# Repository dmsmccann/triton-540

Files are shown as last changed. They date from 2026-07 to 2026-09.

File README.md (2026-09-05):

# Ten-Tec Triton IV Model 540 reconstruction

This project recreates the Ten-Tec Triton IV Model 540 in KiCad, one original
assembly at a time. The schematics preserve the historical topology and
reference designators while adding project-local SPICE models, reproducible
simulation studies, and explicit documentation of estimated values.

## Documented assemblies

| Assembly | Function | Documentation and simulation evidence |
|---|---|---|
| 80166 | Receiver RF amplifier | [80166.md](80166.md) |
| 80289 | Internal VFO and frequency conversion | [80289.md](80289.md) |
| 80287 | Receive/transmit mixers | [80287.md](80287.md) |
| 80279 | 9 MHz IF, AGC, product detector, and audio preamplifier | [80279.md](80279.md) |
| 80274 | Audio power amplifier, transmit mute, and CW sidetone | [Schematic](80274_audio_power_amp.kicad_sch); manual pp. 3-18 and 3-19; simulation not yet implemented |

The 80287 study demonstrates conversion between a 3.499 MHz SSB spectral
component and the fixed 9.001 MHz IF in both directions. It includes settled
MC1496 service-voltage comparisons, receive/transmit product plots, and
separate sweeps of the two mixer-balance controls.

The 80279 study documents the complete IF-to-audio and AGC signal path. Its
completed work includes the receive DC operating-point comparison, estimated
two-stage 9 MHz IF response, and open-loop PIN-diode attenuation sweep;
product-detector, closed-loop timing, and S-meter studies remain explicitly
listed as future simulations.

## Simulation

The KiCad hierarchy is the circuit source of truth. Reproducible runners,
curated measurements, plots, and project-local models are under [`spice/`](spice/README.md).
Generated netlists and simulator caches are intentionally not versioned.

## Bench measurement

Measurements taken on real hardware live under [`bench/`](bench/README.md),
one directory per assembly. Simulation evidence and bench evidence are kept
apart so that a simulated result is never mistaken for a measured one.

The original Ten-Tec service manual is the primary source for this
reconstruction but is not redistributed in this repository.

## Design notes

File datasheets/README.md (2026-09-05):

# Archived component datasheets

This directory holds project-local copies of documentation for obsolete and
historical components used in the Ten-Tec Triton IV Model 540 reconstruction.
KiCad symbols should point to these local files so the design does not depend
on external links remaining available.

## RCA 40823

- Used by: `80166` receiver RF amplifier (Q1) and `80279` 9 MHz IF
  amplifier stages
- File: `RCA_40823_SC-15_1971.pdf`
- Manufacturer: RCA Corporation, Solid-State Division
- Document: *RCA Transistor, Thyristor & Diode Manual*, Technical Series SC-15
- Original publication: 1971
- Extracted pages: printed pages 386 through 388 (40821, 40822, and 40823
  electrical data) and printed page 670 (JEDEC TO-72, RCA outline No. 28)
- Note: RCA specifies the 40823 as identical to the 40821 except for the listed
  ratings and characteristics, and refers to the 40822 for typical curves.
- Archive source:
  <https://www.worldradiohistory.com/BOOKSHELF-ARH/Technology/RCA-Books/RCA-Transistor-Thyristor-%26-Diode-Manual-1971.pdf>
- Archived file SHA-256:
  `AC18E00AAA3F6D3BE2EAAB2780D9C1DC1EC17F6025724F54BAAE7D126BE33B09`

## MC1747 / MC1747C

- Used by: `80279` AGC and audio preamplifier
- File: `MC1747_MC1747C_Motorola_1976.pdf`
- Manufacturer: Motorola Semiconductor Products Inc.
- Document: MC1747 / MC1747C dual operational amplifier, document DS 9254
- Original publication: 1976 Motorola Semiconductor Data Library, Volume 6,
  Series B, *Linear Integrated Circuits*
- Extracted pages: printed pages 3-83 through 3-86 (four-page device sheet)
- Archive source:
  <https://www.bitsavers.org/components/motorola/_dataBooks/1976_Motorola_Semiconductor_Data_Library_Volume_6_Series_B_Linear_Integrated_Circuits.pdf>
- Archived file SHA-256:
  `D2F00DBC59EEE32FA07F4A339DD53DEB0EA124C4779C71F2E761D8EE11318594`

## 80274 audio power amplifier

These archives support the parts shown on manual PDF page 35 / printed page 3-19.
The manufacturer documents are primary evidence; the hosting sites are archives.
Later datasheet revisions are identified below and are not proof of the production
lot or package revision fitted to this radio. No substitute parts are assigned.

### MPSU01 (Q74-1)

- File: [Motorola_MPSU01_TechnicalData_undated.pdf](Motorola_MPSU01_TechnicalData_undated.pdf)
- Manufacturer: Motorola Semiconductor Products
- Document: *MPS-U01 / MPS-U01A NPN Silicon Audio Transistors, Semiconductor Technical Data*
- Original publication: Undated original; scan creation date is not the publication year
- Extracted pages: Both device pages; case 152-02 and E-B-C lead numbering appear on page 1
- Used by: assembly 80274, Q74-1
- Archive source: <https://datasheet4u.com/pdf/505844/MPSU01.pdf>
- Archived file SHA-256: 36074E59597EBAD8F55A46C62B235A8F31B9F6712FD52B6E3EC39E4E847FE000

### MPS6514 (Q74-3)

- File: [Motorola_MPS6514_DeviceData_undated.pdf](Motorola_MPS6514_DeviceData_undated.pdf)
- Manufacturer: Motorola Semiconductor Products
- Document: *MPS6512 through MPS6519 Amplifier Transistor*
- Original publication: Undated device page; package supplement from 1991 DL126 Rev. 3
- Extracted pages: Device printed page 2-204; appended package/style page 8-2 (PDF page 837) from 1991 DL126 Rev. 3. Style 1 is 1=E, 2=B, 3=C; the later case 29-04 outline is supplementary, while the device page specifies case 29-02
- Used by: assembly 80274, Q74-3
- Archive source: <https://datasheet4u.com/pdf/1115234/MPS6514.pdf>
- Package supplement source: <https://www.bitsavers.org/components/motorola/_dataBooks/1991_DL126r3_Motorola_Small-Signal_Transistors_FETs_and_Diodes.pdf>
- Archived file SHA-256: E9A2791869ED3FDE04CC2622717A615A8F2C78B47AEB910D0CD93B5A73E7CB82

### 2N4870 (Q74-2)

- File: [Motorola_2N4870_ThyristorDeviceData_undated.pdf](Motorola_2N4870_ThyristorDeviceData_undated.pdf)
- Manufacturer: Motorola Semiconductor Products
- Document: *2N4870 / 2N4871 PN Unijunction Transistors, Thyristor Device Data*
- Original publication: Undated device pages; package supplement from 1991 DL126 Rev. 3
- Extracted pages: Device printed pages 3-22 through 3-26; appended package/style page 8-2 (PDF page 837) from 1991 DL126 Rev. 3. Case 29 style 9 is 1=B1, 2=E, 3=B2
- Used by: assembly 80274, Q74-2
- Archive source: <https://datasheet.octopart.com/2N4870-Motorola-datasheet-180793037.pdf>
- Package supplement source: <https://www.bitsavers.org/components/motorola/_dataBooks/1991_DL126r3_Motorola_Small-Signal_Transistors_FETs_and_Diodes.pdf>
- Archived file SHA-256: 3FBFE4898E3A0DED2CEFB50942763706FAECF680F558580B240C8897FA77EA2A

### LM380N (U74-1)

- File: [National_LM380_DS006977_2000.pdf](National_LM380_DS006977_2000.pdf)
- Manufacturer: National Semiconductor
- Document: *LM380 2.5W Audio Power Amplifier, DS006977*
- Original publication: August 2000
- Extracted pages: Source PDF pages 2 through 8 (manufacturer device pages 1 through 7, including the N14A DIP-14 package); distributor cover and final notes page omitted
- Used by: assembly 80274, U74-1
- Archive source: <https://datasheet.octopart.com/LM380N-National-Semiconductor-datasheet-7275687.pdf>
- Archived file SHA-256: 2A93CBCC4B527A974060AC2FE1396408B5B9E5A819E0162A482459EF5F6C0398

### 1N4154 (D74-1)

- File: [Fairchild_1N4154_DiscretePowerAndSignal_1998.pdf](Fairchild_1N4154_DiscretePowerAndSignal_1998.pdf)
- Manufacturer: Fairchild Semiconductor
- Document: *1N4154 High Conductance Fast Diode, Discrete Power and Signal Technologies*
- Original publication: Revision A, September 21, 1998 (copyright 1997)
- Extracted pages: Source PDF page 1, including DO-35 dimensions and cathode band; trademark page omitted
- Used by: assembly 80274, D74-1
- Archive source: <https://www.sm0vpo.com/_pdf/1N/1N4154.pdf>
- Archived file SHA-256: 0F6607CE3231C1A442E40ED800AEFC8D2FCE1A501A83BF57C706B4C019EE583B

### D74-2: documented value, unidentified device

The manual specifies only an **8.2 V Zener**. Manufacturer, part number,
power rating, and package are unknown. Its placed-symbol Datasheet field
therefore remains blank; linking a named replacement would misrepresent the
source. Its Evidence field records this limitation.

### LM380N / ULN2280B choice

The manual explicitly lists LM380N / ULN2280B. The schematic represents the
documented LM380N alternative with all 14 physical pins. Pins 9 and 13 are
internal NCs; pins 3, 4, 5, 7, 10, 11 and 12 are grounded. The local symbol
changes the drawing arrangement, not the pinout. The ULN2280B is noted as a
manual alternative, not silently substituted or modeled.

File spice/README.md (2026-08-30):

# SPICE assets

This directory separates reusable simulation source from study evidence and
disposable simulator output.

| Directory | Contents | Versioned |
|:--|:--|:--:|
| [`models/`](models/) | KiCad-facing subcircuits and model documentation | Yes |
| [`validation/`](validation/) | Small standalone regression circuits | Yes |
| [`tools/`](tools/) | Study runners, shared ngspice helpers, and plotting utilities | Yes |
| [`studies/`](studies/) | Curated CSV evidence, manifests, fixtures, and figures | Yes |
| `generated/` | Exported netlists, ngspice raw files, logs, caches, and temporary CSVs | No |
| `runtime/` | Local ngspice executable and runtime dependencies | No |

The KiCad schematics are the circuit source of truth. The 80166 runner exports
a fresh SPICE netlist from `triton_540.kicad_sch` before applying run-specific
parameters to a generated copy.

Each study has its own runner named for the assembly it exercises. Helpers
that are genuinely board-independent — reading an ngspice ASCII raw file,
converting a voltage ratio to decibels, and measuring a swept response for its
peak, its −3 dB bandwidth and its sample spacing — live in `tools/ngspice_raw.py`,
which every runner imports. A runner named for one assembly never provides
infrastructure to another.

Where several studies exercise the same board, that board's netlist editing lives
in one place: `tools/run_80166_headless.py` holds the 80166's parameter,
component, source and model-parameter edits, and the four new 80166 study runners
import it.

## Common commands

Run ngspice 46 outside KiCad through the project launcher:

```powershell
Push-Location spice\validation
& ..\tools\ngspice.cmd -b -D ngbehavior=ltpsa 40823_validation.cir
Pop-Location
```

The launcher prefers `spice/runtime/ngspice-46/bin/ngspice_con.exe`, then
checks `C:\Tools\ngspice-46\Spice64\bin` and `PATH`. The local runtime is
intentionally excluded from Git; simulation source and results remain
independently curated.

Check the project tools, KiCad exports, model regressions, and scanned-manual
toolchain without modifying source schematics:

```powershell
pwsh -File spice\tools\run_project_preflight.ps1
```

The preflight writes disposable BOMs, logs, rendered pages, and OCR output
below `spice/generated/preflight/`. Use `-SkipKicad`, `-SkipSpice`, or
`-SkipPdf` to omit a group.

Regenerate the documented 80166 figures:

```powershell
python spice\tools\plot_80166_manual_alignment.py
```

Run the 80166 studies from fresh KiCad exports. Each one exports the netlist,
applies its own state, runs ngspice, and rewrites its curated CSVs and figures:

```powershell
python spice\tools\run_80166_operation.py            # 3.5 MHz normal operation
python spice\tools\run_80166_defeat_gain.py          # DEFEAT gain reduction
python spice\tools\run_80166_rf_gain_supply.py       # RF GAIN as the stage supply
python spice\tools\run_80166_trap_9mhz.py            # 9 MHz trap
python spice\tools\run_80166_loading_sensitivity.py  # output loading and coil Q
```

The root schematic can only usefully simulate one assembly at a time. These
runners need the `RF_Amp_80166` sheet included in simulation and the other three
sub-sheets excluded, which is how `triton_540.kicad_sch` currently stands; a
runner stops with a clear message if the export contains no 80166 nets.

Run the 80287 receive/transmit conversion study and both mixer-balance sweeps:

```powershell
python spice\tools\run_80287_operation.py
python spice\tools\run_80287_rx_balance.py
python spice\tools\run_80287_tx_balance.py
```

Regenerate the settled 80287 MC1496 DC pin-voltage regression:

```powershell
python spice\tools\run_mc1496_dc_regression.py
```

Regenerate the 80289 frequency-plan and ten-meter alignment evidence from
fresh KiCad exports:

```powershell
python spice\tools\run_80289_frequency_plan.py
python spice\tools\run_80289_filter_ac_response.py
python spice\tools\run_80289_filter_response.py
python spice\tools\run_80289_output_loading.py
python spice\tools\run_80289_mixer_balance.py
python spice\tools\run_80289_crystal_injection.py
python spice\tools\run_80289_ten_meter_alignment.py
```

Run the final 29 MHz validation from a fresh KiCad export:

```powershell
python spice\tools\run_80166_headless.py `
  --tag final-29mhz-validation `
  --s4-pos 5 `
  --l-rack 1.4253u `
  --start 28.97Meg `
  --stop 29.03Meg `
  --points-per-decade 150000 `
  --set-component C13=5.787p
```

Generated output is written below `spice/generated/` and is intentionally
excluded from Git.

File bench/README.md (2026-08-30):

# Bench measurements

Measurements taken on real hardware, as opposed to the simulation evidence
under [`../spice/`](../spice/README.md). One directory per assembly, named by
its Ten-Tec assembly number.

| Assembly | Radio | Measurement | Status |
|---|---|---|---|
| [`80166/`](80166/) | Triton IV Model 540 | Receiver RF amplifier L1/L2 tracking on 80 m | Procedure written, sweeps not yet captured |
| [`80350/`](80350/) | **Model 544** | VFO mixer-balance adjustment of `R2 MIXER BAL.` | Complete |

The 80350 VFO belongs to a Ten-Tec Model 544, not to the Model 540 this
project reconstructs. It is kept here because the measurement technique and
instruments are the same, but its results are not evidence about the 540.

Each assembly directory holds its own procedure `README.md`, the capture and
plotting scripts, a `data/` directory holding the captured runs as the
measurement record, and a `plots/` directory for generated figures. Captured
data and plots are deliberately versioned; only tooling caches are ignored.

## Instrument control

The 80166 scripts drive a Siglent SDG1032X generator and SDS1202X-E
oscilloscope over LAN, using SCPI over VXI-11 through `pyvisa` + `pyvisa-py`,
so no NI-VISA installation is required:

```powershell
python -m pip install pyvisa pyvisa-py matplotlib
```

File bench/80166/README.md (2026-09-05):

# 80166 rf amplifier — L1/L2 tracking check on 80 m

Swept-frequency measurement of the receiver rf amplifier in the Ten-Tec Triton IV
Model 540, using a Siglent SDG1032X function generator and an SDS1202X-E
oscilloscope under Python control over LAN.

The point of the measurement is the one the factory alignment cares about: **do L1
and L2 peak at the same frequency as the RESONATE rack moves across 80 m?** The
manual sets tracking on this band only (p. 3-8, PDF p. 24) — the 3.5 MHz trimmer
and the L2 slug are the two adjustments, and the higher bands get trimmer-only
touch-ups afterwards with "no further adjustment of L2 necessary".

## How the two coils are separated

L1 (input) and L2 (output) sit either side of Q1, so a single sweep from the
antenna jack to the stage output shows the product L1 × Q1 × L2, not the two peaks
individually. The manual's own alignment trick splits them: the `.01 µF` clipped
from the band's trimmer terminal to chassis shorts the trimmer that sits **across
L2**, swamping the output tank.

| Run | `.01 µF` on the 3.5 MHz trimmer terminal | Curve shows |
|---|---|---|
| `l1-only` | fitted | L1 alone |
| `composite` | removed | L1 × Q1 × L2 |

On 3.5 MHz that trimmer is **C19**; the L1 side of the stage carries the fixed
620 pF C12 instead. The split — fixed capacitors across L1, adjustable trimmers
across L2 — is what makes this work, and is set out per band in
[`../../80166.md`](../../80166.md).

Overlay the two and the offset between their peaks is the tracking error.

> The manual writes this cap as ".01 mF". In 1978 US usage `mF`/`mfd` means
> **microfarad**; it is 0.01 µF, not a typo.

## Instruments

| Instrument | Address | Role |
|---|---|---|
| Siglent SDG1032X | `192.168.1.158` | stimulus, CH1 output |
| Siglent SDS1202X-E | `192.168.1.157` | CH1 = drive reference, CH2 = stage output |

Control is SCPI over VXI-11 via `pyvisa` + `pyvisa-py`, so no NI-VISA install is
needed:

```powershell
python -m pip install pyvisa pyvisa-py matplotlib
```

If VXI-11 gives trouble, `--transport socket` falls back to raw TCP
(scope 5025, generator 5024).

## Connections

Generator and scope CH1 both land on the antenna jack — that single node is where
the drive has to be measured. A BNC tee is the tidy way to do it, but tapping the
jack at two physical points works just as well at 3.5 MHz and needs no tee:

```text
  SDG1032X CH1 ──clip leads── SO-239 centre solder lug   (inside the rear apron)
                 (short, run together, ground clip to
                  chassis right at the jack)

  scope CH1 ──short coax──── 540 ANTENNA jack (SO-239)   1x direct, no probe

  scope CH2 ── x10 probe ── 80166 OUT pin                ground clip to nearest
                            (or 80287 "Rx In")           chassis point, short lead
```

- **Measure the drive, don't assume it.** The receiver input is not a flat 50 Ω
  across the sweep, so CH1 has to see the voltage that actually reaches the jack.
  That ratio is what makes the result a true transfer function.
- **Clip leads are fine here.** A few inches is about 100 nH, roughly 2 Ω at
  3.5 MHz against a 50 Ω source. Do not carry this arrangement up to 28 MHz.
- **Keep the CH1 coax short.** It is an unterminated stub into the scope's 1 MΩ
  input, so it hangs its own capacitance across the antenna input — RG-58 is
  about 100 pF/m. See the loading note below.
- **CH1 is a direct coax feed**, so run the script with `--ch1-attn 1` (the
  default). CH2 uses a ×10 probe, `--ch2-attn 10` (also the default). A ×10 probe
  on CH1 would load less but divides the 10 mVpp reference down to two divisions
  on screen; the direct feed gives a much cleaner reference and is the better
  trade.
- **Do not disturb the hookup between the two sweeps.** Same cable, same clip
  positions, same routing for `l1-only` and `composite`.
- **CH2 pickup point.** The 80166 `OUT` pin goes to `S4B` and on to the TX-RX
  mixer. The `Rx In` pin on the 80287 plug-in socket is the same net and is
  usually easier to reach. Access to the rf amp itself is on the RESONATE
  subchassis with the rack plate off (Figure 1, p. 3-6).
- The 9 MHz trap T1/C7 is in the input path but is irrelevant at 3.5–4.0 MHz.

### Transceiver settings

| Control | Setting |
|---|---|
| Antenna | **disconnected** — the generator is on that jack |
| T/R-REC switch | **T/R** |
| BAND | 3.5 MHz |
| MODE | SB-N, receive, PTT open, key up |
| RF GAIN | **fully clockwise** (this is the supply to the stage) |
| CALIBRATE | **OFF** — the calibrator's TTL gate pulls DEFEAT low and drops stage gain ~25 dB |
| Blanker | off |
| RESONATE | continuous and unmarked; peak it as described below, then **do not touch it** for the rest of that pair of sweeps |

> **Do not transmit.** The generator is connected to the antenna jack; keying the
> transmitter will destroy the SDG output stage. Keep the unit in receive
> throughout, key unplugged, mic unplugged.

## Run order

The RESONATE position is part of the measurement — L1 and L2 are ganged to the
same rack, so the sweep only tells you about tracking at the physical rack
position you left it in. The front-panel control has no scale or detents, so do
not try to record a dial setting; take both sweeps of a pair without moving it.

1. Clip the `.01 µF` from the 3.5 MHz trimmer terminal — C19, on the small
   trimmer board beneath the amplifier board, Figure 2, p. 3-7 — to chassis.
2. Set RESONATE for peak response at 3.5 MHz. Easiest way is to run a quick
   coarse sweep and adjust until the peak lands on 3.5 MHz:

   ```powershell
   python bode_80166.py --label l1-only --points 61 --note "RESONATE set for 3.5 MHz peak"
   ```

3. When the peak is on 3.5 MHz, take the reference sweep at full resolution:

   ```powershell
   python bode_80166.py --label l1-only --note "RESONATE at 3.5 MHz peak, .01uF fitted"
   ```

4. Remove the `.01 µF`. **Leave RESONATE alone.** Take the composite sweep:

   ```powershell
   python bode_80166.py --label composite --note "RESONATE unchanged, .01uF removed"
   ```

5. Overlay them:

   ```powershell
   python plot_bode.py data/80166-80m-l1-only-*.csv data/80166-80m-composite-*.csv
   ```

If the composite peak is off 3.5 MHz, adjust the **3.5 MHz trimmer C19** and repeat
step 4. The 4.0 MHz end of the tracking is then set with the **L2 slug** — repeat
the whole pair with RESONATE peaked at 4.0 MHz instead, and adjust the slug rather
than the trimmer. Iterate the two ends as the manual's step 6 says, since each
interacts with the other.

## Reading the result

- **Tracking well** — the composite peak sits on the L1 peak, the composite curve
  is a single symmetric hump, and its peak gain is the highest you can obtain by
  touching the trimmer.
- **Mistracked** — the composite peak is offset from L1's, or the curve is
  broad/flat-topped/double-humped, and peak gain is down. The sign of the offset
  tells you which way to move the trimmer or slug.

`plot_bode.py` reports peak frequency, −3 dB bandwidth, loaded Q, the gain at each
alignment point, and the peak offset between the two curves.

## Measurement notes and limits

- **Drive level.** Default is 10 mVpp, which is ~60 dB above what this front end
  normally sees, chosen so the output clears the scope's noise floor. The script
  runs a linearity check first: it measures gain at full and half drive and warns
  if they differ by more than 0.5 dB, which means Q1 is compressing and the curve
  shape is lying. Reduce `--amplitude` until it passes.
- **Probe loading.** A ×10 probe adds roughly 10–15 pF at the output node. On 80 m
  that is small against the several hundred pF resonating L2, so the shift is
  tolerable — this is exactly why the check is worth doing on this band and not on
  28 MHz, where the same 10 pF would dominate. Confirm the final peak with the
  manual's audio-AC-meter method if you want the probe out of circuit.
- **Dynamic range.** At the scope's most sensitive setting the usable range is
  roughly 30–35 dB below the peak before the skirts sink into the noise. The
  script records the CH2 noise floor with the generator output off in the CSV
  header so you can see where the data stops being meaningful.
- **Amplitude only.** Phase is not recorded. Tracking is an amplitude question and
  leaving phase out removes a large source of measurement fragility.
- The scope's 20 MHz bandwidth limit is enabled by default to cut noise;
  `--no-bwl` turns it off.

## Files

| File | Purpose |
|---|---|
| `bode_80166.py` | runs one sweep, writes a timestamped CSV to `data/` |
| `plot_bode.py` | overlays CSVs, writes a PNG to `plots/`, prints the summary table |
| `data/` | captured sweeps, one CSV per run, kept as the measurement record |
| `plots/` | generated figures |

CSV columns are `frequency_hz, ch1_vpp, ch2_vpp, gain_db`, preceded by `#`
comment lines carrying the run label, instrument IDNs, drive level, sweep
settings, measured noise floor, linearity result and the free-text `--note`.

## Results

Not yet captured — this section will be filled in with the overlay plot and the
summary table once the sweeps have been run on the bench.

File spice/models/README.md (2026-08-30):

# SPICE model reference

## MC1747 dual operational amplifier

`MC1747.sub` contains a five-terminal Motorola-style MC1747 op-amp core and
a project-added fourteen-pin package wrapper. The wrapper instantiates the
core twice, preserving the device's separate positive supplies and common
negative supply:

```spice
XU inv_a noninv_a off_a1 vee off_b1 noninv_b inv_b off_b2 vcc_b out_b nc out_a vcc_a off_a2 MC1747
```

Use a one-to-one physical-pin mapping in KiCad:

| Pin | Function | Pin | Function |
|---:|---|---:|---|
| 1 | Inverting input A | 8 | Offset adjust B |
| 2 | Noninverting input A | 9 | VCC B |
| 3 | Offset adjust A | 10 | Output B |
| 4 | VEE, common | 11 | NC |
| 5 | Offset adjust B | 12 | Output A |
| 6 | Noninverting input B | 13 | VCC A |
| 7 | Inverting input B | 14 | Offset adjust A |

The `triton_iv:MC1747` symbol already selects
`${KIPRJMOD}/spice/models/MC1747.sub`, subcircuit `MC1747`, with physical
pins 1 through 14 mapped one-to-one.

### Model basis and limits

The five-pin core was extracted from the local KiCad-Spice-Library file
`Models/uncategorized/spice_complete/MOTOR.LIB`, whose source tag identifies
the entry as a Motorola internally compensated MC1747 model. The same
electrical core appears as `MC1747` in the Bordodynovs `OPAMPS.LIB` and as
`MC1747_MC` in `m_opamp.lib`.

The source core models one amplifier only. The project modification renames
it `MC1747_CORE`, instantiates it once for section A and once for section B,
and adds high-value stabilization resistors to the four offset-adjust pins
and pin 11. Consequently, offset-null adjustment is not modeled. DC bias,
closed-loop gain, bandwidth, slew rate, output limiting, input bias current,
and supply loading are modeled nominally; noise, device spread, temperature
variation, and inter-section coupling are not validated.

`../validation/MC1747_validation.cir` checks both sections on separate 13.8 V
positive-supply pins. Its unity-follower regression gives 6.80002 V and
7.00002 V DC outputs, approximately 1.595 MHz closed-loop bandwidth, and
0.498 V/us large-signal slew rate under ngspice 46.

The source aggregator's README states that its GPLv3 license covers its
scripts, not the collected model files, and it does not establish the license
of this individual model. Treat `MC1747.sub` as a local simulation asset and
review or replace it before including it in a public release.

### References

- Ten-Tec, *Triton IV Model 540 Owner's Manual*, local PDF page 32 / printed
  page 3-16: the two IC-1 amplifier functions on assembly 80279.
- Same manual, local PDF page 33 / printed page 3-17: IC-1 connections and
  operating-point voltages.
- `datasheets/MC1747_MC1747C_Motorola_1976.pdf`, printed pages 3-83 through
  3-86: package pinout and electrical characteristics.

## 80279 discrete active-device models

`MPS3693.lib` is an empirical NPN model for Q79-1 and Q79-2. No factory
SPICE model was found. Its constraints are the surviving 45 V voltage
ratings, 30 mA collector-current rating, minimum gain of 40, approximately
200 MHz transition frequency, and approximately 3.5 pF collector
capacitance. `BF=60` was selected as a nominal value compatible with the
manual's approximately 1.3 mA and 5 mA emitter-current operating points.
The model is intended for 9 MHz bias and small-signal studies, not noise,
distortion, breakdown, temperature, or production-spread predictions.

`HP5082_3379.sub` is an empirical two-terminal PIN-diode model for D79-1,
D79-2, and D79-3. Its external order follows the KiCad diode symbol:

```spice
XD cathode anode HP5082_3379
```

The model uses the HP/Agilent data-sheet values of 50 V minimum breakdown,
0.4 pF maximum total capacitance at 50 V, 1.3 us typical carrier lifetime,
and typical Outline-15 package parasitics of 2.5 nH and 0.13 pF. A
low-pass-controlled behavioral resistance follows the documented
current-controlled RF resistance without following the 9 MHz carrier. Its
8 mV/current relationship gives approximately 1000 ohms at 10 uA and 8 ohms
at 1 mA; this is an engineering interpolation, not an HP compact model.

`../validation/80279_device_models_validation.cir` gives nominal ngspice 46
results of beta 55.4 for MPS3693 at 50 uA base drive. In the documented
80279 bias networks it gives Q79-1 C/B/E = 13.64/1.046/0.362 V and Q79-2
C/B/E = 13.32/1.788/1.070 V, compared with manual readings of
13.7/1.0/0.3 V and 13.3/1.8/1.1 V. The PIN-diode impedance magnitudes are
802 ohms, 8.22 ohms, and 0.611 ohm at 9 MHz for 10 uA, 1 mA, and 20 mA
forward bias respectively.

The existing `MPS6514.lib` model is assigned to Q79-4, Q79-5, and Q79-6.
The existing `40823.sub` model is assigned to Q79-3 with one-to-one physical
pin order `D, G2, G1, S`. The complete assignments are stored directly in
`80279_if_agc.kicad_sch` so KiCad exports all required includes.

### References

- Ten-Tec, *Triton IV Model 540 Owner's Manual*, local PDF pages 32-33 /
  printed pages 3-16 to 3-17: circuit functions and no-signal voltages.
- HP/Agilent, *PIN Diodes for RF Switching and Attenuating*, technical data
  5968-7182E: 5082-3379 capacitance, lifetime, breakdown, package parasitics,
  and RF-resistance behavior.

## MC1496P balanced modulator

`MC1496P.sub` is a nominal transistor-level model for the MC1496P
double-balanced mixers used as U89-1 in VFO assembly 80289 and U87-1/U87-2
in TX-RX mixer assembly 80287.
It implements the onsemi internal topology: a four-transistor upper switching
quad, a two-transistor signal stage, two emitter-degenerated current-source
transistors, and the bias diode. The bias diode is represented electrically by
a diode-connected NPN. Figure 23 shows three internal 500 ohm resistors.

The subcircuit exposes all fourteen physical package pins:

```spice
XU signal+ gain1 gain2 signal- bias output+ nc carrier+ nc carrier- nc output- nc vee MC1496P
```

Use a one-to-one physical-pin mapping in KiCad:

| Pin | Function | Pin | Function |
|---:|---|---:|---|
| 1 | Signal input + | 8 | Carrier input + |
| 2 | Gain adjust | 9 | NC |
| 3 | Gain adjust | 10 | Carrier input - |
| 4 | Signal input - | 11 | NC |
| 5 | Bias | 12 | Output - |
| 6 | Output + | 13 | NC |
| 7 | NC | 14 | VEE |

In KiCad Simulator, associate U89-1 with a **Subcircuit** model, browse to
`${KIPRJMOD}/spice/models/MC1496P.sub`, select `MC1496P`, and map physical
pins 1 through 14 one-to-one. The four NC pins are accepted by the subcircuit
but intentionally unused internally.

### Model basis and limits

- The topology and internal 500 ohm resistors are documented in onsemi
  MC1496/D Figure 23.
- The transistor beta, Early voltage, and capacitance terms are engineering
  fits to the data sheet's typical 12 uA input bias current, 40 kohm output
  resistance, 5 pF output capacitance, and published RF response. They are not
  a recovered Motorola semiconductor-process model.
- A fixed 0.2 percent mismatch in one switching transistor makes the external
  mixer-balance control produce a finite null. This is a nominal simulation
  device mismatch, not a measured value for U89-1.

The model is intended for DC bias, conversion-gain trends, carrier balance,
injection-level studies, wanted/unwanted mixing products, and loading of the
80289 output filters from 5 to 21 MHz. It is not validated for absolute noise,
unit-to-unit spread, temperature drift, exact intercept points, or carrier
feedthrough caused by physical PCB coupling.

The settled schematic-native 80287 DC regression passes 33 of the 40 connected-
pin/mode checks against the manual's stated 15 percent service tolerance. All
U87-1 transmit points and every U87-2 point pass. Seven U87-1 receive points
remain outside tolerance, while its two collector voltages pass. Because the
same model reproduces U87-2 pin 5 but cannot simultaneously reproduce the
documented U87-1 pin-5 value with the drawn R87-3 network, no global transistor
parameter was fitted to those seven points. Absolute gain, balance, and
feedthrough remain unvalidated.

`../validation/MC1496P_validation.cir` checks DC operating current and
5 MHz by 8 MHz mixer action with 3 MHz and 13 MHz differential outputs, then
repeats at a 15 MHz carrier to check 10 MHz and 20 MHz products near the top
of the 80289 operating range.

`../tools/run_mc1496_dc_regression.py` exports the complete KiCad hierarchy,
allows the 80287 bias capacitors to settle for 500 us, and compares all 40
documented U87-1/U87-2 operating points. Add `--strict` when a nonzero exit is
desired for any out-of-tolerance manual point.

### References

- Ten-Tec, *Triton IV Model 540 Owner's Manual*, local PDF page 29 / printed
  page 3-13: U89-1 circuit connections and external bias network.
- Same manual, local PDF pages 27-28 / printed pages 3-11 to 3-12:
  mixer-balance, crystal-injection, and output-filter alignment.
- onsemi, [MC1496/MC1496B data sheet](https://www.onsemi.com/download/data-sheet/pdf/mc1496-d.pdf):
  pinout, internal circuit, operating equations, test circuits, impedance,
  frequency response, and mixer applications.

## TX-RX mixer 80287 magnetics

`80287_txrx_magnetics.lib` contains `TXRX_L2_CT`, the simulation starting
model for the center-tapped transmit-output transformer L87-2. It uses two
10 uH halves, 1 ohm winding resistance in each half, coupling `K=0.98`, and
2 pF end-to-end capacitance.

The Ten-Tec manual shows the winding topology but supplies none of those
quantities. They are explicit estimates chosen to make the schematic runnable,
not recovered factory specifications. L87-2 needs measurement or original
winding information before the model can support absolute output-level or
balance claims.

The receive load L87-3 is represented directly in the schematic as 2 uH. This
is the rounded result of resonating the documented C87-5 value of 150 pF at
9 MHz (2.08 uH before transistor, board, and winding capacitance). L87-1 is a
1 uH inferred starting value and likewise remains unverified.

## RCA 40823 dual-gate MOSFET

`40823.sub` is an empirical four-terminal macro-model for the RCA 40823
protected dual-gate N-channel depletion MOSFET used as Q66-1 in the Triton 540
RF amplifier.

The subcircuit call is:

```spice
XQ drain gate2 gate1 source RCA40823
```

The custom project symbol is drawn using pin positions that do not correspond
to its displayed pin names.  For the existing `80166_rf_amp.kicad_sch`
connections, map the symbol pins to the subcircuit as follows:

| KiCad symbol pin | Circuit terminal | Subcircuit node |
|---:|---|---:|
| 1 | Drain | 1 |
| 3 | Gate 2 / DEFEAT bias | 2 |
| 4 | Gate 1 / tuned-input tap | 3 |
| 2 | Source / R6-C5 | 4 |

In KiCad Simulator, select Q66-1, choose a **Subcircuit** model, browse to
`${KIPRJMOD}/spice/models/40823.sub`, select `RCA40823`, and use the mapping
`1=1 2=4 3=2 4=3` already stored on Q66-1.  This produces the subcircuit
order drain, gate 2, gate 1, source.

### Model basis and limits

No RCA factory SPICE model was found. The DC and capacitance targets are based
on published 3N204/NTE222 data, a documented close replacement for the 40823:
6-30 mA IDSS, 10-22 mS forward transfer admittance, 3.3 pF typical input
capacitance, 0.005-0.03 pF reverse transfer capacitance, and 1.4 pF typical
output capacitance at the stated test biases.

This nominal model is intended for bias checks, gain-control trends, and
small-signal work across the Triton's 2-30 MHz receiver range. It is not
validated for noise figure, strong-signal IMD, temperature extremes,
manufacturing spread, or VHF/UHF S-parameters. Measurements from an original
40823 would be required to fit those behaviors.

`../validation/40823_validation.cir` provides standalone ngspice DC transfer
sweeps.

### References

- Ten-Tec, *Triton IV Model 540 Owner's Manual*, local PDF page 25 / printed
  page 3-9: Q1 identity, D/G2/G1/S pin order, and receive/transmit voltages.
- NTE Electronics, [NTE222 datasheet](https://www.tme.eu/Document/55128e117c9002a9dd7c0a2ab56da1a3/nte222.pdf):
  DC limits, forward transfer admittance, capacitances, and protected-gate
  characteristics.
- Motorola, [3N204/3N205 data](https://www.tvsat.com.pl/pdf/3/3n204-5_mot.pdf):
  depletion-mode topology and matching DC/RF characteristic limits.

## RF-amplifier magnetics

`80166_rf_magnetics.lib` supplies three parameterized ngspice
subcircuits:

| Model | Pins | Default starting values |
|---|---|---|
| `80166_L1` | band end, RF ground, antenna tap, G1 tap | 2.2 uH full winding, 6 pF parasitic |
| `80166_L2` | DC end, band end, output tap, drain tap | 2.2 uH full winding, 6 pF parasitic |
| `80166_T1_9MHZ` | primary A/B, secondary A/B | 0.35 uH : 12.5 uH, K=0.35 |

L1 and L2 are both modeled as strongly coupled series sections, not as
isolated transformer windings.  This preserves their continuous
double-tapped-winding topology while allowing every schematic tap to be
connected.

The L1/L2 `LT` parameter is the full-winding value at the current RESONATE
control position.  Use 2.2 uH as a nominal starting point and sweep about
1.7-3.3 uH.  The T1 defaults resonate near 9 MHz when the external C7 is about
20 pF; its 5 pF default `CPS` parameter represents estimated secondary,
wiring, and socket capacitance.

Example explicit instances are:

```spice
X_L1 band_end 0 ant_tap g1_tap 80166_L1 params: LT=2.2u
X_L2 dc_end band_end out_tap drain_tap 80166_L2 params: LT=2.2u
X_T1 primary_a primary_b secondary_a secondary_b 80166_T1_9MHZ
```

In KiCad Simulator, associate each custom symbol with a **Subcircuit** model,
browse to `${KIPRJMOD}/spice/models/80166_rf_magnetics.lib`, select the matching
subcircuit, and use a 1:1 model-pin mapping:

| Reference | KiCad/model pin 1 | Pin 2 | Pin 3 | Pin 4 |
|---|---|---|---|---|
| L66-1 / L1 | band/S4A | RF ground | antenna/T1 tap | C2/G1 tap |
| L66-2 / L2 | DC/C6 end | band/S4B | OUT tap | drain/gimmick tap |
| T66-1 / T1 | primary A | primary B | secondary A | secondary B |

### Evidence and limitations

- Ten-Tec, *Triton IV Model 540 Owner's Manual*, local PDF page 24 / printed
  page 3-8: L1/L2 slug tuning, mechanical ganging, and T1/C7 trap function.
- Same manual, local PDF page 25 / printed page 3-9: winding and tap topology.
- Same manual, local PDF page 21 / printed page 3-4: L1 band capacitors of
  620, 220, 56, 22, and 10 pF and five 5-60 pF L2 trimmers.

The manual does not document inductance, turns, tap ratios, coupling, Q, or
parasitic capacitance.  The model defaults are calculated/inferred starting
values, not Ten-Tec specifications.  Refine `LT`, tap fractions, `KTRAP`,
`QP`/`QS`, and parasitics from an original assembly or a measured response.
`../validation/80166_rf_magnetics_validation.cir` is a standalone AC fixture
for syntax and trap-response checks. The complete manual-alignment study is
documented in `../studies/80166/manual-alignment/`.

## Ganged S4A/S4B five-position rotary switches

`SW_Rotary_1x5.sub` is a parameter-selected SP5T model used by both the S4A
and S4B bandswitch wafers.  Each instance has the following pin order:

| Model pin | Switch terminal |
|---:|---|
| 1-5 | Five stationary contacts |
| 6 | Common/wiper |

The model uses a 20 milliohm resistance for the selected contact and 1 teraohm
for each unselected contact.  These are stable simulation defaults, not
measurements of the original switch.  Contact capacitance, inductance,
break-before-make motion, and contact bounce are not modeled.

In KiCad, associate both wafers with a **Subcircuit** model, browse to
`${KIPRJMOD}/spice/models/SW_Rotary_1x5.sub`, select `SW_ROTARY_1X5`, and map pins
1 through 6 one-to-one.  Both model instances use the same parameter:

```spice
POS={S4_POS}
```

The top-sheet SPICE directive is:

```spice
.param S4_POS=1
```

Change the integer from 1 through 5 to select a contact, then rerun the
simulation.  Because S4A and S4B reference the same parameter, both wafers
move together.  The present S4A drawing maps the switch contacts as:

| `S4_POS` | Band label | Capacitor |
|---:|---:|---:|
| 1 | 3.5 MHz | 620 pF |
| 2 | 7 MHz | 220 pF |
| 3 | 14 MHz | 56 pF |
| 4 | 21 MHz | 22 pF |
| 5 | 28 MHz | 10 pF |

The S4B output networks use C19, C17, C16, C15, and the C13-C14 series pair.
Their fitted simulation values and the distinction between documented
trimmer range and inferred parasitics are recorded in the manual-alignment
study rather than in this model description.

`../validation/SW_Rotary_1x5_validation.cir` instantiates the model in all
five positions and checks that only the selected throw conducts.

## Ganged S89-1 four-pole, five-position VFO bandswitch

`SW_Rotary_4x5.sub` models the four mechanically linked wafers of S89-1 as
one 24-pin subcircuit.  Its pins map one-to-one to the project-local symbol:

| Model pins | VFO switch terminals |
|---:|---|
| 1-5, 6 | A1-A5, A common |
| 7-11, 12 | B1-B5, B common |
| 13-17, 18 | C1-C5, C common |
| 19-23, 24 | D1-D5, D common |

All four wafers use the same `POS` parameter.  The S89-1 schematic instance
passes `POS={S4_POS}`, so the root-sheet directive that controls S4A and S4B
also controls the VFO bandswitch:

| `S4_POS` | Amateur band | Nominal band frequency |
|---:|---:|---:|
| 1 | 80 m | 3.5 MHz |
| 2 | 40 m | 7 MHz |
| 3 | 20 m | 14 MHz |
| 4 | 15 m | 21 MHz |
| 5 | 10 m | 28 MHz |

The model uses the same 20 milliohm selected-contact resistance and 1 teraohm
unselected-contact resistance as the S4 model.  It does not model contact
parasitics, break-before-make motion, or contact bounce.

`../validation/SW_Rotary_4x5_validation.cir` checks every wafer in all five
positions.

## S5 four-position ten-meter segment switch

`SW_Rotary_1x4.sub` models the top-sheet S5 SP4T selector. Model pins 1–4
map one-to-one to the four crystal contacts and pin 5 is the common/wiper
connected to the VFO sheet's `S5` input. The schematic instance passes:

```spice
POS={S5_POS}
```

The root-sheet directive defaults to `.param S5_POS=1`. Positions 1–4 select
Y1 through Y4:

| `S5_POS` | Dial segment | Ideal source |
|---:|:--|--:|
| 1 | 28.0–28.5 MHz | Y1, 13.99 MHz |
| 2 | 28.5–29.0 MHz | Y2, 14.49 MHz |
| 3 | 29.0–29.5 MHz | Y3, 14.99 MHz |
| 4 | 29.5–30.0 MHz | Y4, 15.49 MHz |

The four frequencies are the documented 10 kHz-low crystal plan combined
with the band-dependent PTO correction. Y1–Y4 are functional ideal sine
sources with 2.2 V DC bias and 1 V peak amplitude, matching the ideal-source
convention used for Y89-1 through Y89-3. They do not model crystal startup,
motional parameters, loading, or production tolerance.

The switch uses 20 milliohms for the selected contact and 1 teraohm for each
unselected contact. These are stable simulation defaults, not measurements.
`../validation/SW_Rotary_1x4_validation.cir` checks all four positions.

## Fixed-position potentiometer

`Potentiometer_Position.sub` represents a three-terminal linear
potentiometer at a fixed simulation setting. Its model pins are terminal 1,
wiper 2, and terminal 3. The instance parameters are:

```spice
R=1k POS=0.5
```

`POS=0` places the wiper at terminal 1 and `POS=1` places it at terminal 3.
A 1 milliohm minimum segment resistance avoids a zero-ohm branch at either
endpoint.

The 80289 schematic uses this model only for the two alignment controls.
R89-2 has `POS={VFO_R2_POS}`, with the saved
`.param VFO_R2_POS=0.760`; R89-27 has `POS={VFO_R27_POS}`, with the saved
`.param VFO_R27_POS=0.100`. The dedicated mixer-balance sweep places the
R89-2 minimum at 0.760. The crystal-injection sweep retains R89-27 at 0.100
as an inferred compromise, but the simplified model does not reach the
manual's 200 mV minimum throughout the T1 range. These are simulation-aligned
estimates obtained in the manual's adjustment order, not measured production
settings. The ordinary schematic resistance and three-terminal topology are
preserved.

`../validation/Potentiometer_Position_validation.cir` checks the wiper at
positions 0.25, 0.50, and 0.75.

## MV2201 varactors

`MV2201.lib` contains the junction-capacitance diode model used by D89-2 and
D89-3 in the 80289 PTO.  The electrical parameters were imported from
`Models/Diode/DIODE2.lib` in the local KiCad-SPICE-Library:

```spice
.model MV2201 D(Is=1.365p Rs=1 Cjo=14.93p M=.4261 Vj=.75 Isr=16.02p Nr=2 Bv=25 Ibv=10u)
```

The source library's `Vpk`, `mfg`, and `type` fields are metadata not
recognized as ngspice diode parameters; the project-local file records them
in comments but omits them from the active model statement.

Both schematic symbols retain the KiCad pin mapping `1=K 2=A`.  KiCad
therefore emits the SPICE diode nodes in anode-cathode order.  The model
captures nominal reverse-bias capacitance and series resistance, but its
provenance as an original Motorola/OnSemi factory model has not been
established.  Do not treat it as evidence of production spread, temperature
drift, package parasitics, or measured behavior of the installed parts.

`../validation/MV2201_validation.cir` checks the nominal small-signal
capacitance at 0, 2, 8, and 12 V reverse bias.

## 2N5486 N-channel JFETs

`2N5486.lib` contains the model used by Q89-1 and Q89-3 in VFO assembly
80289.  Its parameters were imported from the `2N5486/PLP` entry in the
local KiCad-SPICE-Library's `spice_complete/phil_fet.lib`; the model name was
changed to `2N5486` for portable KiCad/ngspice use, without changing its
electrical parameters.

The plain `2N5486` and `2N5486X` entries elsewhere in that library use
`BETA=4m` and `VTO=-4 V`, implying a much higher zero-bias drain current.
The selected Philips-family entry uses `BETA=832.666u` and `VTO=-3.847 V`,
giving a nominal IDSS near 12 mA, consistent with the 2N5486 device family
and the VFO's documented Q89-1 bias.

Both KiCad symbols use `Device:Q_NJFET_DSG`:

| KiCad pin | Function | SPICE JFET node |
|---:|---|---|
| 1 | Drain | D |
| 2 | Source | S |
| 3 | Gate | G |

The model is useful for nominal DC bias, oscillator startup, buffer loading,
and RF gain trends.  Its provenance as an original factory model has not
been independently established, and it does not represent the broad
production spread normally associated with discrete JFET IDSS and cutoff
voltage.

`../validation/2N5486_validation.cir` checks IDSS, cutoff trend, and a
source-follower approximation of the manual's Q89-1 voltage data.

The onsemi 2N5486 data sheet confirms physical pins 1=D, 2=S, 3=G,
`IDSS=8-20 mA` at `VDS=15 V`, and `VGS(off)=-2` to `-6 V`:
<https://www.onsemi.com/download/data-sheet/pdf/2n5486-d.pdf>.

## MPS6514 NPN transistors

`MPS6514.lib` contains the model used by Q89-2 and Q89-4 in VFO assembly
80289.  It was imported from the local KiCad-SPICE-Library's
`spice_complete/fairch.lib`, which identifies it as a Fairchild TO-92 model
created on 1988-09-08.

The model includes Early voltage, high-current beta rolloff, base and
collector resistance, junction capacitances, and forward/reverse transit
times.  Both KiCad instances retain the stock `Q_NPN_EBC` mapping:

| KiCad pin | Function | SPICE BJT node |
|---:|---|---|
| 1 | Emitter | E |
| 2 | Base | B |
| 3 | Collector | C |

The historical Fairchild data gives MPS6514 DC gain of 150-300 at 2 mA,
minimum gain 90 at 100 mA, 25 V minimum collector-emitter breakdown, and
3.5 pF maximum output capacitance:
<https://media.digikey.com/pdf/Data%20Sheets/Fairchild%20PDFs/NPN%2C%20PNP%20Amplifiers.pdf>.
The model's internal `BF=522` is not the same as terminal hFE at every
collector current.

The model is suitable for nominal bias, follower loading, and RF transient
work.  It does not establish installed-device gain, temperature behavior,
or production spread.

`../validation/MPS6514_validation.cir` checks the model against the manual's
Q89-2 and Q89-4 collector/base/emitter voltage data.

## MPS6512 PTO transistor

`MPS6512.lib` contains the nominal NPN model used by Q89-5 in VFO assembly
80289.  No usable MPS6512 model was found in the installed
KiCad-Spice-Library or in the web search performed for this work, so this
model was developed from the original Fairchild data sheet:
<https://bitsavers.trailing-edge.com/components/fairchild/_dataBooks/1971_Fairchild_TO92_Plastic_Transistors.pdf>.

The Fairchild data distinguishes the adjacent gain selections: MPS6512 is
specified for `hFE=50-100` at `IC=2 mA, VCE=10 V`; MPS6513 is the
`hFE=90-180` part.  MPS6512 also has `VCEO=30 V`, `hFE>=30` at 100 mA,
`Cob<=3.5 pF`, and `fT>=250 MHz` at 2 mA.  The model uses a nominal gain
near the middle of the 2 mA bin, high-current rolloff, 3.1 pF
collector-junction capacitance, and an estimated transit time chosen to
retain ample gain at the PTO frequency.

Q89-5 retains the stock `Q_NPN_EBC` mapping:

| KiCad pin | Function | SPICE BJT node |
|---:|---|---|
| 1 | Emitter | E |
| 2 | Base | B |
| 3 | Collector | C |

This model is intended to reproduce bias, oscillator startup, and loading
well enough to study the radio signal path.  It is not a fitted production
model and should not be used to predict noise, temperature drift,
breakdown, device spread, or exact oscillator amplitude.

`../validation/MPS6512_validation.cir` checks the nominal current gain and
the DC portion of Q89-5's bias network.  The manual voltage table lists
Q89-5 collector/base/emitter as 8.0/2.2/2.3 V (PDF page 28, printed page
3-12); the emitter-above-base reading is not a physically consistent NPN
DC junction voltage, so the model is not forced to match that datum.

## 1N4154 crystal-oscillator clamp diode

`1N4154.lib` contains the model used by D89-1 in VFO assembly 80289.  It
was imported from the local KiCad-Spice-Library's
`spice_complete/DIODE.LIB`, where the entry is identified as a Unitrode
35 V, 0.20 A, 2 ns silicon switching-diode model dated 1990-07-01.  The
source model name `DN4154` was changed to `1N4154`; its electrical
parameters were preserved.

D89-1 is connected with its anode at Q89-3's gate and cathode at ground.
It therefore clamps the positive gate excursion of the selected crystal
oscillator.  The model includes forward conduction, series resistance,
reverse leakage and breakdown, 4 pF zero-bias junction capacitance, and
2.88 ns transit time.  This is sufficient for oscillator startup and
waveform-limiting studies; it is not evidence of the installed diode's
exact leakage, capacitance, or switching-time distribution.

The stock KiCad diode symbol maps pin 1 to cathode and pin 2 to anode.
KiCad consequently emits the SPICE nodes in the required anode-cathode
order.

`../validation/1N4154_validation.cir` checks light-current forward clamp
voltages and reverse-biased junction capacitance.

## VFO 80289 magnetics

`80289_vfo_magnetics.lib` supplies four parameterized starting models:

| Model | Physical parts | Default starting values |
|---|---|---|
| `80278_PTO_COILS` | PTO L1, L2, L3 | 0.8 uH + (10 uH || 13 uH) |
| `80277_L4` | Oscillator-board L4 | 12 uH, Q=60, 2 pF parasitic |
| `80289_T1` | Coupled output-filter windings | 5.221 uH : 4.567 uH, K=0.2463 |
| `80289_RFC_1MH` | Four documented RF chokes | 1 mH, estimated 10 ohm DCR |

The manual documents the topology but not the tuned inductances, winding
resistance, Q, coupling, or parasitic capacitance.  The defaults are
calculated and inferred starting values, not Ten-Tec specifications.

For the PTO, PDF page 26 / printed page 3-10 states that L3 is the main
permeability-tuned coil, L2 shunts L3, and L1 is in series.  With about
140-150 pF effective tank capacitance from the surrounding circuit,
L1=0.8 uH, L2=10 uH, and an L3 sweep of roughly 10-16 uH provide an
appropriate 5.0-5.5 MHz starting range.  L1 and L2 remain parameters so
the manual endpoint/linearity alignment can be reproduced.

L4 is calculated from its documented 360 pF and 100 pF shunt capacitors.
Their 78.3 pF series equivalent requires about 11.7 uH at 5.25 MHz, rounded
to 12 uH.

The T1 estimate follows the alignment and switched topology on PDF pages
27 and 29 / printed pages 3-11 and 3-13. On 10 meters no trimmer pair is
selected. A loaded AC alignment of a fresh KiCad netlist gives 5.221 uH and
4.567 uH for the independently slug-tuned windings with K=0.2463. The fitted
trimmer settings are C7=25.73 pF, C10=20.35 pF, C8=6.697 pF, C11=7.050 pF,
C9=31.28 pF, and C12=13.93 pF. All six are within the documented 5–60 pF
range. The resulting three trimmer-selected responses are symmetrical and
the T1 path has a 0.535 dB center dip, consistent with the manual's
description of an overcoupled, shallow double-peaked response. These are
simulation-aligned estimates, not measured inductances, trimmer settings, or
a factory coupling coefficient.

C89-35 is documented only as selected in production.  A 3 pF starting
estimate is used so the netlist is numeric while adding only a small
correction to the PTO tank.  It should be swept or fitted during PTO
linearity work rather than treated as a factory value.

The four RFC values are explicitly marked 1 mH on the schematic.  Their
10 ohm winding resistance is estimated.  The default model intentionally
omits parallel capacitance because the original construction and
self-resonant frequency are unknown.

`../validation/80289_vfo_magnetics_validation.cir` checks the estimated
PTO endpoint resonances, L4 network, T1 transfer/syntax, and RFC impedance.
Its simple source and load are not the complete VFO loading, so study 4's
fresh-netlist AC response is the alignment evidence for T1 and the trimmers.

### System-level VFO transient setup

The complete-radio transient intentionally uses behavioral sources for the
two undocumented oscillators rather than claiming that the estimated PTO and
crystal networks reproduce startup:

- Q89-5 remains drawn and retains its validated MPS6512 model, but its
  schematic instance is excluded from the system simulation.  The root-sheet
  directive injects a 5.25 MHz, 300 mV-peak source at the Q89-5 emitter node
  with a 1.7 V DC offset.
- Y89-1, Y89-2, and Y89-3 act as ideal 7.5, 11, and 6.99 MHz sources.  Their
  1 V-peak amplitude is a behavioral calibration and their source polarity
  establishes the manual's approximately -2.2 V Q89-3 gate bias.
- `.options rshunt=1e12` supplies negligible DC paths for capacitively isolated
  nodes so ngspice can calculate a stable operating point.

With `S4_POS=1`, the saved 5.25 MHz PTO and 7.5 MHz crystal sources produce a
12.75 MHz wanted component of about 42.5 mV peak-to-peak into the schematic's
50 ohm load, or about 68.7 mV peak-to-peak with a 1 Mohm instrument load.
The model demonstrates frequency conversion and selection but does not match
the manual's absolute 200–300 mV alignment range on every band. It therefore
does not validate oscillator amplitude, phase noise, startup margin, pulling,
transformer loss/turns ratio, or production output level.

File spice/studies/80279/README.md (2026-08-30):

# Ten-Tec 80279 IF-AGC board: operation and simulation study

## Scope and status

This study explains the Model 540 assembly 80279 signal path and defines the
simulations used to demonstrate each function. Results are added to the
corresponding section as each simulation is completed.

| No. | Simulation | Status | Main question |
|---:|---|---|---|
| 1 | Receive/no-signal DC operating point | **Completed — partial pass; IC1 corrected, Q79-5 discrepancy remains** | Are the board rails and semiconductor bias points consistent with the service manual? |
| 2 | 9 MHz IF response and signal walk | **Completed — estimated transformer fit** | Do Q79-1, T79-1, Q79-2, and T79-2 amplify and select the 9 MHz IF? |
| 3 | PIN-diode AGC attenuation sweep | **Completed — open-loop functional pass** | How much does IF gain change as D79-1, D79-2, and D79-3 forward bias increases? |
| 4 | Product detector and audio recovery | **Completed — functional pass** | Does Q79-3 convert a displaced 9 MHz IF and BFO into the expected audio difference frequency? |
| 5 | Audio-amplifier and AGC-detector path | **Completed — functional pass** | Do the two MC1747 sections provide audio output and sufficient AGC-detector drive? |
| 6 | AGC attack, hold, and release | **Completed — functional split-model pass** | Does a strong-signal step reduce IF gain quickly and recover slowly without instability? |
| 7 | S-meter calibration and transmit inhibit | **Completed — functional pass; factory S9 calibration remains a whole-radio measurement** | Does R79-20 set meter sensitivity, and does the T line remove meter drive/reset AGC on transmit? |

The primary sources are the Ten-Tec Model 540 owner/service manual, PDF page 32
/ printed page 3-16 for the functional description and voltage tables, and PDF
page 33 / printed page 3-17 for the schematic and IC-1 pin table. The KiCad
source of truth is `80279_if_agc.kicad_sch`.

## How the board works

### 9 MHz IF amplifier

The receiver mixer output first passes through the eight-pole crystal lattice
filter on the 80282 SSB Generator assembly. The resulting 9 MHz signal enters
80279 at `IN`.

Q79-1 and Q79-2 are the two gain-controlled IF stages. T79-1 couples the first
stage to the second, and T79-2 couples the second stage to the product detector.
The manual alignment procedure peaks T79-1 and T79-2 for maximum S-meter
reading while keeping the indication below S5 to minimize AGC action.

D79-1, D79-2, and D79-3 are HP 5082-3379 PIN diodes placed at the input,
interstage, and detector-input portions of the IF path. Increasing their common
forward-bias control increases RF shunting and reduces IF gain. The project
PIN-diode model implements this primarily as current-controlled RF resistance;
it is intended to show the attenuation trend at 9 MHz, not calibrated
distortion, noise, or temperature behavior.

The T79-1/T79-2 numerical model is an engineering alignment estimate:
L79-3 through L79-6 are 2.63 uH and the winding coupling is `K=0.25`. Absolute
gain, center frequency, and bandwidth must therefore be described as simulated
model behavior until the original transformers are measured.

### Product detector and filter loop

Q79-3 is the dual-gate 40823 product detector. The final IF transformer drives
the detector signal input, while the `BFO` terminal supplies the beat-frequency
oscillator. The detector produces the audio difference frequency.

Recovered audio leaves at `FILT IN` and returns at `FILT OUT`. A Model 245 CW
filter may be connected between those terminals. With no CW filter installed,
the manual specifies that the two terminals are jumpered at the filter socket.
The root schematic and the standalone simulation fixture use that jumper.

### Audio and AGC generation

One section of IC1, an MC1747 dual internally compensated op amp, amplifies the
returned audio and drives the `AUDIO` terminal. The second section amplifies the
same recovered audio further for AGC detection.

D79-6 and the associated storage network rectify the AGC-amplifier output.
Q79-4 and Q79-5 form the DC Darlington stage that drives the three PIN-diode
bias resistors and the S-meter path. C79-22 is 4.7 uF and R79-24 is 680 kOhm;
their simple product is about 3.20 seconds, although diode and transistor paths
alter the actual attack and release curves.

R79-20 is the S-meter calibration control. The manual calibrates S9 using a
50 uV signal at the radio antenna on 14.100 MHz. That is a whole-receiver
condition and must not be treated as a 50 uV signal at the 80279 `IN` terminal.

### Receive/transmit control

In receive/no-signal operation the manual gives `R=12.1 V` and `T=0.2 V`. In
transmit it gives `R=0 V` and `T=10.4 V`. Q79-6 responds to the T line to reset
or inhibit the AGC storage network, and D79-4 blocks the receive S-meter drive
during transmit.

## Schematic-native simulation fixture

The fixture is in the upper-right corner of `80279_if_agc.kicad_sch` inside a
red dashed rectangle marked **SIMULATION ONLY**. Its parts are excluded from
the BOM and PCB.

| Fixture item | Setting | Evidence or purpose |
|---|---:|---|
| V79-SIM1 | 13.8 V DC | Manual `+12` receive voltage |
| V79-SIM2 | 8.0 V DC | Manual `+REG` voltage |
| V79-SIM3 | 12.1 V DC | Manual `R` receive voltage |
| V79-SIM4 | 0.2 V DC | Manual `T` receive voltage |
| V79-SIM5 | `dc=0 ampl=1m f=9Meg ac=1` | Zero DC for operating point; starting IF source for later AC/transient studies |
| V79-SIM6 | `dc=6.5 ampl=100m f=9Meg ac=0` | Documented 6.5 V BFO DC level; 100 mV RF amplitude is an estimated starting value |
| I79-SIM1 | Disabled normally; current-controlled in Simulation 3 | Opens D79-5 and forces the common PIN-bias bus only for the open-loop sweep |
| R79-SIM1 | 25 kOhm | Root-sheet volume-control load seen by `AUDIO` |
| R79-SIM2 | 1 kOhm | Existing root-sheet S-meter simulation load |
| FILT jumper | `FILT IN` to `FILT OUT` | Manual no-CW-filter configuration |
| Solver option | `.options rshunt=1e12` | Gives capacitor-only DC islands a negligible reference path |

The 1 TOhm shunt is numerical stabilization, not an original Ten-Tec part.

## Simulation 1 — receive/no-signal DC operating point

### Purpose

This is the prerequisite simulation. It verifies supply and control fixtures,
checks model pin mappings, and compares the calculated no-signal bias against
the manual before RF gain or closed-loop AGC results are trusted.

### Analysis setup

- Circuit source: fresh KiCad 10 SPICE export of `80279_if_agc.kicad_sch`
- Simulator: ngspice 46
- Analysis: `.op`
- Temperature: 27 degrees C
- Mode: receive, no input signal
- Filter configuration: `FILT IN` jumpered to `FILT OUT`
- AUDIO load: 25 kOhm
- S-meter load: 1 kOhm
- Potentiometer R79-20: saved schematic position, 0.5
- Convergence: dynamic gmin stepping completed; one operating-point row and
  135 variables were produced

The complete curated result table is in
`dc-operating-point/data/80279-dc-operating-point.csv`. Disposable exported
netlists, raw data, and logs are under `spice/generated/80279/`.

### Board-terminal results

| Terminal | Manual receive/no-signal | Simulated | Result |
|---|---:|---:|---|
| IN | 0 V | 0 V | Pass |
| AUDIO | 0 V | 0 V | Pass |
| T | 0.2 V | 0.2 V | Pass |
| +12 | 13.8 V | 13.8 V | Pass |
| S MTR | 0 V | 0.732 uV | Pass; effectively zero |
| FILT IN / FILT OUT | 0 V | 0 V | Pass |
| R | 12.1 V | 12.1 V | Pass |
| +REG | 8.0 V | 8.0 V | Pass |
| BFO | 6.5 V | 6.5 V | Pass |

### IF-amplifier transistor results

| Device | Terminal | Manual | Simulated | Error | Result |
|---|---|---:|---:|---:|---|
| Q79-1 | C | 13.7 V | 13.638 V | -0.45% | Pass |
| Q79-1 | B | 1.0 V | 1.046 V | +4.59% | Pass |
| Q79-1 | E | 0.3 V | 0.362 V | +20.76% | Review; only 62 mV high |
| Q79-2 | C | 13.3 V | 13.323 V | +0.17% | Pass |
| Q79-2 | B | 1.8 V | 1.788 V | -0.68% | Pass |
| Q79-2 | E | 1.1 V | 1.070 V | -2.74% | Pass |

The empirical MPS3693 model and both IF-stage bias networks reproduce the
manual closely enough to proceed with the small-signal 9 MHz study.

### Product-detector and AGC transistor results

| Device | Terminal | Manual | Simulated | Error | Result |
|---|---|---:|---:|---:|---|
| Q79-3 | D | 3.0 V | 3.349 V | +11.64% | Pass |
| Q79-3 | G1 | 0.6 V | 0.641 V | +6.76% | Pass |
| Q79-3 | S | 2.0 V | 1.737 V | -13.13% | Pass |
| Q79-3 | G2 | 2.0 V | 1.737 V | -13.13% | Pass |
| Q79-4 | C/B/E | 13.8 / 1.2 / 0.8 V | 13.8 / 1.069 / 0.618 V | — | C passes; B/E low |
| Q79-5 | C/B/E | 13.8 / 0.8 / 0.2 V | 13.8 / 0.618 / 0.040 V | — | Emitter fails |
| Q79-6 | C/B/E | 1.2 / 0.05 / 0 V | 1.069 / 0.047 / 0 V | — | Pass |

Q79-3 now agrees with the manual within the 15 percent service-study tolerance.
The correction puts R79-13/C79-11/C79-12 on gate 1, C79-19 and R79-16 on gate
2, and R79-15/R79-16/C79-15/C79-16 on the source while preserving the RCA
physical order `1=D, 2=G2, 3=G1, 4=S/case`. The low Q79-5 emitter voltage
remains a separate low-current model finding.

### IC1 results

| IC1 pin | Function | Manual | Simulated | Result |
|---:|---|---:|---:|---|
| 1 | -IN A | 7.0 V | 6.882 V | Pass |
| 2 | +IN A | 6.8 V | 6.882 V | Pass |
| 4 | VEE | 0 V | 0 V | Pass |
| 6 | +IN B | 7.0 V | 6.890 V | Pass |
| 7 | -IN B | 7.0 V | 6.890 V | Pass |
| 9 | VCC B | 13.8 V | 13.8 V | Pass |
| 10 | OUT B | 6.8 V | 6.882 V | Pass |
| 12 | OUT A | 7.0 V | 6.866 V | Pass |
| 13 | VCC A | 13.8 V | 13.8 V | Pass |

After correction of the IC1 surrounding wiring, all nine documented connected
pins agree with the manual within 2 percent. The MC1747 DC prerequisite for
simulations 5 and 6 is therefore satisfied. The model limitations described
below still apply to dynamic results.

### Simulation 1 conclusion

**Partial pass.** The fixture, board terminals, Q79-1, Q79-2, Q79-3, Q79-6,
and all documented IC1 points are credible. The separate low-current Q79-4/
Q79-5 result remains under review, with Q79-5 emitter at 0.040 V versus the
manual's 0.2 V. All later simulations may now proceed, but AGC amplitude claims
must retain that model caveat until the Q79-5 discrepancy is resolved.

## Simulation 2 — 9 MHz IF response and signal walk

### Purpose and method

Run an AC sweep from approximately 8 to 10 MHz with the receive rails above.
Use V79-SIM5's `ac=1` excitation. Plot the input, Q79-1 collector, T79-1
secondary/Q79-2 base, Q79-2 collector, and T79-2 secondary. Record center
frequency, -3 dB bandwidth, stage gains, and total gain.

Repeat after adjusting the estimated transformer parameters only if the saved
values are clearly inconsistent with 9 MHz operation. Any fit remains an
engineering estimate until original transformer measurements exist.

### Results

Completed from a fresh KiCad SPICE export with ngspice 46. The final saved
alignment estimate uses 2.63 uH for L79-3 through L79-6 and `K=0.25` for both
transformers. The original 2.6 uH starting value peaked at 9.052 MHz and put
9.000 MHz about 4.9 dB below the peak. Increasing all four winding estimates
by 1.15 percent centers the modeled response without changing circuit
topology.

Run the study with:

```powershell
python spice/tools/run_80279_if_response.py
```

The runner exports `80279_if_agc.kicad_sch` afresh, runs a 4001-point linear
AC sweep from 8.8 to 9.2 MHz, and writes disposable netlists and logs below
`spice/generated/80279-if-response/`.

#### Response measurements

| Measurement | Simulated result |
|---|---:|
| Peak frequency | 8.9997 MHz |
| Peak `IN` to Q79-3 G1 gain | 55.066 dB |
| Gain at 9.000 MHz | 55.066 dB |
| Lower -3 dB frequency | 8.96291 MHz |
| Upper -3 dB frequency | 9.04615 MHz |
| -3 dB bandwidth | 83.240 kHz |
| Loaded Q from complete response | 108.1 |

#### 9 MHz signal walk

The AC source is 1 V for transfer normalization. Node gain is therefore the
small-signal voltage transfer from the board `IN` terminal. Incremental gain
is relative to the preceding row.

| Observation point | Gain from `IN` | Incremental gain |
|---|---:|---:|
| Q79-1 collector | 30.393 dB | +30.393 dB |
| T79-1 secondary / Q79-2 base | 28.747 dB | -1.646 dB |
| Q79-2 collector | 60.596 dB | +31.849 dB |
| T79-2 secondary / Q79-3 G1 | 55.066 dB | -5.530 dB |

The two transistor stages provide gain, while each transformer transfers and
selects the 9 MHz signal. With the fixture's later transient-source amplitude
of 1 mV peak, the linearized 9 MHz result corresponds to approximately 33 mV
at Q79-1 collector, 27 mV at Q79-2 base, 1.07 V at Q79-2 collector, and
0.567 V at Q79-3 G1. Those scaled values are AC predictions, not a substitute
for the later nonlinear transient test. Figure 79-1 plots the estimated
response.

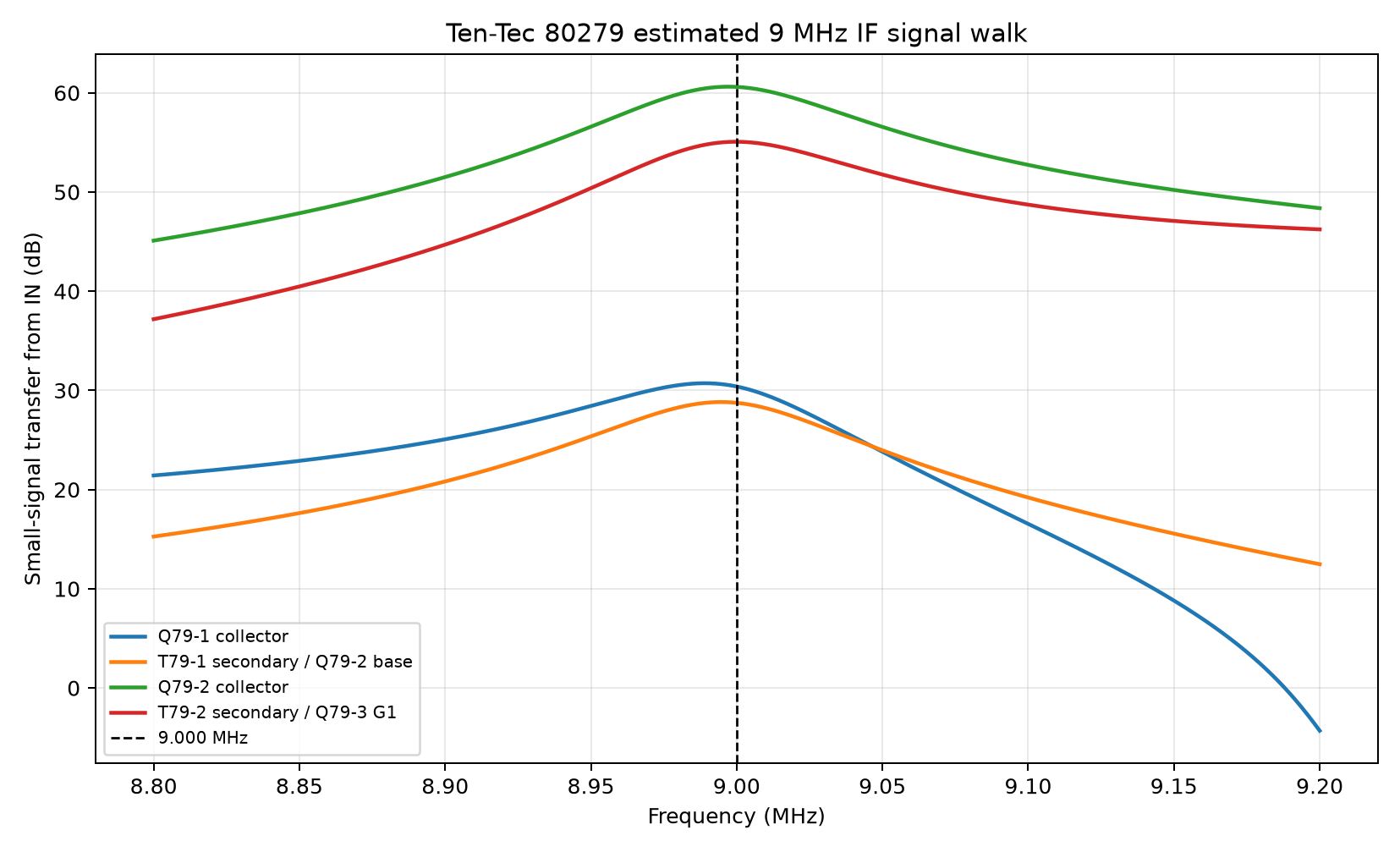
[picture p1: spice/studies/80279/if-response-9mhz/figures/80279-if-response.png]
80279 estimated 9 MHz IF response


**Figure 79-1.** 80279 estimated 9 MHz IF response

Curated numerical outputs are in `if-response-9mhz/data/`. The peak alignment,
absolute gain, bandwidth, and loaded Q are behavior of the estimated 2.63 uH,
`K=0.25` transformer model. The manual documents that T79-1 and T79-2 are
peaked at 9 MHz, but it does not document winding inductance, coupling,
resistance, Q, or parasitic capacitance. These numbers must not be presented
as Ten-Tec specifications until original transformers are measured.

## Simulation 3 — PIN-diode AGC attenuation sweep

### Purpose, method, and results

The normal D79-5 AGC-drive connection is opened and the disabled-by-default
I79-SIM1 fixture forces equal current through the three 1 kOhm PIN feed
branches. Current control avoids a multiple-solution artifact found when the
empirical current-controlled resistance model was driven from an ideal voltage
source. A 2,001-point 8.8–9.2 MHz AC sweep is run at twelve bias levels from
zero through 20 mA per diode.

At zero current the gain from board `IN` to Q79-3 G1 is 55.066 dB. The result
then falls monotonically: 10 uA per diode gives 46.178 dB, 100 uA gives
19.361 dB, 1 mA gives -32.491 dB, and 12 mA gives -77.593 dB. Relative to the
zero-current response, those points provide 8.888, 35.705, 87.557, and
132.659 dB of modeled attenuation respectively. Figure 79-11 shows the response
family.

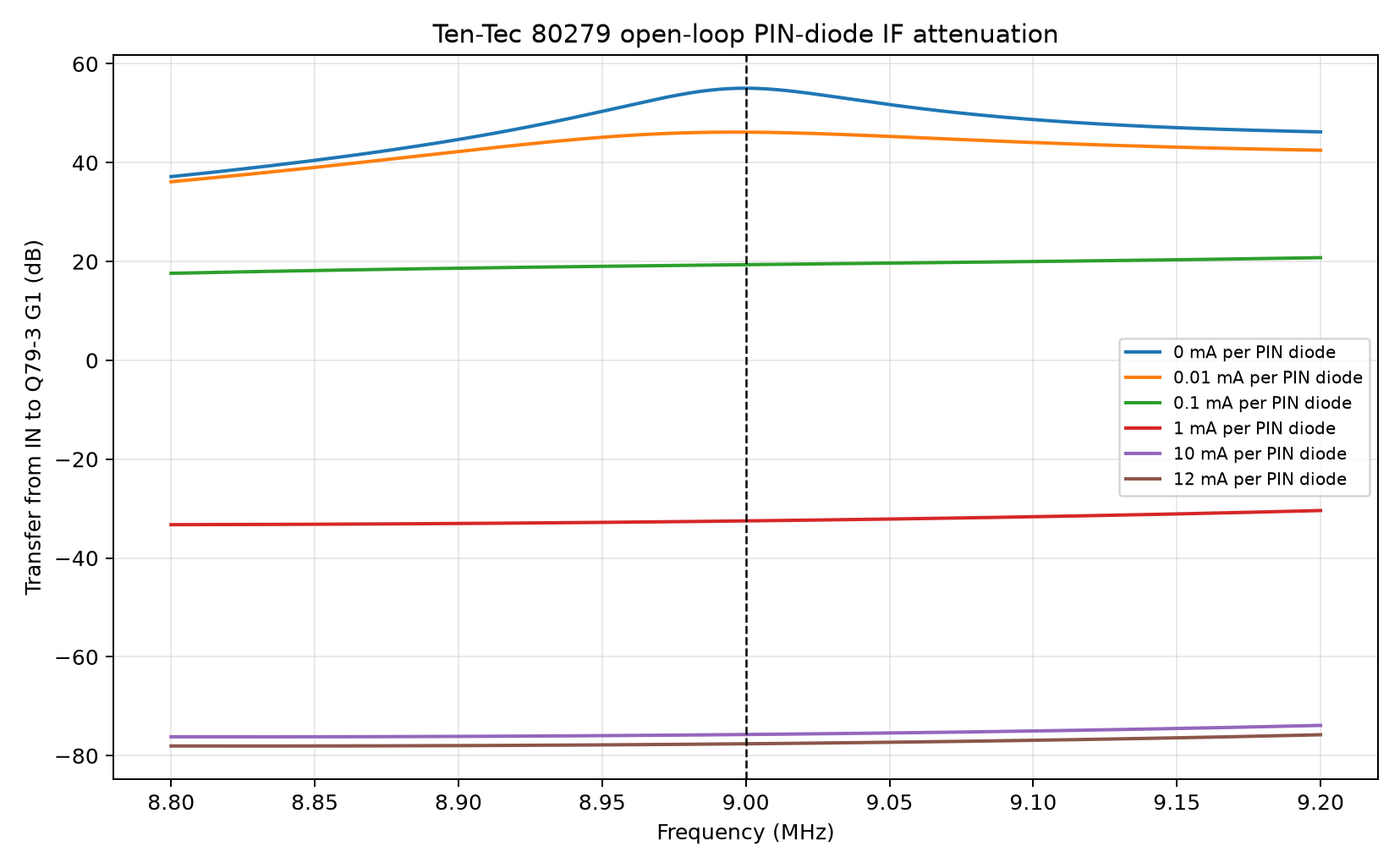
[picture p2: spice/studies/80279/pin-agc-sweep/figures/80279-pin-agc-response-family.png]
80279 open-loop PIN-diode IF response family


**Figure 79-11.** 80279 open-loop PIN-diode IF response family

**Functional pass.** Increasing PIN forward current produces increasing 9 MHz
attenuation in the required AGC direction. The very large high-current figures
are idealized small-signal model isolation, not measured receiver AGC range.
The 20 mA model endpoint requires 20.87 V and is impossible from the board's
13.8 V supply; even the 12 mA/12.85 V point is an upper-bound checkpoint before
D79-5 drop and Q79-5 saturation are allowed for.

The complete method, plots, limitations, and machine-readable results are in
the [Simulation 3 README](pin-agc-sweep/README.md). Regenerate them with:

```powershell
python spice/tools/run_80279_pin_agc_sweep.py
```

## Simulation 4 — product detector and audio recovery

### Purpose and method

With Q79-3 DC bias corrected, drive `IN` at 9.001 MHz and `BFO` at 9.000 MHz.
Sweep BFO RF amplitude because the manual documents only its 6.5 V DC terminal
voltage. Plot T79-2 output, Q79-3 terminals, `FILT IN`, `FILT OUT`, and an FFT
of recovered audio. The expected wanted product is 1 kHz.

### Results

Completed from a fresh KiCad SPICE export with ngspice 46. The runner used a
100 uV-peak board input at 9.001 MHz and swept the undocumented BFO RF
amplitude from zero through 1.5 V peak while retaining the documented 6.5 V
BFO DC level. The 400 mV-peak nominal case was repeated with the IF source
turned off.

The transient Q79-3 gate-1 amplitude was 112.240 mV peak-to-peak, 0.96% below
the Simulation 2 AC prediction and inside the runner's 3% convergence limit.
At the 400 mV-peak nominal BFO setting, the jumpered `FILT IN` / `FILT OUT`
node contained a 34.490 mV peak-to-peak 1 kHz tone with 1.897% modeled total
harmonic distortion. The same tone measured 0.0195 mV peak-to-peak with the
BFO off and 0.307 mV peak-to-peak with the IF off.

Recovered 1 kHz output increased from 2.690 mV peak-to-peak at 25 mV-peak BFO
drive to 88.137 mV peak-to-peak at 1.5 V-peak drive. The increase becomes less
than proportional at high drive, indicating modeled detector compression.

**Functional pass.** The detector produces the calculated 1 kHz difference
frequency and requires both RF inputs. Absolute conversion gain, distortion,
compression, and the correct installed BFO amplitude remain unverified because
the manual does not specify them and the RCA 40823 model is empirical.
Figure 79-3 shows the detector waveforms and Figure 79-4 the recovered-audio
spectrum.

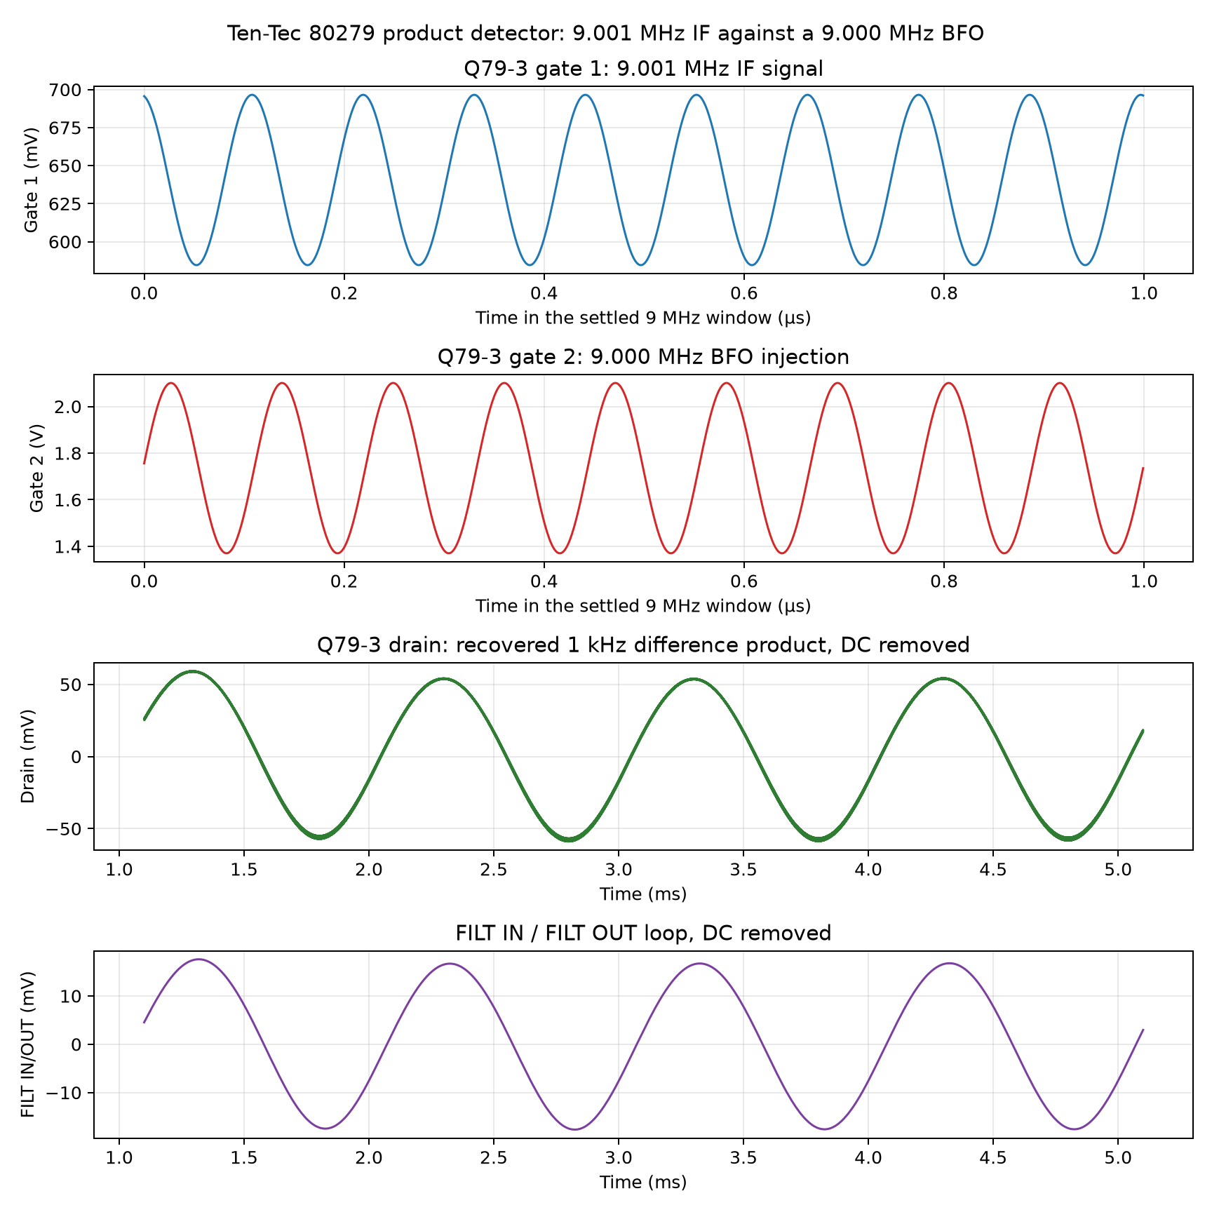
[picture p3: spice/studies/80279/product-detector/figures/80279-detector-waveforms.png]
80279 product-detector waveforms


**Figure 79-3.** 80279 product-detector waveforms

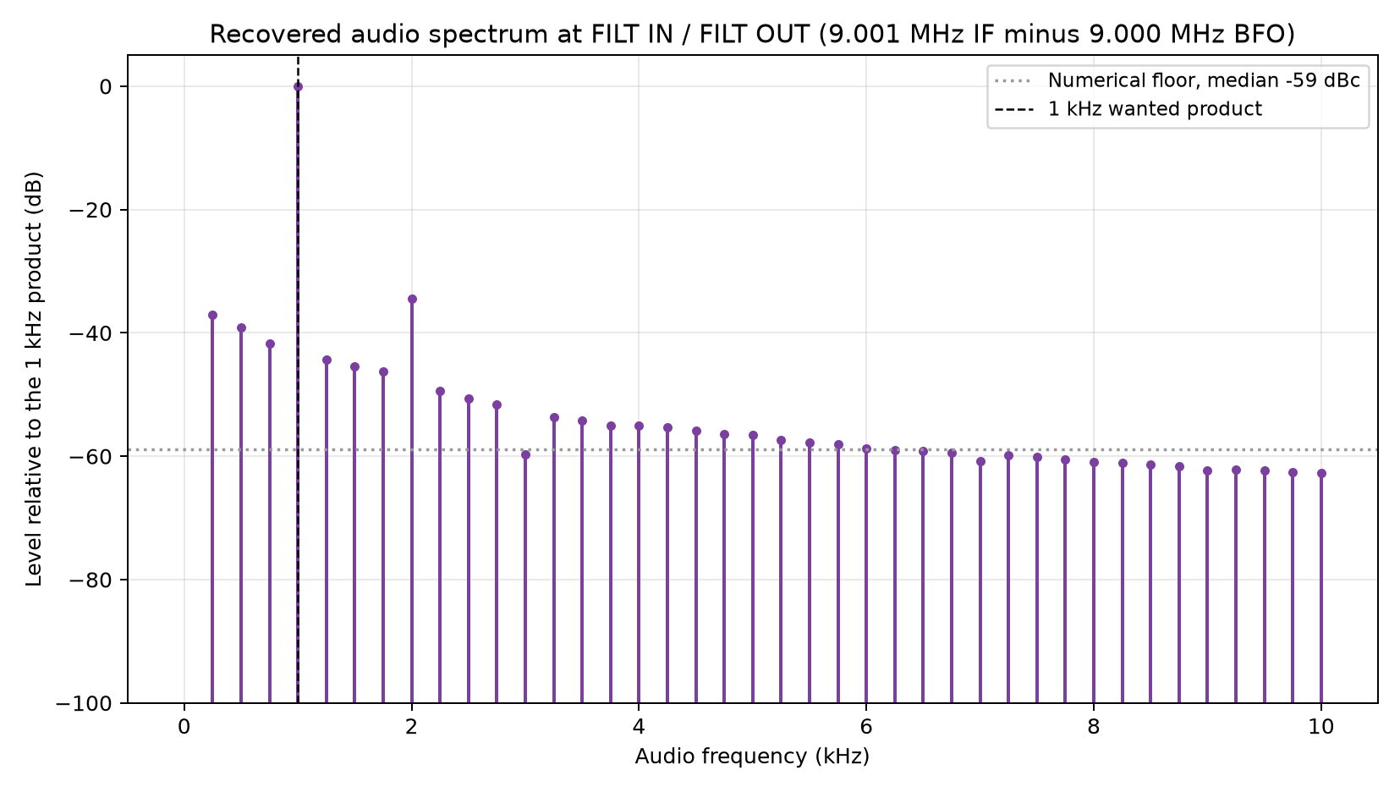
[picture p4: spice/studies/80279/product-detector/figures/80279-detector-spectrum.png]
80279 recovered-audio spectrum


**Figure 79-4.** 80279 recovered-audio spectrum

The complete method and retained evidence are in the
[Simulation 4 README](product-detector/README.md). Regenerate the study with:

```powershell
python spice/tools/run_80279_product_detector.py
```

## Simulation 5 — audio amplifier and AGC detector

### Purpose and method

After resolving IC1 DC bias, inject a controlled 1 kHz signal at `FILT OUT`.
Measure the gain and clipping margin of the first MC1747 section at `AUDIO`,
then the second section and the D79-6 rectifier/storage path. Also sweep audio
frequency over the expected receiver passband to show the board contribution
separately from the optional external CW filter.

### Results

Completed from a fresh KiCad SPICE export with ngspice 46. In disposable
netlist copies, the existing red-box V79-SIM5 source is moved from board `IN`
to the jumpered `FILT IN` / `FILT OUT` node. The saved schematic topology and
all original component values remain unchanged.

The small-signal sweep gives 97.635 V/V (39.792 dB) from the filter loop to
`AUDIO` at 1 kHz, versus 101 V/V calculated from R79-31/R79-32. The complete
gain to the AGC op-amp output is 305.313 V/V (49.695 dB), versus approximately
316 V/V calculated for both cascaded sections. The modeled -3 dB band is
138.8 Hz to 2.965 kHz at `AUDIO` and 140.4 Hz to 2.967 kHz at the AGC output.

In the 1 kHz level sweep, AUDIO gain remains close to 97.6 V/V through
50 mV-peak input, where output is 9.613 V peak-to-peak with 0.352% modeled
THD. At 75 mV peak, output is 11.235 V peak-to-peak and THD rises to 12.75%,
showing clipping. The AGC section reaches its modeled limits earlier, between
15 and 20 mV peak input.

After 120 ms at 10 mV-peak input, C79-22 is at 2.325 V, the PIN bus is at
0.620 V, and one nominal PIN branch carries 20.8 uA. At 15 mV peak those
values are 2.983 V, 1.106 V, and 393 uA. These are end-of-test values, not
attack/release measurements.

**Functional pass.** Both op-amp sections reproduce their resistor-calculated
gain closely, AUDIO remains clean until expected rail limiting, and D79-6
produces enough monotonic AGC control to cover the useful PIN-current region
identified in Simulation 3. Absolute control values retain the Q79-5 model
caveat. Figure 79-5 plots the frequency response and Figure 79-6 the level and
AGC response.

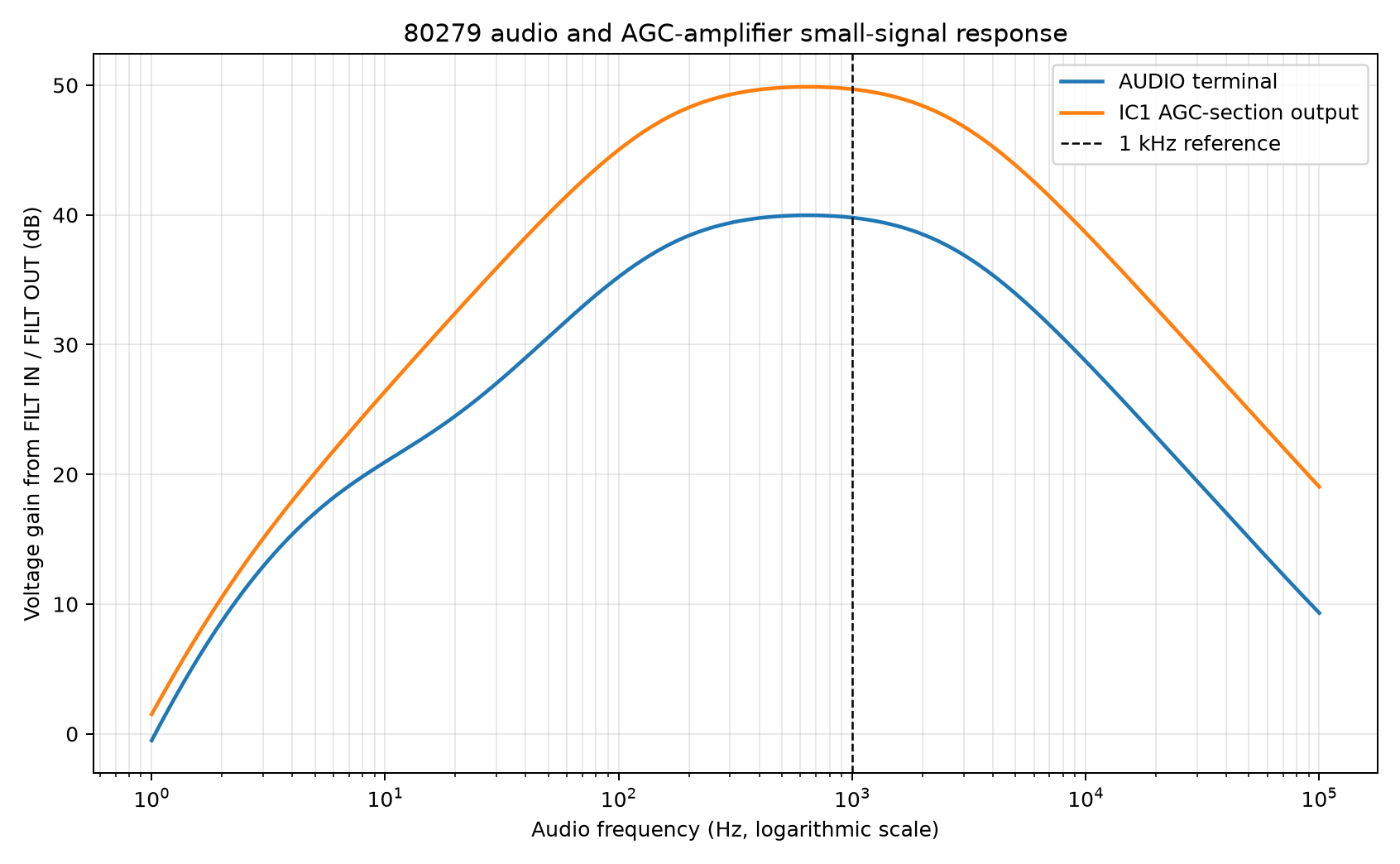
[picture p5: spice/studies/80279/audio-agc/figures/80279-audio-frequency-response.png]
80279 audio and AGC frequency response


**Figure 79-5.** 80279 audio and AGC frequency response

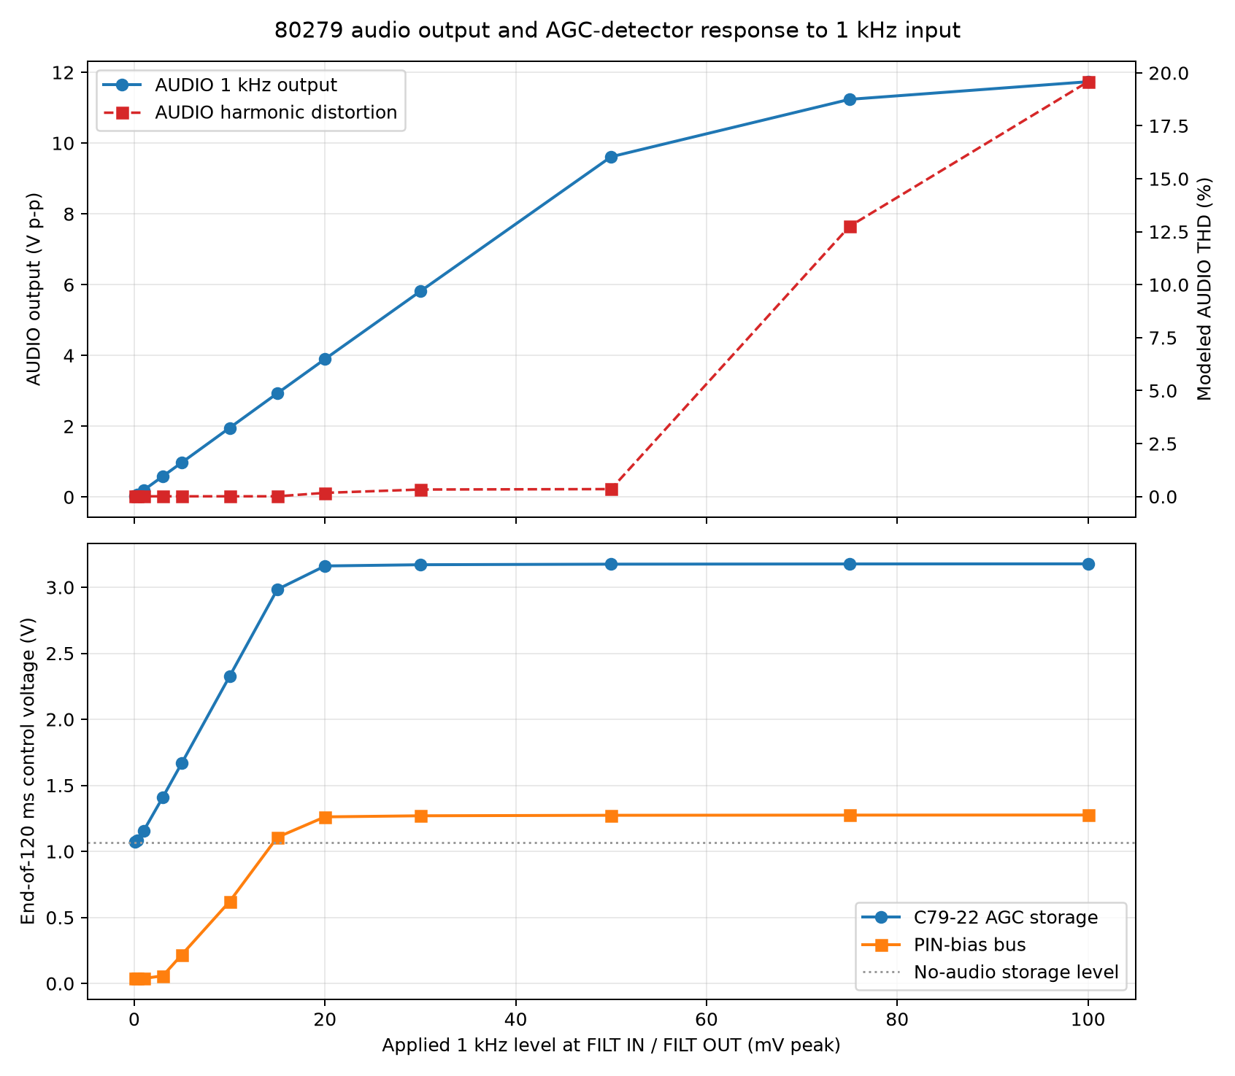
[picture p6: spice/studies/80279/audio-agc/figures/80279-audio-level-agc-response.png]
80279 audio level and AGC response


**Figure 79-6.** 80279 audio level and AGC response

The complete method and retained evidence are in the
[Simulation 5 README](audio-agc/README.md). Regenerate the study with:

```powershell
python spice/tools/run_80279_audio_agc.py
```

## Simulation 6 — closed-loop AGC attack and release

### Purpose and method

Apply a weak/strong/weak IF amplitude sequence while producing a stable audio
beat. Plot input and final IF envelopes, `AUDIO`, both MC1747 outputs, C79-22,
the common PIN-bias bus, individual PIN currents, and S-meter current. Measure
attack time, release time, overshoot, and residual audio-output change.

A literal multi-second transient resolving a 9 MHz carrier is unnecessarily
large. Use a short full-RF transient to validate attack and a slower recovered-
audio/envelope study for the long release. Cross-check the envelope result
against the open-loop gain-versus-PIN-bias data from Simulation 3.

### Results

Completed from fresh KiCad SPICE exports with ngspice 46. The short full-RF
run retains the complete 9 MHz signal and feedback topology. Its 6 ms strong
interval raises C79-22 but is shorter than the measured model attack and does
not yet turn on Q79-5 materially. A staged full-RF comparison therefore holds
C79-22 at the 2.325 V control level established in Simulation 5. At 100 uV-
peak board input this produces 20.60 uA per PIN branch and reduces Q79-3 gate-1
IF from 115.486 to 12.819 mV peak-to-peak, a 19.09 dB reduction through the
actual Q79-4/Q79-5, PIN-diode, transformer, and Q79-3 path.

The multi-second envelope uses the Simulation 4 zero-control detector transfer
and interpolates Simulation 3 attenuation versus PIN-bias voltage while
retaining the physical IC1/D79-6/C79-22/Q79-4/Q79-5/S-meter circuitry. A
1-to-100 uV-peak board-input step is 40 dB. AUDIO changes from 0.03366 to
0.54825 V peak-to-peak, or 24.24 dB, so the modeled loop removes 15.76 dB of
that change. The first strong AUDIO peak is 3.365 V peak-to-peak before the
loop reacts.

C79-22 moves from 1.074 to 2.336 V. PIN current rises from essentially zero
to 22.98 uA per branch, and modeled S-meter current rises from essentially
zero to 101.57 uA. The C79-22 10%-90% attack is 59.0 ms; 90%-10% release is
1.991 s. Post-release AUDIO overshoot is only 0.0035%.

**Functional pass with split-model qualification.** The actual RF/control
path attenuates in the correct direction, and the calibrated long loop attacks
faster than it releases without instability. Absolute timing and control
levels remain model predictions and retain the Q79-5 caveat. Figure 79-7
cross-checks the control states and Figure 79-8 shows attack and release.

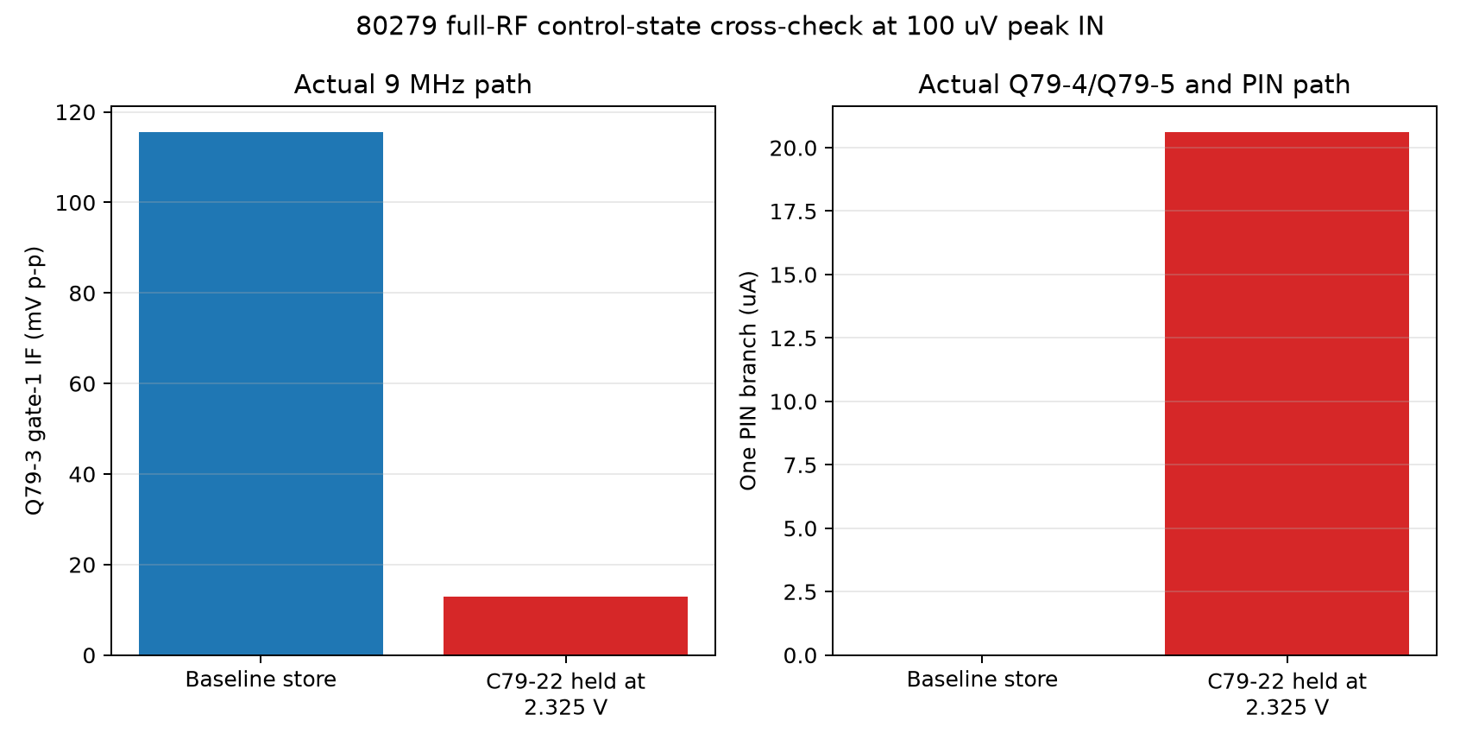
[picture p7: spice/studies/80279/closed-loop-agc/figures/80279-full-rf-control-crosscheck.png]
80279 full-RF control-state cross-check


**Figure 79-7.** 80279 full-RF control-state cross-check

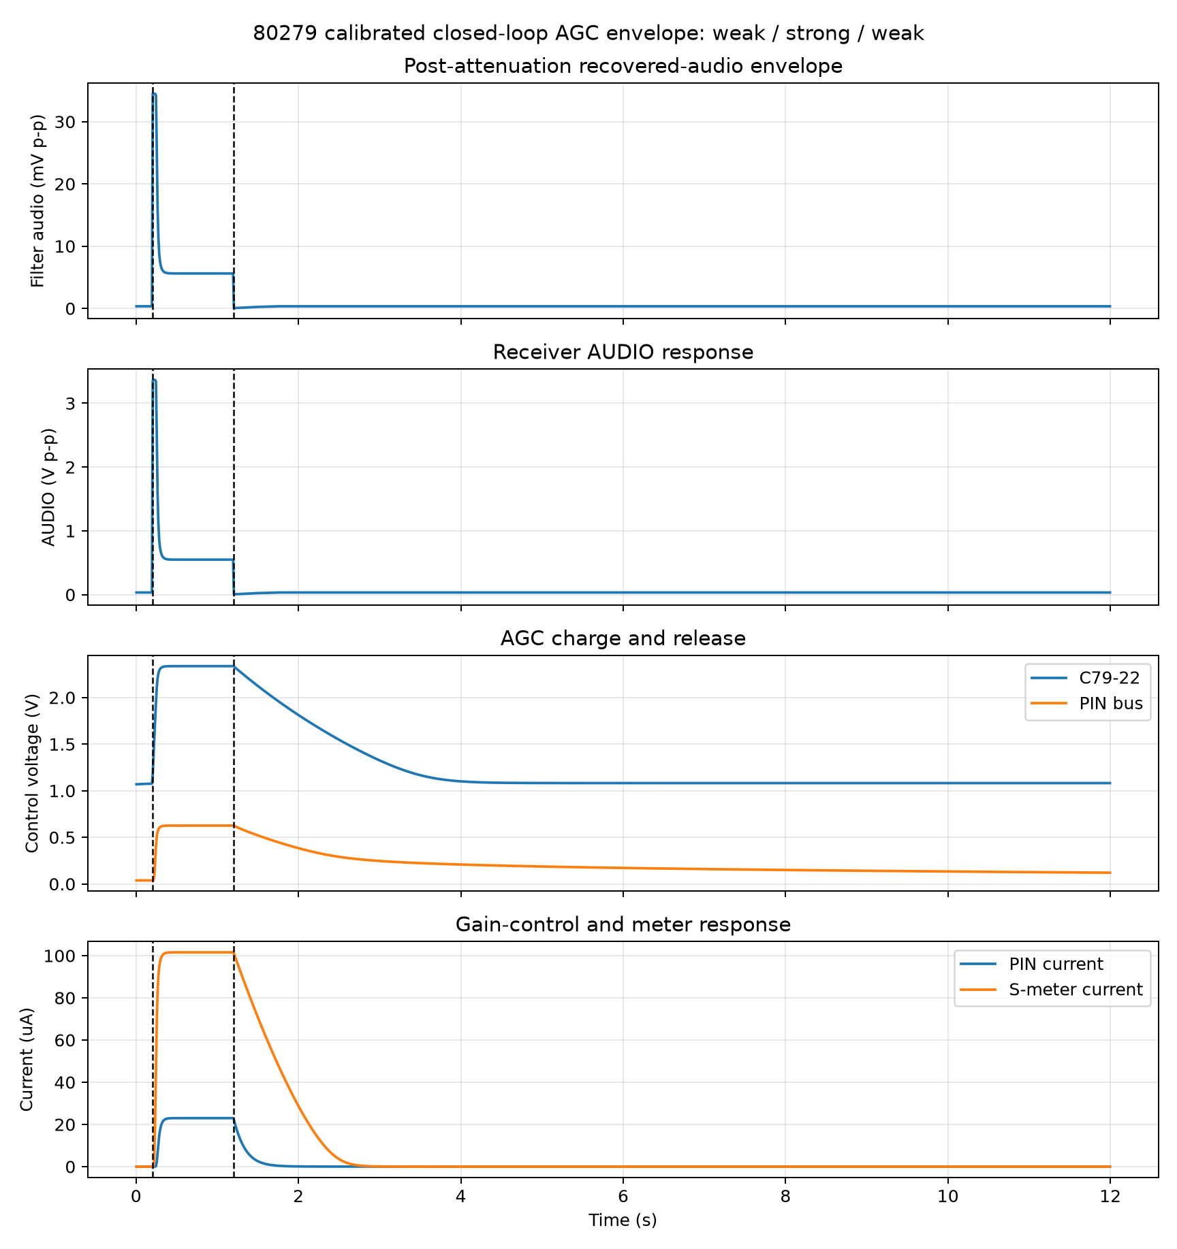
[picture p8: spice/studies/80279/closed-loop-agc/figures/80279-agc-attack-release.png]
80279 modeled AGC attack and release


**Figure 79-8.** 80279 modeled AGC attack and release

The complete method and retained evidence are in the
[Simulation 6 README](closed-loop-agc/README.md). Regenerate the study with:

```powershell
python spice/tools/run_80279_closed_loop_agc.py
```

## Simulation 7 — S-meter calibration and transmit inhibit

### Purpose and method

With receive AGC working, sweep IF input level and R79-20 position and record
current through the 1 kOhm S-meter model. Do not label a board-input amplitude
as S9 from the manual's 50 uV antenna specification without simulating the
preceding receiver gain and filter loss.

Then establish a strong-signal AGC state and step from receive (`R=12.1 V`,
`T=0.2 V`) to transmit (`R=0 V`, `T=10.4 V`). Plot Q79-6, C79-22, D79-4, PIN
bias, and meter current to demonstrate AGC reset and meter disconnection.

### Results

Completed from a fresh KiCad SPICE export with ngspice 46. The meter sweep
uses the calibrated Simulation 6 envelope while retaining the actual IC1,
D79-6, C79-22, Q79-4/Q79-5, Q79-6, R79-20, D79-4, PIN-bias, and meter-load
circuits.

At the saved R79-20 midpoint, modeled meter current is 0.00087 uA at 1 uV,
3.270 uA at 10 uV, 66.054 uA at 20 uV, 91.424 uA at 50 uV, 101.567 uA at
100 uV, and 111.092 uA at 200 uV peak board input. These are 80279 `IN`
levels, not antenna S units. At the 100 uV board test level, changing R79-20
from position 0.05 to 0.95 changes meter current from 60.20 to 368.68 uA while
changing PIN current by less than 1%.

In the receive-to-transmit test, the supplies change from `R=12.1 V`,
`T=0.2 V` to `R=0 V`, `T=10.4 V` while a strong test signal remains applied.
Q79-6 base rises from 0.047 to 0.707 V, C79-22 falls from 2.336 to 0.0805 V,
and one PIN branch falls from 22.96 uA to 0.00627 uA. Meter current falls from
101.56 uA to the numerical leakage floor. The stored AGC completes 90% of its
fall in 168 us.

In a separate transmit-state isolation check, 1.000 V applied externally to
`S MTR` leaves D79-4's board-side anode at only 3.01 uV, with C79-22 reset at
0.0806 V. D79-4 therefore prevents transmit-side meter voltage from feeding
back into the receive AGC model.

**Functional pass with factory-calibration qualification.** Signal strength
and R79-20 control the meter in the expected directions, and Q79-6/D79-4
remove receive AGC and meter drive on transmit. The factory S9 adjustment
cannot be reproduced without the antenna-to-board gain and original meter
movement; the manual's 50 uV value applies at the radio antenna, not 80279
`IN`. Figure 79-9 plots the S-meter response and Figure 79-10 the
receive-to-transmit reset.

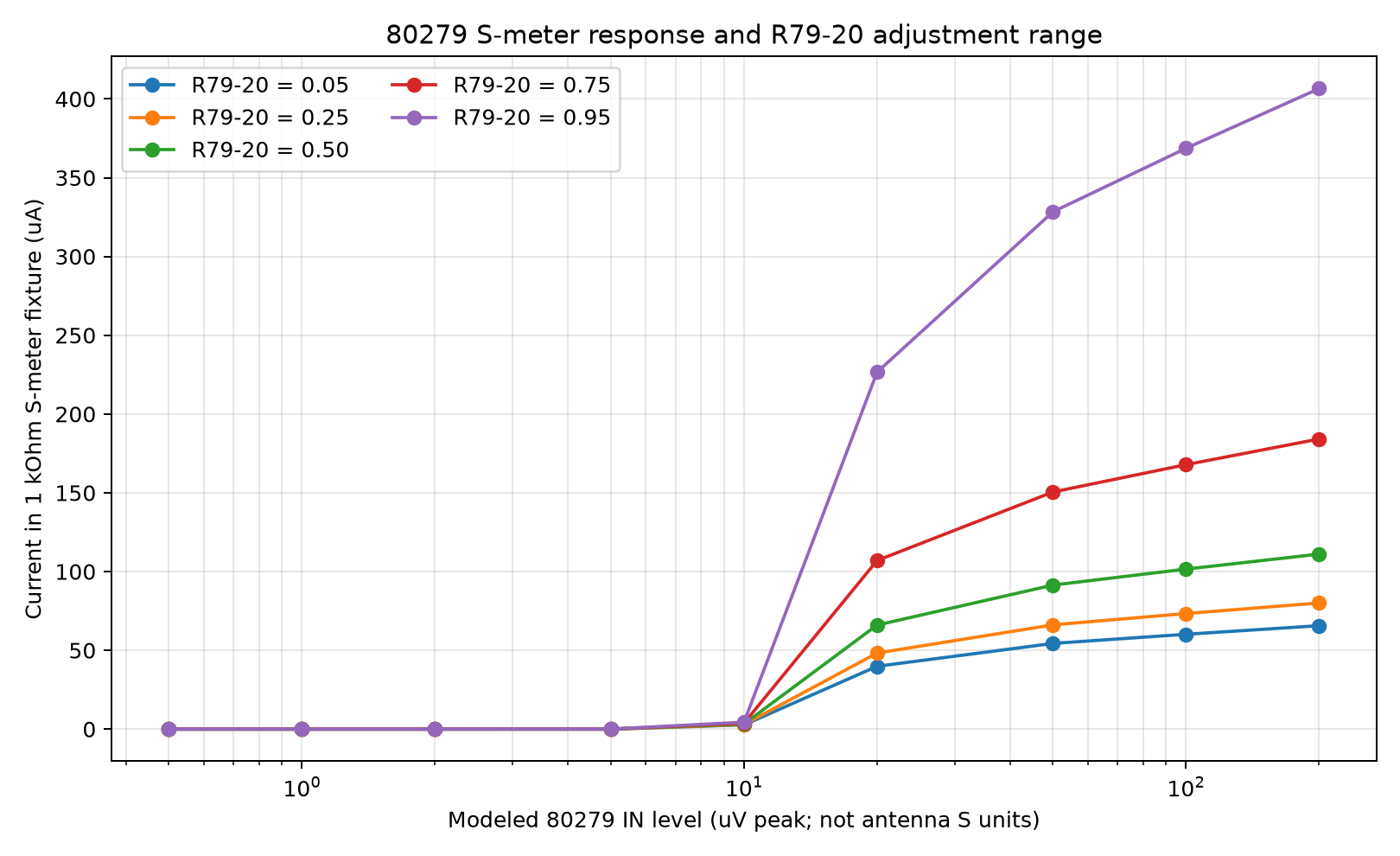
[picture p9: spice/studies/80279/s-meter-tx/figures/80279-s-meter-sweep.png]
80279 S-meter response


**Figure 79-9.** 80279 S-meter response

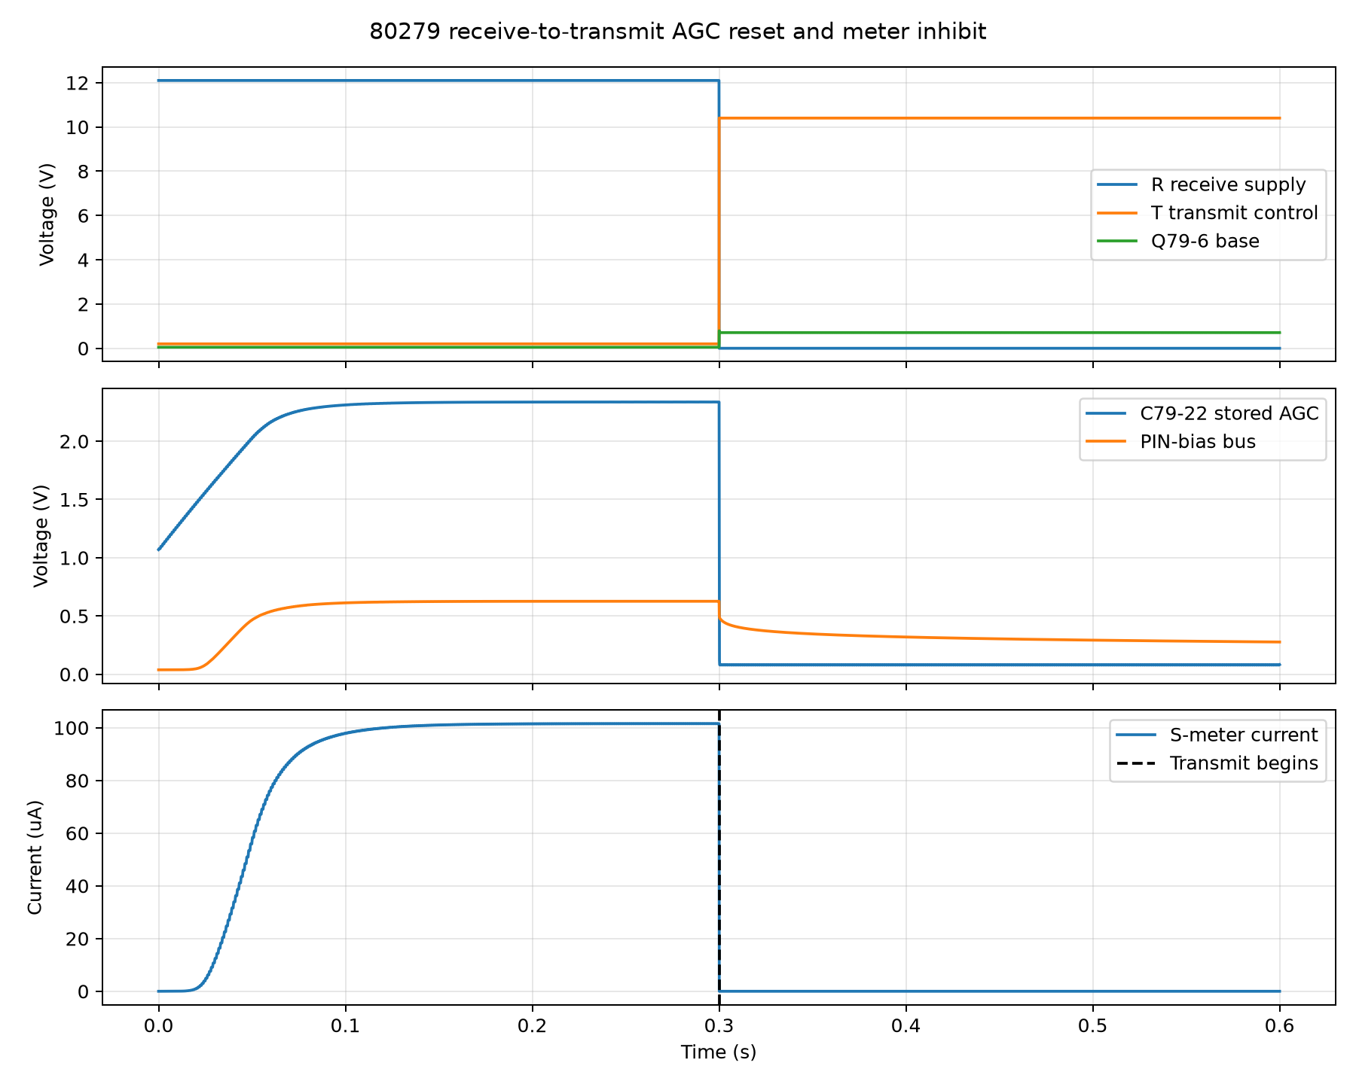
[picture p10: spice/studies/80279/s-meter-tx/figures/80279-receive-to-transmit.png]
80279 receive-to-transmit reset


**Figure 79-10.** 80279 receive-to-transmit reset

Complete method and evidence are in the
[Simulation 7 README](s-meter-tx/README.md). Regenerate with:

```powershell
python spice/tools/run_80279_s_meter_tx.py
```

## Model limits and interpretation

- MPS3693, HP 5082-3379, and RCA 40823 models are empirical, not original
  manufacturer SPICE models.
- The MC1747 wrapper preserves the physical 14-pin package, but its imported
  five-pin core does not model offset-null behavior, production spread, noise,
  temperature drift, or inter-section coupling.
- T79-1 and T79-2 inductance, coupling, resistance, Q, and parasitics are not
  documented factory values.
- Passing a model regression or exporting a netlist is not evidence that the
  complete board simulation is numerically or historically validated.
- Estimates and fitted parameters must remain labeled as such in every result.

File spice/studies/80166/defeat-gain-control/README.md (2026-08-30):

# 80166 DEFEAT gain reduction

This study tests a number Ten-Tec published and this project had never
checked: that energizing the crystal calibrator drops the RF amplifier's gain
by about 25 dB (Owner's Manual PDF p. 24 / printed p. 3-8).

The reduction happens at Q1's **gate 2**. A dual-gate MOSFET has two control
gates in series in the same channel; gate 1 takes the signal and gate 2 takes a
separate control voltage, and drain current depends on both. Gate 2 reaches the
outside world at the board's `DEFEAT` pin through R1 (33 kΩ), which pulls it
toward ground when nothing is driving it, and C4 (0.01 µF), which grounds it for
RF while leaving the DC control voltage alone. In normal reception `DEFEAT`
sits at about 3.9 V. When the calibrator is switched on, a TTL gate on that
assembly pulls the line low.

The circuit source is `triton_540.kicad_sch`. The study script exports a fresh
KiCad SPICE netlist on every run; it does not maintain a second hand-written
copy of the circuit.

## Configuration

- Bandswitch: `S4_POS=1` (3.5 MHz)
- Aligned rack model: `L_RACK=17.2 µH`, `C19=36 pF`
- L2 tracking fit: `L2 = 1.97963 µH + 0.0849053 × L_RACK`
- RF GAIN supply: `/R = 12 V` (RF CONTROL fully clockwise)
- Swept control: `/DEFEAT` from 3.9 V to 0 V in 17 steps, dense below 1 V
- Drive: `AC 1` through 50 Ω at `ANT`
- Load: the schematic's provisional `1 MΩ || 5 pF` at `OUT`
- AC sweep: 3.0–4.2 MHz, 10 000 points per decade
- A second run at every step asks for the DC operating point only, so the bias
  the stage settles at can be read beside the gain it delivers

Observation points are the board pins `ANT` and `OUT`. Q1's own terminals are
recorded from the operating-point runs, where a probe's capacitance would not
matter because nothing is moving.

## Runs

Each `/DEFEAT` step is two runs: an AC sweep and an operating point. They are
listed in [`manifest.csv`](manifest.csv).

## What the retained results show

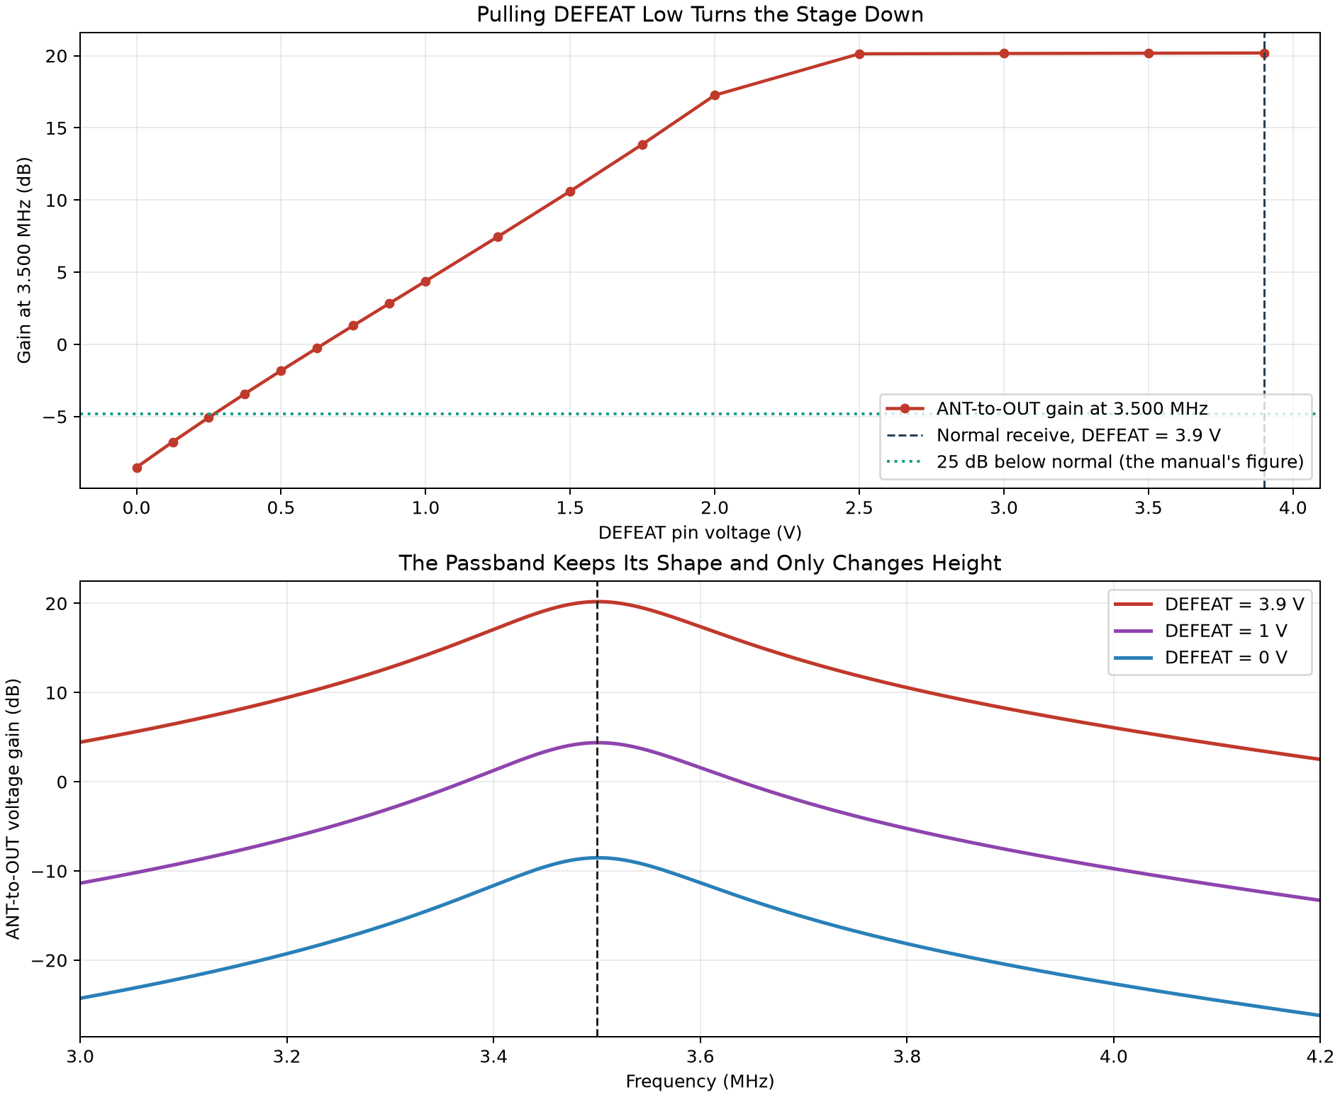
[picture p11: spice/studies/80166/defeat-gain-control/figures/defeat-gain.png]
ANT-to-OUT gain against DEFEAT voltage, and the response curves at 3.9 V and 0 V


**Figure 66-7.** ANT-to-OUT gain against DEFEAT voltage, and the response
curves at 3.9 V and 0 V

| `/DEFEAT` | Gain at 3.500 MHz | Change from normal | Drain current | V_GS | −3 dB bandwidth |
|--:|--:|--:|--:|--:|--:|
| 3.900 V | 20.189 dB | 0.000 dB | 4.407 mA | −1.021 V | 202.24 kHz |
| 3.500 V | 20.172 dB | −0.016 dB | 4.405 mA | −1.020 V | 202.24 kHz |
| 3.000 V | 20.152 dB | −0.036 dB | 4.401 mA | −1.018 V | 202.24 kHz |
| 2.500 V | 20.132 dB | −0.057 dB | 4.398 mA | −1.016 V | 202.24 kHz |
| 2.000 V | 17.263 dB | −2.925 dB | 4.362 mA | −0.999 V | 202.29 kHz |
| 1.750 V | 13.864 dB | −6.325 dB | 4.234 mA | −0.938 V | 202.34 kHz |
| 1.500 V | 10.611 dB | −9.577 dB | 4.029 mA | −0.840 V | 202.38 kHz |
| 1.250 V | 7.465 dB | −12.723 dB | 3.766 mA | −0.714 V | 202.40 kHz |
| 1.000 V | 4.381 dB | −15.808 dB | 3.461 mA | −0.567 V | 202.40 kHz |
| 0.875 V | 2.845 dB | −17.343 dB | 3.297 mA | −0.489 V | 202.40 kHz |
| 0.750 V | 1.306 dB | −18.883 dB | 3.126 mA | −0.407 V | 202.40 kHz |
| 0.625 V | −0.245 dB | −20.434 dB | 2.951 mA | −0.323 V | 202.39 kHz |
| 0.500 V | −1.817 dB | −22.006 dB | 2.771 mA | −0.237 V | 202.38 kHz |
| 0.375 V | −3.419 dB | −23.607 dB | 2.588 mA | −0.150 V | 202.36 kHz |
| 0.250 V | −5.061 dB | −25.249 dB | 2.403 mA | −0.061 V | 202.35 kHz |
| 0.125 V | −6.756 dB | −26.945 dB | 2.215 mA | +0.029 V | 202.33 kHz |
| 0.000 V | −8.520 dB | −28.708 dB | 2.027 mA | +0.120 V | 202.31 kHz |

Three things stand out.

**The reduction reaches the manual's figure.** The modelled cut at a fully
grounded `DEFEAT` line is 28.7 dB, a voltage ratio of about 27:1. The manual's
25 dB — a ratio of about 18:1 — is passed at roughly 0.25 V, which is the sort
of residual a real TTL gate leaves when it pulls a line low.

**The passband keeps its shape.** The −3 dB bandwidth moves from 202.24 kHz to
202.31 kHz across the whole sweep, a change of 0.03%, and the peak frequency
does not move by even one sample of the 0.81 kHz sweep grid. That is the
signature of a gain control that is not also a tuning control: gate 2 changes
the channel's transconductance without appearing across either tuned circuit.
If it did, the response would flatten and shift as the gain came down, and the
receiver would go off tune every time the calibrator was switched on.

**The control does nothing for the top third of its range.** From 3.9 V down to
2.5 V the gain moves 0.06 dB. Everything happens below about 2.5 V. This is not
a fault: gate 2 is a switch here, not a volume control, and the calibrator drives
it to a logic level rather than anywhere in between.

The drain current falls with the gain, from 4.41 mA to 2.03 mA, which is the
mechanism visible in a form a meter can read: with gate 2 taken down, less of
the channel is open, so less current flows and the transconductance that sets
the gain falls with it. Because R6 (470 Ω) sets the source voltage from that
current, V_GS relaxes from −1.02 V toward zero at the same time — self-bias
partly opposing the gain reduction, which is why the curve is a smooth slope
rather than a cliff.

## Resolution

The sweep is sampled on a logarithmic grid whose spacing is 806 Hz at 3.5 MHz.
Peak frequencies are quantized to that grid, so "the peak did not move" means
it moved by less than 0.81 kHz, not that it did not move at all. Gains at
3.500 MHz are interpolated between the two samples that straddle it and are not
limited by the grid in the same way.

## Evidence and limitations

- **Documented:** the approximately 25 dB gain reduction, the dual-gate
  topology, the 3.9 V normal-receive value on `DEFEAT`, and the calibrator's
  TTL gate as what pulls the line low, all from the Ten-Tec manual, PDF
  pp. 24–25 / printed pp. 3-8–3-9.
- **Calculated:** every gain, bandwidth, drain current and V_GS above, from
  the retained CSVs.
- **Fitted:** the rack inductance and L2 tracking equation, from the
  manual-sequence alignment study.
- **Model-dependent:** the size of the reduction. The empirical 40823 model's
  gate-2 section has an assumed threshold, so the shape of the knee and the
  final 28.7 dB are properties of that model, not of an RCA device. What the
  study establishes firmly is the *direction*, the *order of magnitude*, and
  the *absence of a shape change*.
- **Still provisional:** coil Q, tap ratios, and the `1 MΩ || 5 pF` OUT load.
  See the [loading-sensitivity study](../loading-sensitivity/README.md) for
  what that load is worth.

## Reproduce

With KiCad 10 and ngspice 46 installed at the paths configured near the top of
`spice/tools/run_80166_headless.py`, and the `RF_Amp_80166` sheet included in
simulation:

```powershell
python spice\tools\run_80166_defeat_gain.py
```

Curated CSVs and the figure are replaced in this directory. Exported netlists,
raw files and logs go to ignored `spice/generated/80166-defeat-gain/`.

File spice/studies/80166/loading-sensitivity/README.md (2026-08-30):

# 80166 output loading and coil-Q sensitivity

Every absolute gain figure in the 80166 board document carries the word
*provisional*, and this study is why. The schematic's `OUT` pin is loaded by a
placeholder `1 MΩ || 5 pF`, and the coil models default to an unloaded Q of 70
at a reference frequency of 14.2 MHz. Neither number came from Ten-Tec. Together
they produce peak gains above 70 dB and loaded Q values near 140 on the 21 MHz
band — useful for *finding* resonance during alignment, and meaningless as
predictions of what the receiver actually does.

The study does not try to produce one right answer. It maps how far the answer
moves when the two unknown quantities move, so a reader can see which
conclusions survive the uncertainty and which do not.

The circuit source is `triton_540.kicad_sch`. The study script exports a fresh
KiCad SPICE netlist on every run.

## What actually loads the OUT pin

The 80166's output goes to the 80287 receiver mixer's `Rx In` pin. Rather than
guess at that impedance, the runner exports the 80287 sub-sheet on its own,
drives `Rx In` with the `AC 1` source that sheet already carries, and divides
the applied volt by the current the source delivers:

| Frequency | Resistance | Reactance | Magnitude |
|--:|--:|--:|--:|
| 3.5 MHz | 993.8 Ω | −89.2 Ω | 997.8 Ω |
| 7.0 MHz | 986.5 Ω | −108.1 Ω | 992.4 Ω |
| 14.2 MHz | 959.0 Ω | −175.8 Ω | 974.9 Ω |
| 21.2 MHz | 920.9 Ω | −237.9 Ω | 951.1 Ω |
| 29.0 MHz | 871.3 Ω | −295.8 Ω | 920.1 Ω |

About **1 kΩ**, dominated by R87-8 and the receiver mixer-balance control R87-1
behind C87-1's 1000 pF coupling capacitor. That is a thousand times heavier than
the placeholder, and it is the row the map singles out.

This is a property of the reconstructed 80287, not a measurement of a real one,
so it is a much better guess than 1 MΩ rather than a known value.

## Configuration

Two band states from the retained alignment study:

| Band state | `S4_POS` | `L_RACK` | L2 trimmer | Sweep window |
|:--|--:|--:|:--|:--|
| 3.5 MHz | 1 | 17.2 µH | C19 = 36 pF | 2–6 MHz |
| 21.2 MHz | 4 | 2.06 µH | C15 = 16.94 pF | 12–32 MHz |

Common to every run: `/R = 12 V`, `/DEFEAT = 3.9 V`, `AC 1` through 50 Ω at
`ANT`, 20 000 points per decade, and the L2 tracking fit
`L2 = 1.97963 µH + 0.0849053 × L_RACK`.

Swept against each other:

- **`R66-100`, the OUT load resistance** — 1 MΩ, 100 kΩ, 22 kΩ, 10 kΩ, 4.7 kΩ,
  2.2 kΩ, 1 kΩ, 470 Ω. `C66-101`, the 5 pF shunt beside it, is left in place
  throughout. These two and the `ANT` drive network are simulation fixtures on
  the sub-sheet, not parts of the original assembly.
- **`QREF` on both `80166_L1` and `80166_L2`** — 70, 50, 30, 20, 10.

That is 8 × 5 × 2 = 80 AC sweeps, plus the one impedance run. They are listed in
[`manifest.csv`](manifest.csv).

## Reading the QREF parameter correctly

This turns out to be the most important thing the study found, so it belongs
before the results.

The coil models represent loss as a fixed series resistance, sized at a
reference frequency:

$$
R_\mathrm{series} = \frac{2\pi\,F_\mathrm{REF}\,L_T}{Q_\mathrm{REF}}
\qquad F_\mathrm{REF} = 14.2\ \mathrm{MHz}
$$

A fixed resistance means the coil's actual Q at any other frequency is

$$
Q(f) = \frac{2\pi f L_T}{R_\mathrm{series}}
= Q_\mathrm{REF}\,\frac{f}{F_\mathrm{REF}}
$$

The inductance cancels. **`QREF=70` therefore does not mean "a coil with a Q of
70".** It means a coil whose Q is 70 at 14.2 MHz, 17.3 at 3.5 MHz, and 143 at
29 MHz — Q rising in direct proportion to frequency. Real slug-tuned coils of
this era do not behave that way; their Q is roughly flat across HF and often
falls at the top.

That single modelling choice, not the output load, is what produces the
band-to-band gain spread the board document complains about.

## What the retained results show

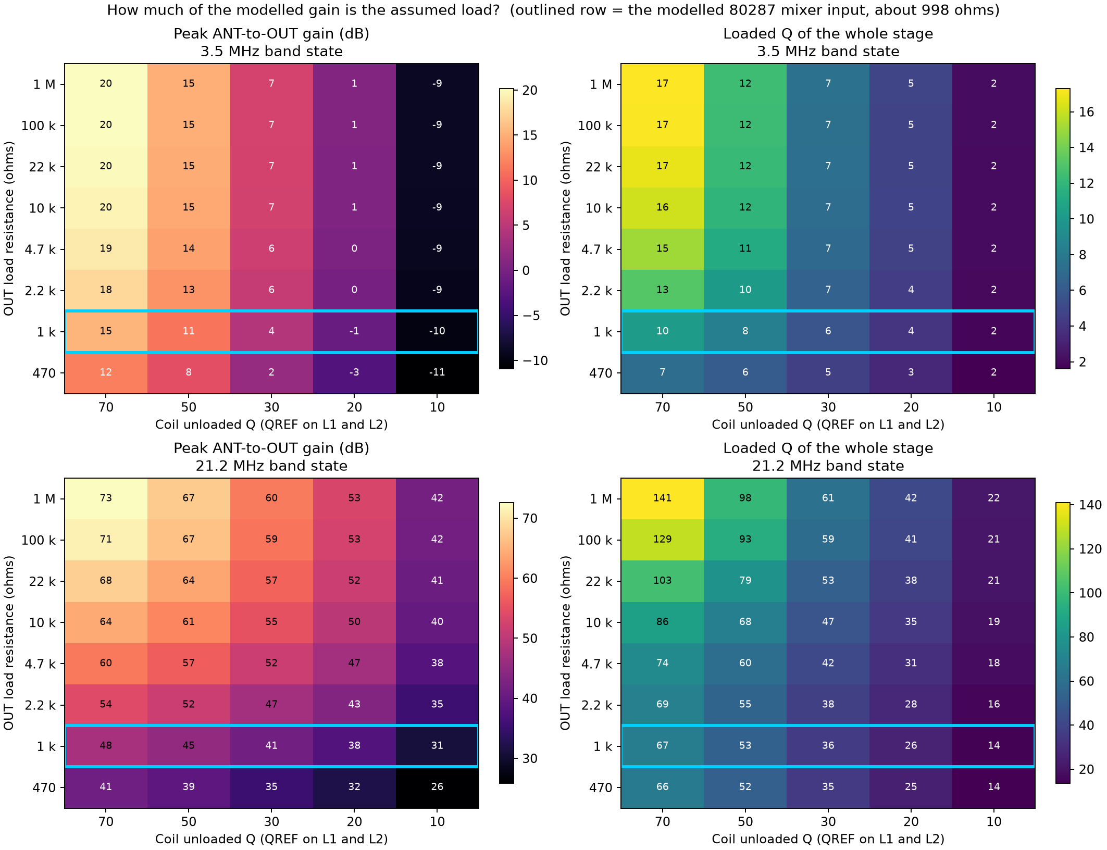
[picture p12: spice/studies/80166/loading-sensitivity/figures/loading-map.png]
Peak gain and loaded Q against OUT load resistance and coil Q, on two band states


**Figure 66-11.** Peak gain and loaded Q against OUT load resistance and coil
Q, on two band states

Four corners of the map, in words:

| Corner | 3.5 MHz peak | 3.5 MHz loaded Q | 21.2 MHz peak | 21.2 MHz loaded Q | Spread |
|:--|--:|--:|--:|--:|--:|
| 1 MΩ, `QREF`=70 (the schematic today) | 20.19 dB | 17.3 | 72.55 dB | 140.8 | 52.4 dB |
| 1 kΩ, `QREF`=70 | 15.34 dB | 10.3 | 47.62 dB | 66.9 | 32.3 dB |
| 1 kΩ, `QREF`=30 | 4.47 dB | 5.7 | 41.42 dB | 35.8 | 37.0 dB |
| 470 Ω, `QREF`=10 | −10.94 dB | 1.6 | 25.83 dB | 13.6 | 36.8 dB |

**The load matters far more on 21 MHz than on 3.5 MHz.** Going from 1 MΩ to
1 kΩ costs 4.9 dB at 3.5 MHz and 24.9 dB at 21.2 MHz. The reason is in the
table above: at 3.5 MHz the tuned circuits are already so lossy in this model
(coil Q 17.3) that the tank's own resistance dominates and an extra 1 kΩ across
a tapped winding barely registers. At 21 MHz the coils are modelled as very low
loss, so the external load is most of what damps them.

**Loading alone brings the numbers into plausible territory on 80 m but not on
15 m.** At the modelled mixer load with the default coil Q, 3.5 MHz gives
15.3 dB — comfortably inside the 10–20 dB the board document infers for a stage
like this — while 21.2 MHz still gives 47.6 dB, which no single dual-gate MOSFET
stage into a 1 kΩ load produces.

**Lowering the coil Q does not close the gap; it widens it again.** That is the
`Q(f) = QREF × f/FREF` relation biting: reducing `QREF` takes proportionally
more away from the low band, where the modelled Q is already smallest.

So the honest conclusion is a *partial* one. The study bounds what the
placeholder load was worth — about 5 dB on 80 m and about 25 dB on 15 m — and it
identifies the remaining error as living in the coil-loss model's frequency
dependence, not in the load. Until the loss model is given a frequency behaviour
that matches a real coil, no absolute gain figure on the higher bands can be
supported, whatever load is used.

## What would settle it

Bench check 3 in the board document sweeps ANT-to-OUT on 80 m and reports the
measured −3 dB bandwidth and loaded Q. **That single measurement picks the row
and column of this map**, because at 3.5 MHz the loaded Q is set almost entirely
by coil loss:

| If bench check 3 measures a loaded Q of about… | …the 3.5 MHz coil Q is about… | …which corresponds to `QREF` ≈ |
|--:|--:|--:|
| 17 | 17 | 70 |
| 12 | 12 | 50 |
| 7 | 7 | 30 |
| 5 | 5 | 20 |

A second sweep on 21 MHz would then say directly whether the coil Q rises with
frequency the way the model assumes. **That bench data does not exist yet**, so
this study reports the whole map rather than choosing a corner.

## Resolution

Sweeps are sampled on a logarithmic grid: 403 Hz per step at 3.5 MHz and
2.44 kHz at 21.2 MHz. Peak frequencies are quantized to
that spacing. Bandwidths are interpolated between the samples straddling each −3 dB crossing, and the loaded
Q figures are peak frequency divided by that bandwidth, so they inherit the
same precision. None of the Q values here is meaningful past two significant
figures.

Where the coils are very lossy the response peak shifts as well as broadens —
on 3.5 MHz it moves from 3.5009 MHz at `QREF`=70 to 3.3341 MHz at `QREF`=10 and
a 470 Ω load. That is real and worth noting: **a radio with tired coils would
need re-aligning, not just accepting as quieter.**

## Evidence and limitations

- **Documented:** nothing in this study is a Ten-Tec figure. The manual gives
  no gain, bandwidth or Q specification for this board.
- **Calculated:** every peak, bandwidth and loaded Q above, from the retained
  CSVs, and the `Q(f)` relation from the model library's own expressions.
- **Model-dependent:** the 1 kΩ mixer input is the reconstructed 80287's
  impedance, not a measured one. The tap fractions on both coils (`FANT`,
  `FG1`, `FDRN`, `FOUT`) are schematic-based estimates and were **not** swept
  here; they are the other obvious candidate for the residual band-to-band
  error and deserve their own study.
- **Not established:** the real loaded Q of either coil at any frequency, and
  therefore any absolute gain figure for this board.

## Reproduce

With KiCad 10 and ngspice 46 installed at the paths configured near the top of
`spice/tools/run_80166_headless.py`, and the `RF_Amp_80166` sheet included in
simulation:

```powershell
python spice\tools\run_80166_loading_sensitivity.py
```

The run takes a few minutes. Curated CSVs and the figure are replaced in this
directory. Exported netlists, raw files and logs go to ignored
`spice/generated/80166-loading/`.

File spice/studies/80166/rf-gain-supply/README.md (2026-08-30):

# 80166 RF GAIN as the stage's supply

The `R` pin looks like a 12 V rail and is not one. Ten-Tec is explicit: *"The
stage is powered through the RF GAIN terminal, which connects to a variable DC
voltage obtained from RF control"* (Owner's Manual PDF p. 24 / printed p. 3-8).
Turning the front-panel RF GAIN knob down literally lowers this board's supply
voltage.

That matters more than it first appears, because **R4 (470 kΩ) hangs off the
same decoupled node as the drain feed**. R5 (100 Ω) and C6 (0.1 µF) form that
node; L2's cold end, Q1's drain supply and R4 all sit on it. R4 and R3 (47 kΩ)
divide it down to set gate 1's DC voltage. So one knob moves two things at once:

- the **drain supply**, which sets how much voltage swing the tuned load can
  develop, and
- the **gate-1 bias**, which with R6's self-bias sets the drain current and
  therefore the transconductance.

This study puts both mechanisms and the resulting gain on one voltage axis.

The circuit source is `triton_540.kicad_sch`. The study script exports a fresh
KiCad SPICE netlist on every run; it does not maintain a second hand-written
copy of the circuit.

## Configuration

- Bandswitch: `S4_POS=1` (3.5 MHz)
- Aligned rack model: `L_RACK=17.2 µH`, `C19=36 pF`
- L2 tracking fit: `L2 = 1.97963 µH + 0.0849053 × L_RACK`
- `/DEFEAT` held at 3.9 V — the calibrator is off throughout, so the only
  thing moving is the supply
- Swept supply: `/R` from 12 V to 0 V
- Drive: `AC 1` through 50 Ω at `ANT`
- Load: the schematic's provisional `1 MΩ || 5 pF` at `OUT`
- Bias: one `.dc` run stepping `/R` in 50 mV steps, 241 points
- Gain: fifteen separate AC sweeps, 3.0–4.2 MHz at 10 000 points per decade,
  because an AC analysis linearizes about one operating point and cannot itself
  sweep a DC supply

ngspice will not accept a hyphenated source name on a `.dc` card, and every
Ten-Tec reference on this board is hyphenated, so the bias run renames `V66-2`
to `VRFGAIN` in its own generated copy of the netlist.

Observation points are the board pins `ANT` and `OUT`. Q1's terminals come from
the DC run, where nothing is moving and probe capacitance would not matter; on
hardware the equivalent numbers come from a meter, exactly as in bench check 1.

## Runs

The single bias sweep and the fifteen AC sweeps are listed in
[`manifest.csv`](manifest.csv).

## What the retained results show

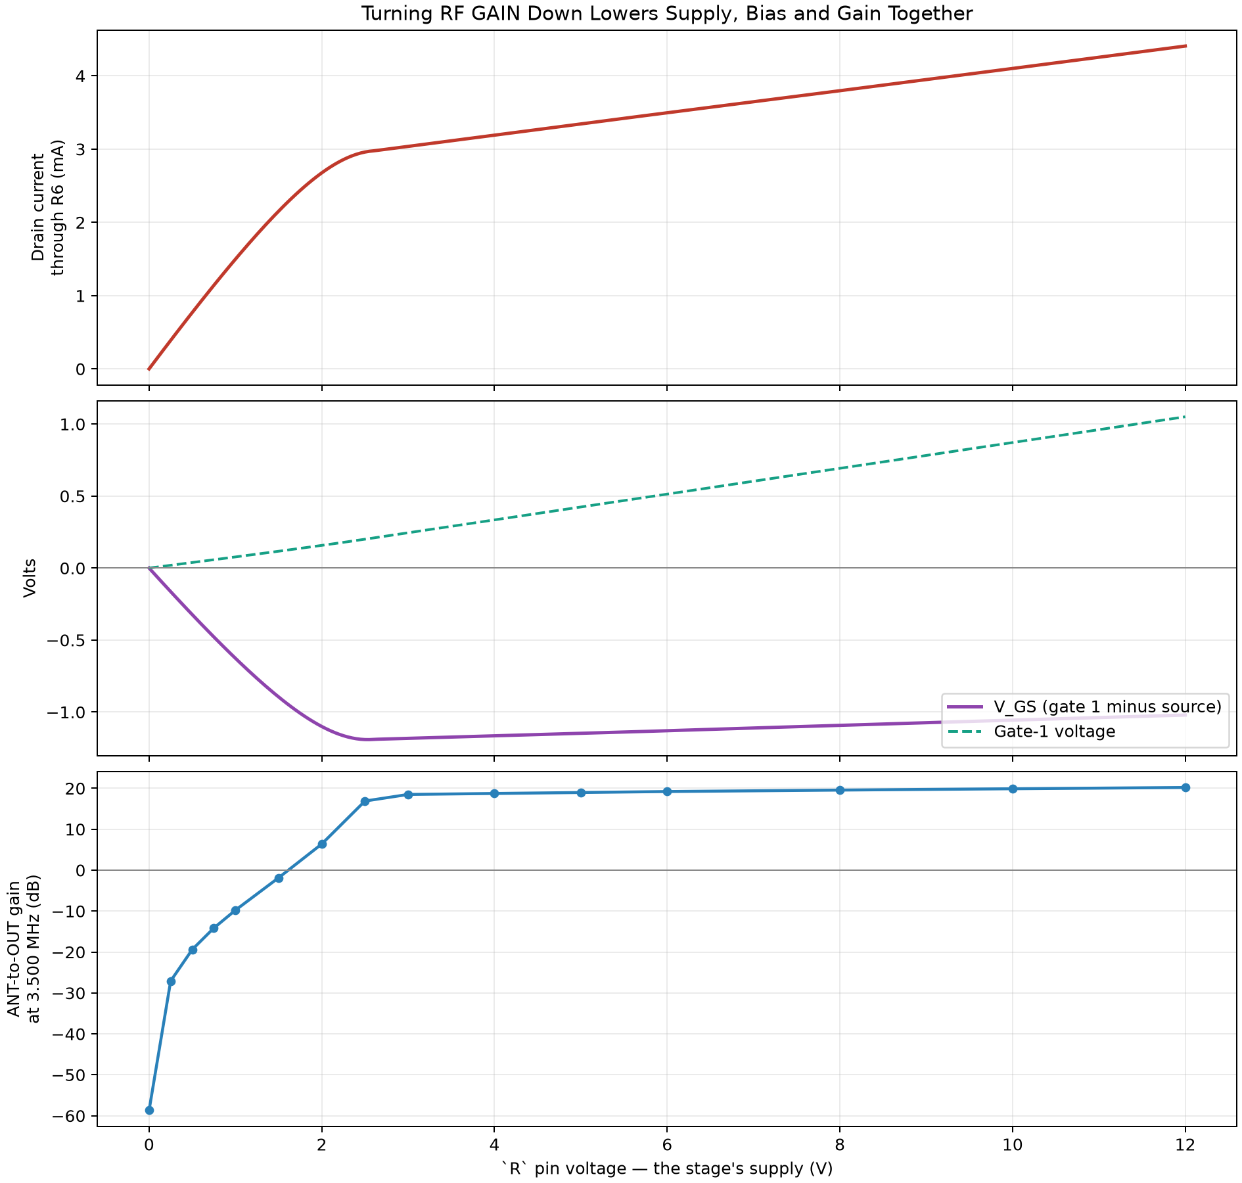
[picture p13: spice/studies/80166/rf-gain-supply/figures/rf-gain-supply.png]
Drain current, gate bias and gain against the RF GAIN supply voltage


**Figure 66-8.** Drain current, gate bias and gain against the RF GAIN supply
voltage

| `/R` | Gate 1 | Source | V_GS | Drain current | Drain | Gain at 3.500 MHz | Change | −3 dB BW |
|--:|--:|--:|--:|--:|--:|--:|--:|--:|
| 12.00 V | 1.051 V | 2.071 V | −1.021 V | 4.407 mA | 11.547 V | 20.189 dB | 0.000 dB | 202.2 kHz |
| 10.00 V | 0.872 V | 1.928 V | −1.056 V | 4.101 mA | 9.579 V | 19.883 dB | −0.305 dB | 202.2 kHz |
| 8.00 V | 0.693 V | 1.785 V | −1.092 V | 3.797 mA | 7.611 V | 19.556 dB | −0.633 dB | 202.2 kHz |
| 6.00 V | 0.514 V | 1.643 V | −1.130 V | 3.496 mA | 5.642 V | 19.204 dB | −0.985 dB | 202.2 kHz |
| 5.00 V | 0.424 V | 1.572 V | −1.148 V | 3.344 mA | 4.658 V | 18.964 dB | −1.225 dB | 203.3 kHz |
| 4.00 V | 0.335 V | 1.499 V | −1.165 V | 3.190 mA | 3.674 V | 18.731 dB | −1.457 dB | 203.4 kHz |
| 3.00 V | 0.245 V | 1.427 V | −1.182 V | 3.037 mA | 2.689 V | 18.491 dB | −1.698 dB | 203.4 kHz |
| 2.50 V | 0.200 V | 1.391 V | −1.191 V | 2.960 mA | 2.197 V | 16.880 dB | −3.308 dB | 225.1 kHz |
| 2.00 V | 0.157 V | 1.258 V | −1.100 V | 2.676 mA | 1.727 V | 6.390 dB | −13.799 dB | 396.4 kHz |
| 1.50 V | 0.117 V | 1.012 V | −0.895 V | 2.153 mA | 1.280 V | −1.863 dB | −22.051 dB | 535.2 kHz |
| 1.00 V | 0.077 V | 0.704 V | −0.627 V | 1.498 mA | 0.847 V | −9.780 dB | −29.968 dB | 651.9 kHz |
| 0.75 V | 0.058 V | 0.536 V | −0.478 V | 1.141 mA | 0.633 V | −14.148 dB | −34.337 dB | 704.0 kHz |
| 0.50 V | 0.038 V | 0.362 V | −0.323 V | 0.770 mA | 0.421 V | −19.390 dB | −39.578 dB | 752.5 kHz |
| 0.25 V | 0.019 V | 0.183 V | −0.164 V | 0.389 mA | 0.210 V | −27.077 dB | −47.265 dB | 798.0 kHz |
| 0.00 V | 0.000 V | 0.000 V | 0.000 V | 0.000 mA | 0.000 V | −58.676 dB | −78.864 dB | 840.6 kHz |

**Gate 1 tracks the supply exactly.** At every point in the table, gate 1 is
9.09% of the decoupled node, which is 470 kΩ and 47 kΩ doing arithmetic. That is
the second mechanism, visible and measurable with a meter.

**Drain current and gain fall smoothly and never reverse.** Both move
monotonically with the supply, and the stage is completely off at 0 V — no
current, no bias, 58.7 dB of loss where there was 20.2 dB of gain. There is no
discontinuity anywhere in the 241-point bias sweep.

**V_GS is the exception, and it is not monotonic.** It deepens from −1.021 V at
12 V to about −1.19 V near 2.5 V, then relaxes back toward zero as the supply
runs out. That is R6's self-bias doing its job in both directions: on the way
down, gate 1 falls faster than the source does, so the gate goes more negative
relative to the source; below about 2.5 V there is no longer enough drain
voltage to sustain the current, the source voltage collapses, and V_GS follows
it back to zero. **Gain does not turn round with it** — the reversal in V_GS is
a consequence of the stage shutting off, not a second control mechanism, and
the gain curve is smooth and monotonic straight through it.

**The control is very unevenly distributed.** From 12 V down to 3 V, three
quarters of the supply range, the gain falls only 1.7 dB. Everything else
happens in the last 3 V. In receiver terms: over most of the RF GAIN knob's
travel the gain is barely changing, and the useful part of the control is
crowded into the last part of its rotation. Whether the real radio behaves that
way depends on what the front-panel control actually delivers to the `R` pin,
which is a measurement nobody has made — the last row of bench check 1 is
exactly that measurement, and it is why it is there.

**Bandwidth widens as the supply falls**, from 202 kHz to 841 kHz, and the
peak drifts up by about 8 kHz. That is the transistor's own input and output
capacitances changing with bias, and its output resistance falling, both of
which load the tuned circuits. A restorer would notice this as the receiver
going slightly broader and slightly off-peak when RF GAIN is well down — not as
a fault.
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

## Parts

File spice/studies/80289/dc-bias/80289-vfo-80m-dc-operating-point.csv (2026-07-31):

analysis | schematic | band | s4_pos | temperature_c | reference | terminal | net | voltage_v | model_context | note
80289 VFO 80 m DC operating point | triton_540.kicad_sch | 80 m | 1 | 27 | SUPPLY | +12 | /vfo-80289/+12 | 13.800000 | system | Manual service-table supply condition
80289 VFO 80 m DC operating point | triton_540.kicad_sch | 80 m | 1 | 27 | SUPPLY | +REG | /vfo-80289/+reg | 8.000000 | system | Regulated VFO supply
80289 VFO 80 m DC operating point | triton_540.kicad_sch | 80 m | 1 | 27 | SUPPLY | OFFSET | /vfo-80289/offset | 3.100000 | system | Centered OFFSET control
80289 VFO 80 m DC operating point | triton_540.kicad_sch | 80 m | 1 | 27 | Q89-1 | D | net-_q89-1-d_ | 12.510000 | system | 2N5486 drain
80289 VFO 80 m DC operating point | triton_540.kicad_sch | 80 m | 1 | 27 | Q89-1 | G | net-_q89-1-g_ | 6.669910 | system | 2N5486 gate
80289 VFO 80 m DC operating point | triton_540.kicad_sch | 80 m | 1 | 27 | Q89-1 | S | net-_q89-1-s_ | 7.579380 | system | 2N5486 source
80289 VFO 80 m DC operating point | triton_540.kicad_sch | 80 m | 1 | 27 | Q89-2 | C | net-_q89-1-d_ | 12.510000 | system | MPS6514 collector
80289 VFO 80 m DC operating point | triton_540.kicad_sch | 80 m | 1 | 27 | Q89-2 | B | net-_q89-1-s_ | 7.579380 | system | MPS6514 base
80289 VFO 80 m DC operating point | triton_540.kicad_sch | 80 m | 1 | 27 | Q89-2 | E | net-_q89-2-e_ | 6.852380 | system | MPS6514 emitter
80289 VFO 80 m DC operating point | triton_540.kicad_sch | 80 m | 1 | 27 | Q89-3 | D | net-_q89-3-d_ | 7.752830 | system | 2N5486 drain
80289 VFO 80 m DC operating point | triton_540.kicad_sch | 80 m | 1 | 27 | Q89-3 | G | net-_d89-1-a_ | -2.200000 | system | 2N5486 gate
80289 VFO 80 m DC operating point | triton_540.kicad_sch | 80 m | 1 | 27 | Q89-3 | S | net-_q89-3-s_ | 0.024472 | system | 2N5486 source
80289 VFO 80 m DC operating point | triton_540.kicad_sch | 80 m | 1 | 27 | Q89-4 | C | net-_q89-4-c_ | 5.294010 | system | MPS6514 collector
80289 VFO 80 m DC operating point | triton_540.kicad_sch | 80 m | 1 | 27 | Q89-4 | B | net-_q89-4-b_ | 1.156890 | system | MPS6514 base
80289 VFO 80 m DC operating point | triton_540.kicad_sch | 80 m | 1 | 27 | Q89-4 | E | net-_q89-4-e_ | 0.452307 | system | MPS6514 emitter
80289 VFO 80 m DC operating point | triton_540.kicad_sch | 80 m | 1 | 27 | Q89-5 | C | net-_q89-5-c_ | 7.939260 | behavioral PTO substitute | Q89-5 excluded; node voltage only
80289 VFO 80 m DC operating point | triton_540.kicad_sch | 80 m | 1 | 27 | Q89-5 | B | net-_q89-5-b_ | 2.531360 | behavioral PTO substitute | Q89-5 excluded; node voltage only
80289 VFO 80 m DC operating point | triton_540.kicad_sch | 80 m | 1 | 27 | Q89-5 | E | net-_q89-5-e_ | 1.700000 | behavioral PTO substitute | Forced by V_PTO_IDEAL; not transistor bias
80289 VFO 80 m DC operating point | triton_540.kicad_sch | 80 m | 1 | 27 | U89-1 | 1 | net-_r89-4-pad2_ | 7.358900 | system | MC1496 physical pin 1
80289 VFO 80 m DC operating point | triton_540.kicad_sch | 80 m | 1 | 27 | U89-1 | 2 | net-_r89-7-pad1_ | 6.474860 | system | MC1496 physical pin 2
80289 VFO 80 m DC operating point | triton_540.kicad_sch | 80 m | 1 | 27 | U89-1 | 3 | net-_r89-7-pad2_ | 6.029160 | system | MC1496 physical pin 3
80289 VFO 80 m DC operating point | triton_540.kicad_sch | 80 m | 1 | 27 | U89-1 | 4 | net-_c89-2-pad1_ | 6.821050 | system | MC1496 physical pin 4
80289 VFO 80 m DC operating point | triton_540.kicad_sch | 80 m | 1 | 27 | U89-1 | 5 | net-_u89-1-bias_ | 3.890990 | system | MC1496 physical pin 5
80289 VFO 80 m DC operating point | triton_540.kicad_sch | 80 m | 1 | 27 | U89-1 | 6 | net-_s89-1c-c-com_ | 12.749000 | system | MC1496 physical pin 6
80289 VFO 80 m DC operating point | triton_540.kicad_sch | 80 m | 1 | 27 | U89-1 | 7 | net-_s89-1c-c-com_ | 12.749000 | system | MC1496 physical pin 7
80289 VFO 80 m DC operating point | triton_540.kicad_sch | 80 m | 1 | 27 | U89-1 | 8 | net-_u89-1-input_carrier_ | 10.036100 | system | MC1496 physical pin 8
80289 VFO 80 m DC operating point | triton_540.kicad_sch | 80 m | 1 | 27 | U89-1 | 10 | net-_u89-1-carrier_input_ | 10.032000 | system | MC1496 physical pin 10
80289 VFO 80 m DC operating point | triton_540.kicad_sch | 80 m | 1 | 27 | U89-1 | 12 | net-_r89-13-pad2_ | 12.780800 | system | MC1496 physical pin 12
80289 VFO 80 m DC operating point | triton_540.kicad_sch | 80 m | 1 | 27 | U89-1 | 14 | gnd | 0.000000 | system | MC1496 physical pin 14

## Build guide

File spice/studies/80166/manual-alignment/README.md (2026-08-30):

# 80166 manual-alignment study

This directory contains the curated evidence used by the AC-alignment section
of the project-level [`80166.md`](../../../../80166.md).

## Contents

- `manifest.csv` records the purpose and settings of each retained run.
- `data/final/` contains the L1-bypassed and final response for each manual
  alignment frequency, plus the saved-schematic validation run.
- `data/29mhz-iterations/` contains only the C13 trials used by the 29 MHz
  convergence figure.
- `fixtures/` contains the corrected placement image for the temporary
  0.01 µF L2-bypass capacitor.
- `figures/` contains plots generated from the retained CSVs:
  `all-bands.png` (normalized final response on every band),
  `29mhz-adjustment.png` (the rack-then-C13 sequence), and
  `alignment-split.png` (the ANT-to-OUT overlay of the L1-only and
  full-stage responses, which is the same pin-to-pin ratio the bench
  sweep in [`bench/80166`](../../../../bench/80166/README.md) produces).

The long original export filenames have been replaced by stable run IDs.
Electrical settings and provenance belong in `manifest.csv`, not in filenames.

`data/29mhz-iterations/` is the deliberate exception. Those files are a
convergence sequence in a single variable, and the C13 value in each name is
what distinguishes one iteration from the next; carrying it in the filename
keeps the sequence readable in directory order and in the figure's legend.
Every run, iterations included, still has a full row in `manifest.csv`.

Regenerate both figures with:

```powershell
python spice\tools\plot_80166_manual_alignment.py
```

Absolute gain from these lightly loaded models is not treated as a receiver
specification. The alignment study uses peak frequency and loss at the manual
target as its primary results.

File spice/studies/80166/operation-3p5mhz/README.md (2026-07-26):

# 80166 normal operation at 3.5 MHz

This study shows the reconstructed RF-amplifier board doing its normal job:
the RESONATE rack places the two tuned circuits on the wanted frequency, a
small RF signal reaches Q1, and the selected signal grows as it passes through
the input network, active stage, and output network.

The circuit source is `triton_540.kicad_sch`. The study script exports a fresh
KiCad SPICE netlist on every run; it does not maintain a second hand-written
copy of the circuit.

## Configuration

- Bandswitch: `S4_POS=1` (3.5 MHz)
- Normal receive supplies: `/R=12 V`, `/DEFEAT=3.9 V`
- Aligned rack model: `L_RACK=17.2 µH`
- 3.5 MHz L2 trimmer: `C19=36 pF`
- L2 tracking fit:
  `L2=1.97963 µH + 0.0849053 × L_RACK`
- Output load: the schematic's provisional `1 MΩ || 5 pF`
- Generator: 3.5 MHz, 10 µV peak, with 50 Ω series resistance
- Transient run: 2 ns maximum step, 60 µs duration

The 10 µV figure is the generator's open-circuit peak voltage. The tuned
network loads the 50 Ω source, so the voltage actually present at the board's
`ANT` node is 0.927 µV peak. Gains in this study are referenced to that
measured `ANT` voltage, not to the source's unloaded setting.

## What the retained results show

[`figures/rack-tuning.png`](figures/rack-tuning.png) compares frequency sweeps
at three rack settings. Increasing `L_RACK` moves the response downward in
frequency, as expected from

$$
f_0 = \frac{1}{2\pi\sqrt{LC}}.
$$

At the manual-aligned 17.2 µH setting, the modeled response peaks at
3.5012 MHz and gives 20.189 dB voltage gain at exactly 3.500 MHz. The coarse
rack sweep found a marginally larger 20.240 dB at 17.0 µH—a difference of
only 0.052 dB. This is smaller than the precision justified by the provisional
coil-loss and output-load models.

[`figures/signal-walk.png`](figures/signal-walk.png) shows both the buildup of
the resonant response after the sine source starts and the final six RF
cycles. The DC bias is removed from the waveform panels so the microvolt RF
can be seen clearly.

| Circuit point | RF peak | Voltage ratio from `ANT` | Gain from `ANT` |
|:--|--:|--:|--:|
| Board `ANT` node | 0.927 µV | 1.000× | 0.000 dB |
| Q1 gate 1 | 2.459 µV | 2.654× | 8.477 dB |
| Q1 drain | 5.669 µV | 6.119× | 15.733 dB |
| Board `OUT` node | 9.469 µV | 10.220× | 20.189 dB |

The increase from `ANT` to gate 1 is resonant voltage transformation in the
L1 input network; it is not transistor gain. The 7.256 dB increase from gate
1 to drain is produced by Q1 acting into L2's resonant drain load. The final
4.456 dB from drain to `OUT` is the voltage transformation through the tapped
L2 output network in this model. Those three contributions add to the
20.189 dB overall voltage ratio.

The upper plot's approximately 10 µs settling time is the simulated resonant
circuits building to steady state after a suddenly applied sine wave. It is
not an AGC time constant or a claim about receiver audio response.

## Evidence and limitations

- **Documented:** the single-stage dual-gate-MOSFET topology, the 3.5 MHz
  alignment frequency, the bandswitch arrangement, and the normal receive
  bias are from the Ten-Tec manual, PDF pp. 24–25 / printed pp. 3-8–3-9.
- **Fitted:** the rack inductance and L2 tracking equation come from the
  manual-sequence alignment study.
- **Calculated:** all amplitudes and gains above are calculated from the
  retained transient CSV.
- **Still provisional:** coil Q, tap ratios, the 40823 model, and the
  `1 MΩ || 5 pF` OUT load. The results demonstrate circuit action and relative
  voltage gain; they are not a factory gain specification or a prediction of
  loaded power gain in an original radio.

## Reproduce

With KiCad 10 and ngspice 46 installed at the paths configured near the top of
the script:

```powershell
python spice\tools\run_80166_operation.py
```

Curated CSVs and plots are replaced in this directory. Exported netlists, raw
files, and logs go to ignored `spice/generated/80166-operation/`.

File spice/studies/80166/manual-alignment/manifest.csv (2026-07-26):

run_id | manual_step | target_hz | s4_pos | l_rack_uH | l2_adjustment | c99 | status | source | data_file | notes
3p5_l1_bypassed | 3 | 3500000 | 1 | 17.2 | C19=30p | 10n | bypassed | KiCad Simulator | data/final/3p5_l1-bypassed.csv | L2 resonance suppressed
3p5_aligned | 6 | 3500000 | 1 | 17.2 | C19=36p and tracking fit | removed | final | KiCad Simulator | data/final/3p5_aligned.csv | Low-band tracking check
4p0_l1_bypassed | 5 | 4000000 | 1 | 7.7 | C19=36p | 10n | bypassed | KiCad Simulator | data/final/4p0_l1-bypassed.csv | L2 resonance suppressed
4p0_aligned | 6 | 4000000 | 1 | 7.7 | L2 tracking fit | removed | final | KiCad Simulator | data/final/4p0_aligned.csv | High endpoint of low-band tracking
7p0_l1_bypassed | 7 | 7000000 | 2 | 3.43 | C17=60p | 10n | bypassed | KiCad Simulator | data/final/7p0_l1-bypassed.csv | L2 resonance suppressed
7p0_aligned | 7 | 7000000 | 2 | 3.43 | C17 about 68p effective | removed | final | KiCad Simulator | data/final/7p0_aligned.csv | Includes about 8p inferred parasitic capacitance
14p2_l1_bypassed | 8 | 14200000 | 3 | 2.84 | C16=30p | 10n | bypassed | KiCad Simulator | data/final/14p2_l1-bypassed.csv | L2 resonance suppressed
14p2_aligned | 8 | 14200000 | 3 | 2.84 | C16=47.2p | removed | final | KiCad Simulator | data/final/14p2_aligned.csv | Corrected pF-valued rerun
21p2_l1_bypassed | 8 | 21200000 | 4 | 2.06 | C15=30p | 10n | bypassed | KiCad Simulator | data/final/21p2_l1-bypassed.csv | L2 resonance suppressed
21p2_aligned | 8 | 21200000 | 4 | 2.06 | C15=16.94p | removed | final | KiCad Simulator | data/final/21p2_aligned.csv | Centered retained result
29p0_l1_bypassed | 8 | 29000000 | 5 | 1.4253 | C13=24p with C14=30p | 10n | bypassed | ngspice 46 from KiCad export | data/final/29p0_l1-bypassed.csv | L2 resonance suppressed
29p0_aligned | 8 | 29000000 | 5 | 1.4253 | C13=5.787p with C14=30p | removed | final | ngspice 46 from KiCad export | data/final/29p0_aligned.csv | Peak at 28.999365 MHz
29p0_saved_schematic_validation | 8 | 29000000 | 5 | 1.4253 | C13=5.787p with C14=30p | removed | validation | ngspice 46 from fresh KiCad export | data/final/29p0_saved-schematic-validation.csv | Reproduces final fitted result
29p0_c13_24p | 8 | 29000000 | 5 | 1.4253 | C13=24p with C14=30p | removed | iteration | ngspice 46 from KiCad export | data/29mhz-iterations/29p0_c13-24p.csv | Initial output-network setting
29p0_c13_8p07 | 8 | 29000000 | 5 | 1.4253 | C13=8.07p with C14=30p | removed | iteration | ngspice 46 from KiCad export | data/29mhz-iterations/29p0_c13-8p07.csv
29p0_c13_6p70 | 8 | 29000000 | 5 | 1.4253 | C13=6.70p with C14=30p | removed | iteration | ngspice 46 from KiCad export | data/29mhz-iterations/29p0_c13-6p70.csv
29p0_c13_6p35 | 8 | 29000000 | 5 | 1.4253 | C13=6.35p with C14=30p | removed | iteration | ngspice 46 from KiCad export | data/29mhz-iterations/29p0_c13-6p35.csv
29p0_c13_6p21 | 8 | 29000000 | 5 | 1.4253 | C13=6.21p with C14=30p | removed | iteration | ngspice 46 from KiCad export | data/29mhz-iterations/29p0_c13-6p21.csv
29p0_c13_6p13 | 8 | 29000000 | 5 | 1.4253 | C13=6.13p with C14=30p | removed | iteration | ngspice 46 from KiCad export | data/29mhz-iterations/29p0_c13-6p13.csv
29p0_c13_5p95 | 8 | 29000000 | 5 | 1.4253 | C13=5.95p with C14=30p | removed | iteration | ngspice 46 from KiCad export | data/29mhz-iterations/29p0_c13-5p95.csv
29p0_c13_5p865 | 8 | 29000000 | 5 | 1.4253 | C13=5.865p with C14=30p | removed | iteration | ngspice 46 from KiCad export | data/29mhz-iterations/29p0_c13-5p865.csv
29p0_c13_5p81 | 8 | 29000000 | 5 | 1.4253 | C13=5.81p with C14=30p | removed | iteration | ngspice 46 from KiCad export | data/29mhz-iterations/29p0_c13-5p81.csv

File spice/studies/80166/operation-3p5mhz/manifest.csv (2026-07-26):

artifact | type | provenance | description
data/ac/rack-15p4u.csv | AC response | ngspice 46 from fresh KiCad export | OUT/ANT and internal voltage ratios with L_RACK=15.4u
data/ac/rack-17p2u.csv | AC response | ngspice 46 from fresh KiCad export | Manual-aligned 3.5 MHz response with L_RACK=17.2u
data/ac/rack-19p4u.csv | AC response | ngspice 46 from fresh KiCad export | OUT/ANT and internal voltage ratios with L_RACK=19.4u
data/ac/rack-gain-at-3p5.csv | rack sweep summary | calculated from ngspice AC runs | Gain at 3.500 MHz and peak data versus L_RACK
data/transient/envelope.csv | transient envelope | calculated from ngspice transient run | Per-cycle half peak-to-peak amplitudes during startup
data/transient/steady-state.csv | transient waveform | calculated from ngspice transient run | Final six cycles with each node's DC level removed
data/transient/measurements.csv | transient summary | calculated from steady-state.csv | DC levels RF peak amplitudes ratios and gains
figures/rack-tuning.png | figure | generated from retained AC CSVs | Passband motion and gain at 3.500 MHz versus rack setting
figures/signal-walk.png | figure | generated from retained transient CSVs | Startup envelope and final ANT gate drain and OUT waveforms

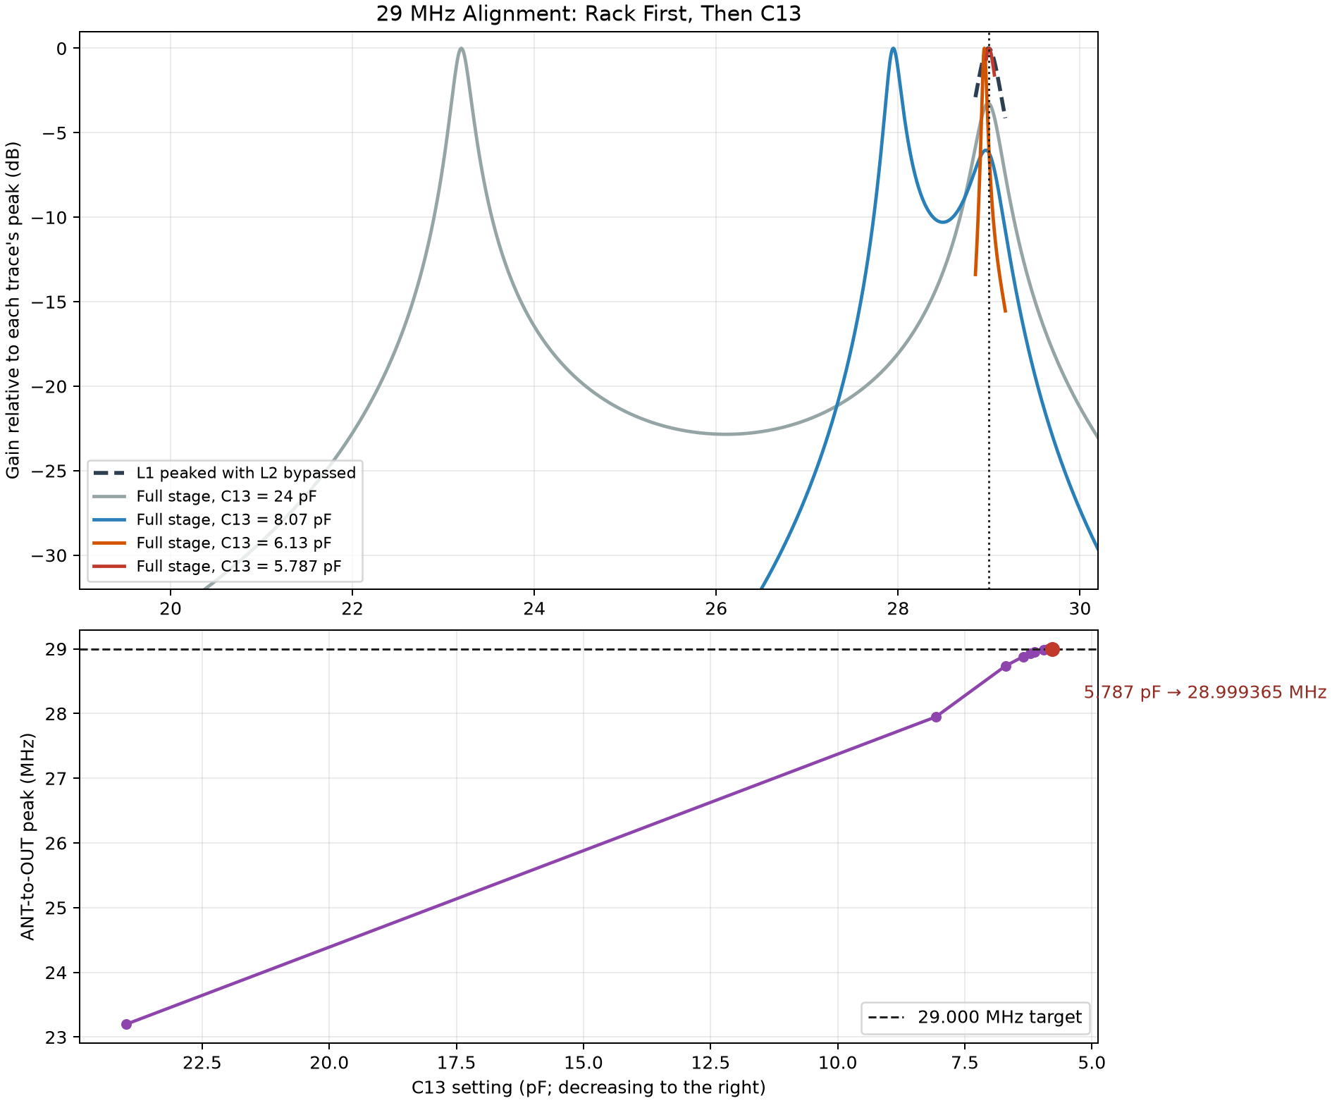
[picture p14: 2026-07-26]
spice/studies/80166/manual-alignment/figures/29mhz-adjustment.png

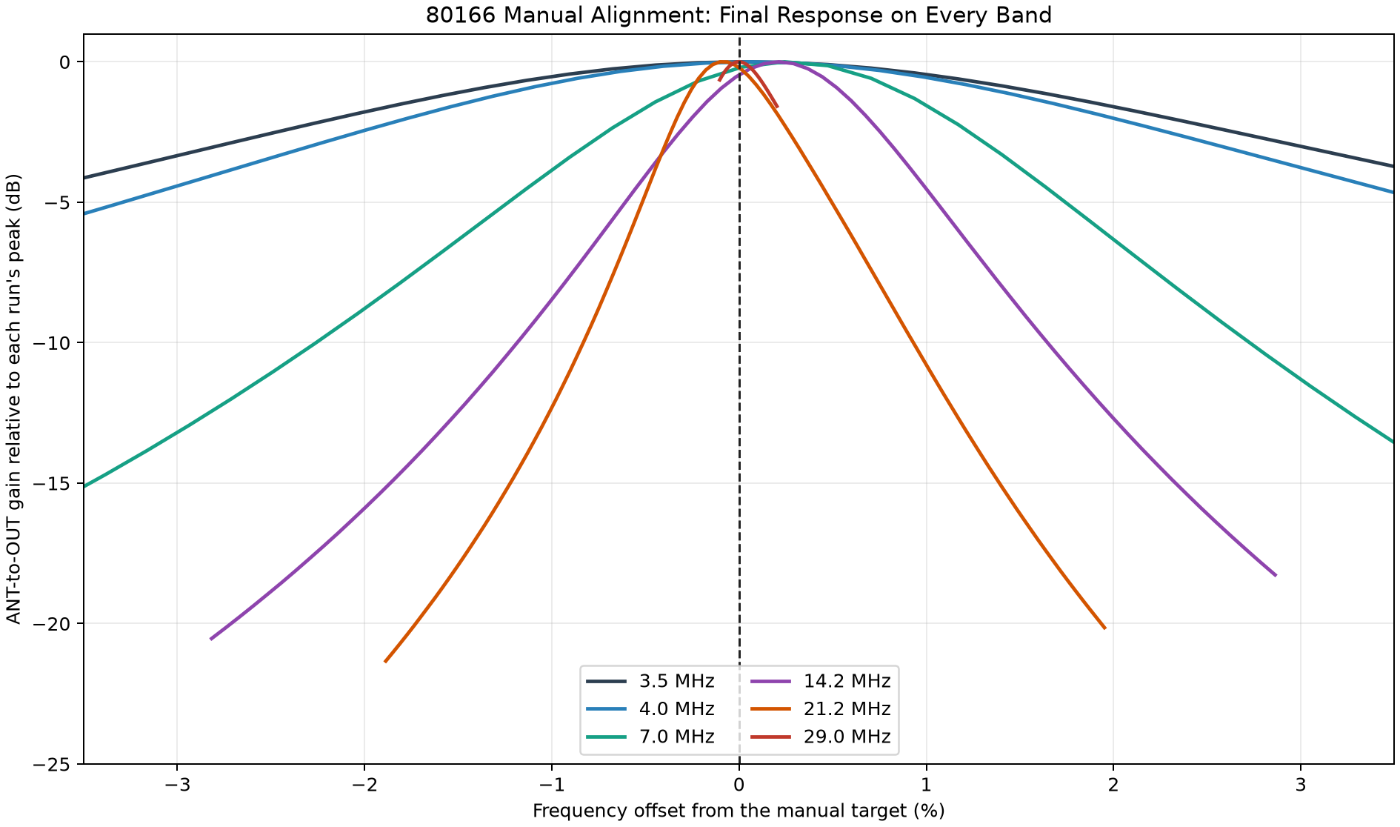
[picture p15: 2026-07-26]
spice/studies/80166/manual-alignment/figures/all-bands.png

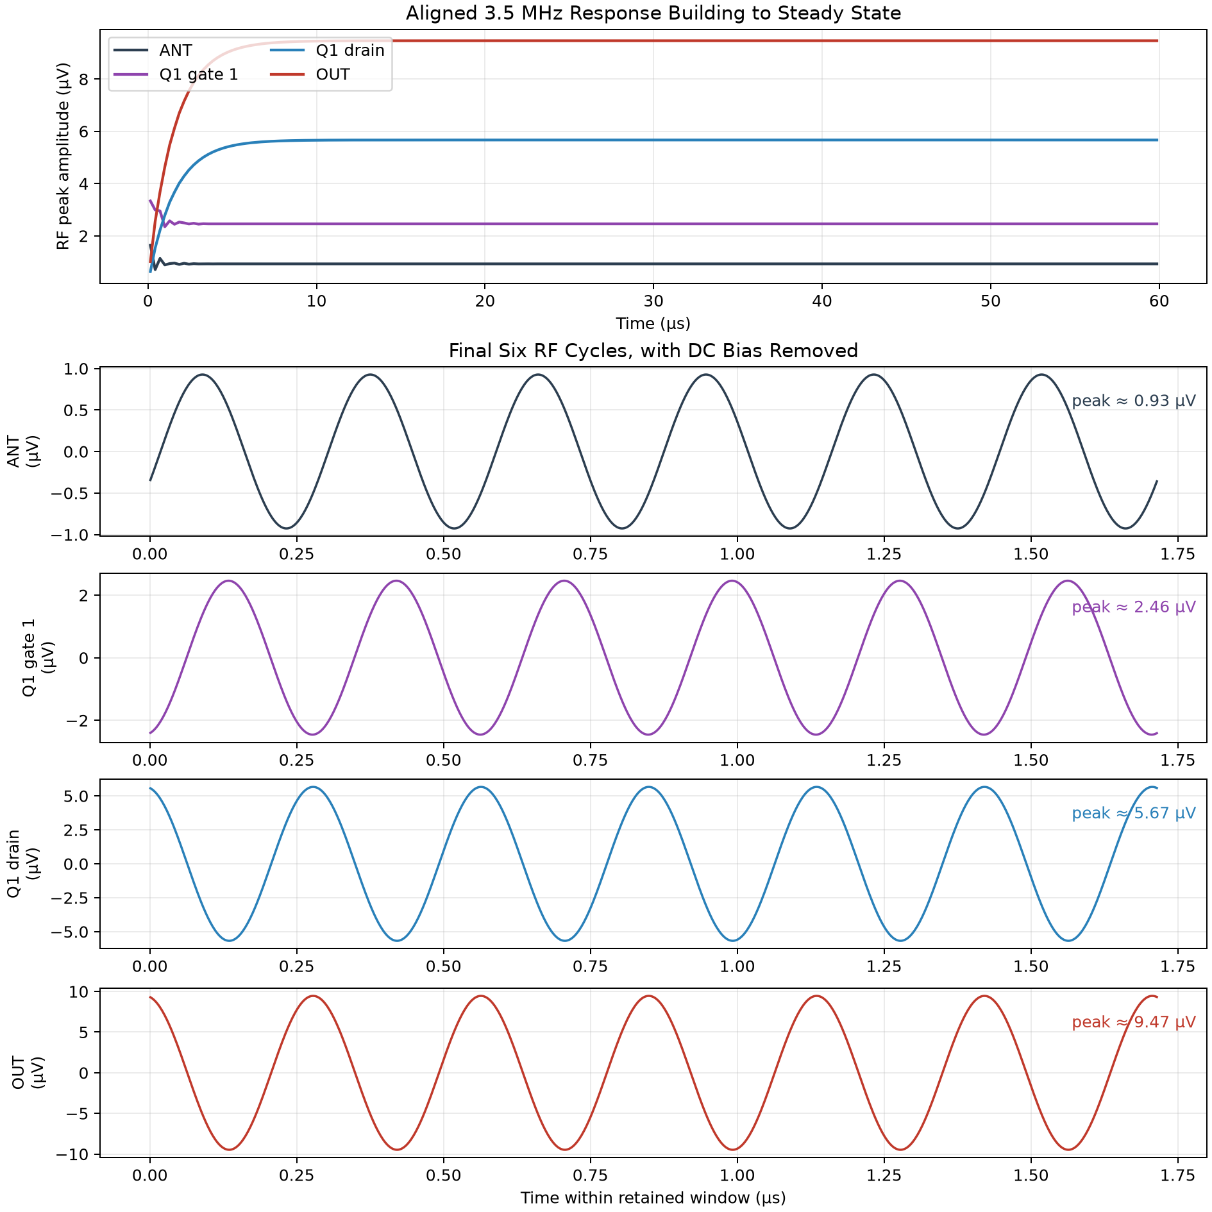
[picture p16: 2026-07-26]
spice/studies/80166/operation-3p5mhz/figures/signal-walk.png

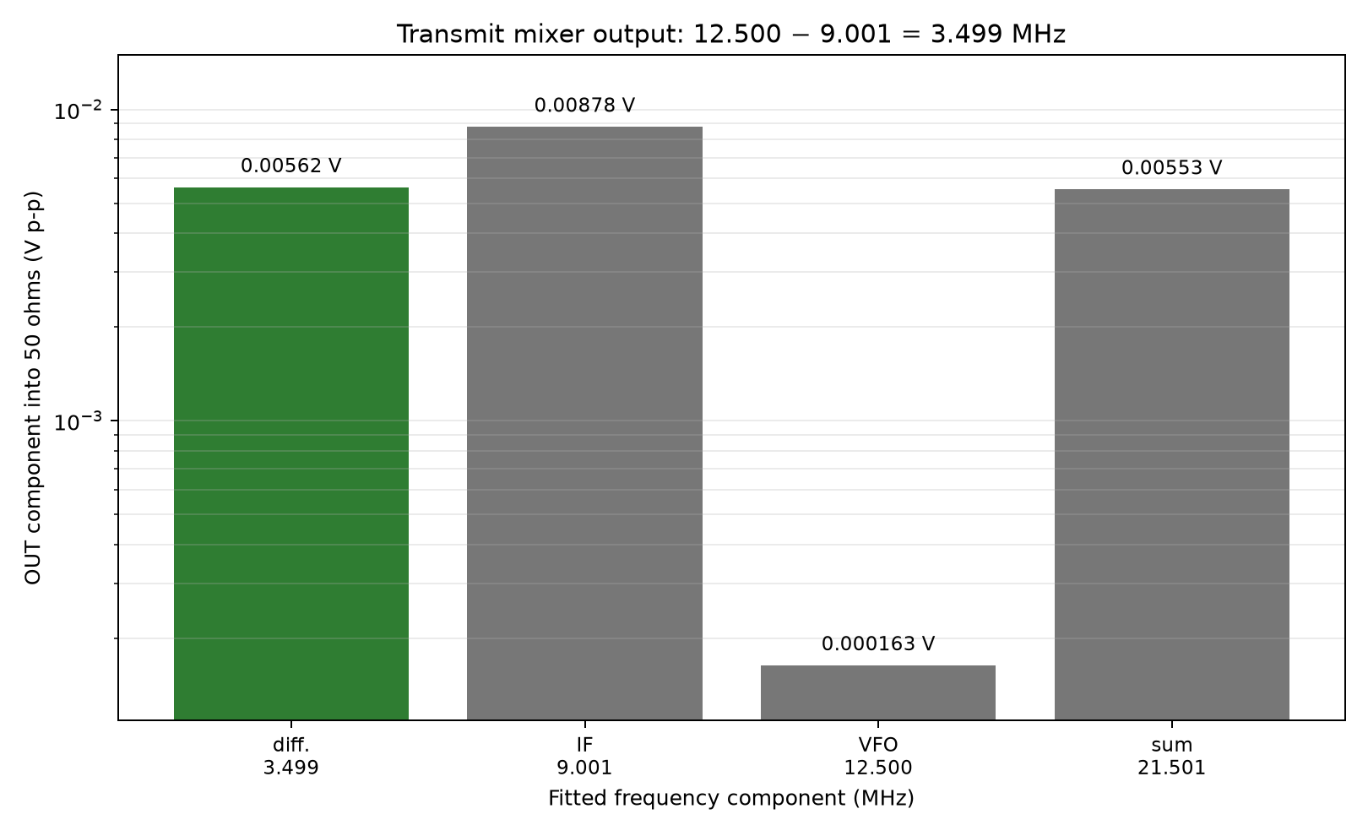
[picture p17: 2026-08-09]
spice/studies/80287/operation-3p5mhz/figures/80287-transmit-mixing-products.png

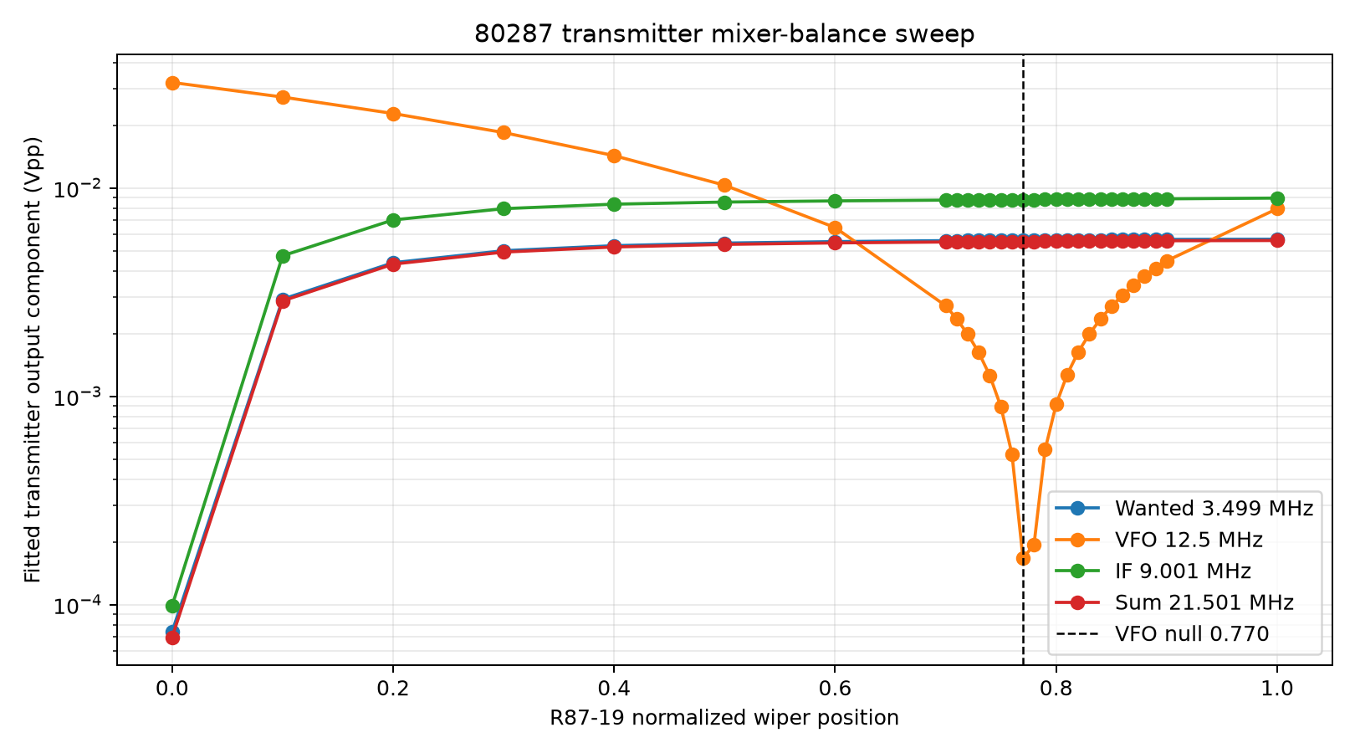
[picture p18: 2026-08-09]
spice/studies/80287/operation-3p5mhz/figures/80287-r87-19-tx-balance.png

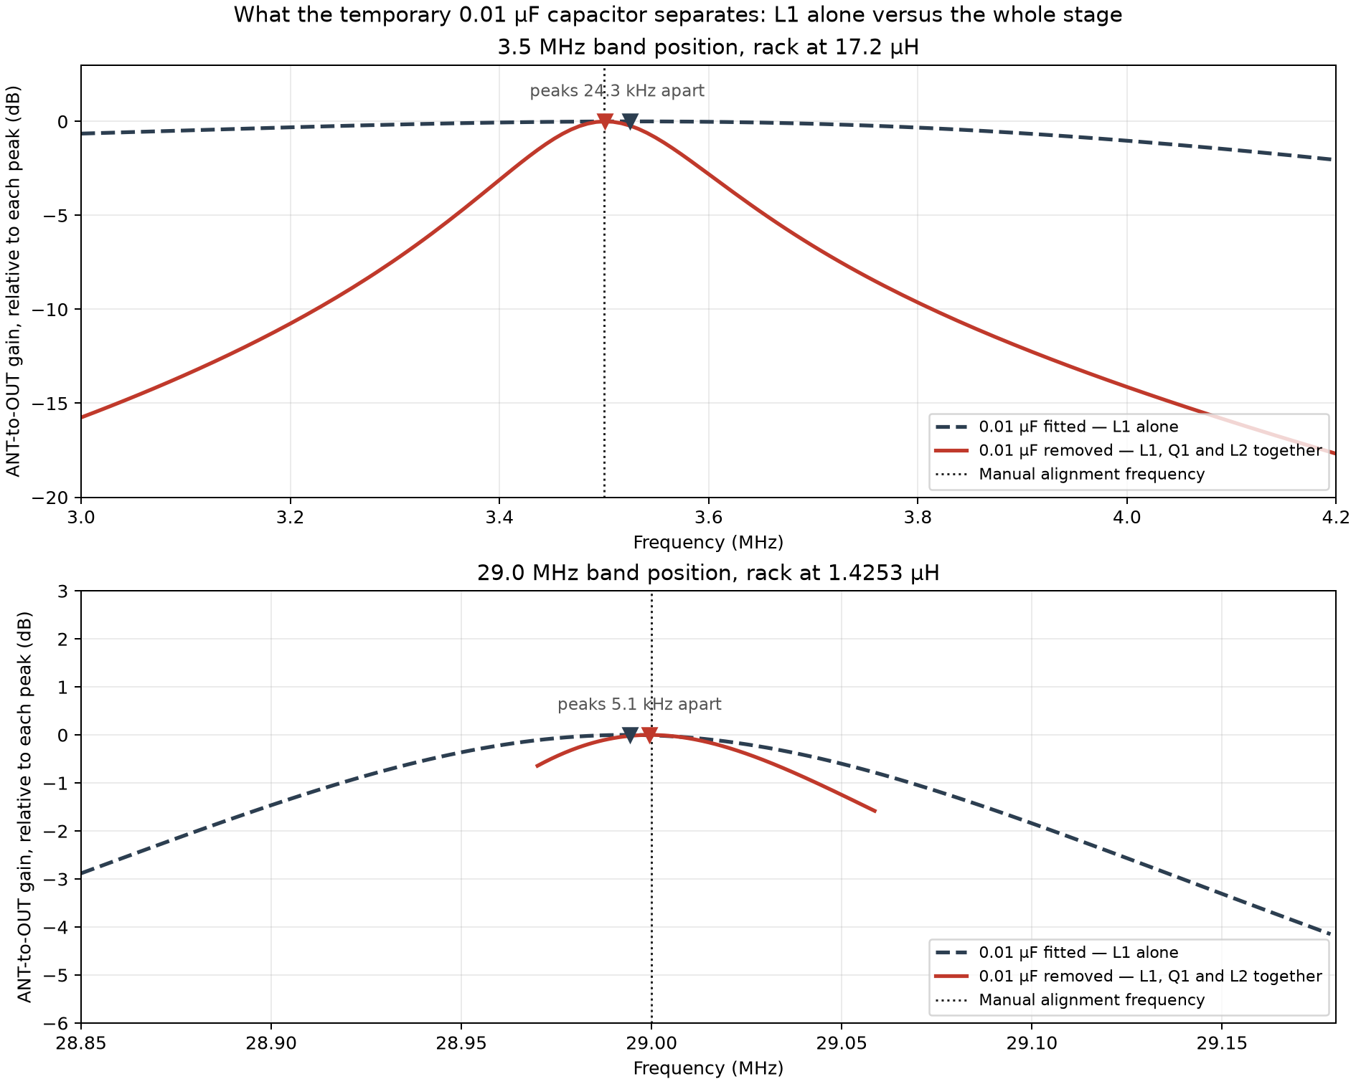
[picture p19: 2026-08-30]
spice/studies/80166/manual-alignment/figures/alignment-split.png

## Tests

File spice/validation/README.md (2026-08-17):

# Model validation circuits

These fixtures check model syntax and basic behavior independently of the
complete Triton schematic.

| Circuit | Purpose |
|:--|:--|
| `MC1747_validation.cir` | Both amplifier sections, separate VCC pins, DC followers, bandwidth, and slew rate |
| `MC1496P_validation.cir` | DC bias and 3/13 MHz plus 10/20 MHz mixer products |
| `40823_validation.cir` | Gate-1 transfer, gate-2 control, and manual bias point |
| `80166_rf_magnetics_validation.cir` | L1/L2 continuity and 9 MHz trap response |
| `SW_Rotary_1x5_validation.cir` | All five switch positions |
| `SW_Rotary_4x5_validation.cir` | All four S89-1 wafers in all five positions |
| `SW_Rotary_1x4_validation.cir` | All four S5 ten-meter segment positions |
| `Potentiometer_Position_validation.cir` | Fixed-position linear-pot wiper division |
| `MV2201_validation.cir` | Reverse-bias capacitance at four control voltages |
| `2N5486_validation.cir` | IDSS, cutoff trend, and Q89-1 source-follower bias |
| `MPS6514_validation.cir` | Q89-2 and Q89-4 documented bias points |
| `MPS6512_validation.cir` | Datasheet gain bin and Q89-5 nominal DC bias |
| `1N4154_validation.cir` | D89-1 forward clamp and reverse capacitance |
| `80279_device_models_validation.cir` | MPS3693 nominal gain/bias and HP 5082-3379 current-controlled impedance at 9 MHz |
| `80289_vfo_magnetics_validation.cir` | PTO/L4 estimates, T1 transfer/syntax sanity, and 1 mH RFC |

Run them from this directory so their relative model paths resolve:

```powershell
New-Item -ItemType Directory -Force ..\generated\validation | Out-Null
& 'C:\Tools\ngspice-46\Spice64\bin\ngspice_con.exe' -b -D ngbehavior=ltpsa MC1747_validation.cir
& 'C:\Tools\ngspice-46\Spice64\bin\ngspice_con.exe' -b -D ngbehavior=ltpsa MC1496P_validation.cir
& 'C:\Tools\ngspice-46\Spice64\bin\ngspice_con.exe' -b -D ngbehavior=ltpsa 40823_validation.cir
& 'C:\Tools\ngspice-46\Spice64\bin\ngspice_con.exe' -b -D ngbehavior=ltpsa 80166_rf_magnetics_validation.cir
& 'C:\Tools\ngspice-46\Spice64\bin\ngspice_con.exe' -b -D ngbehavior=ltpsa SW_Rotary_1x5_validation.cir
& 'C:\Tools\ngspice-46\Spice64\bin\ngspice_con.exe' -b -D ngbehavior=ltpsa SW_Rotary_4x5_validation.cir
& 'C:\Tools\ngspice-46\Spice64\bin\ngspice_con.exe' -b -D ngbehavior=ltpsa SW_Rotary_1x4_validation.cir
& 'C:\Tools\ngspice-46\Spice64\bin\ngspice_con.exe' -b -D ngbehavior=ltpsa Potentiometer_Position_validation.cir
& 'C:\Tools\ngspice-46\Spice64\bin\ngspice_con.exe' -b -D ngbehavior=ltpsa MV2201_validation.cir
& 'C:\Tools\ngspice-46\Spice64\bin\ngspice_con.exe' -b -D ngbehavior=ltpsa 2N5486_validation.cir
& 'C:\Tools\ngspice-46\Spice64\bin\ngspice_con.exe' -b -D ngbehavior=ltpsa MPS6514_validation.cir
& 'C:\Tools\ngspice-46\Spice64\bin\ngspice_con.exe' -b -D ngbehavior=ltpsa MPS6512_validation.cir
& 'C:\Tools\ngspice-46\Spice64\bin\ngspice_con.exe' -b -D ngbehavior=ltpsa 1N4154_validation.cir
& 'C:\Tools\ngspice-46\Spice64\bin\ngspice_con.exe' -b -D ngbehavior=ltpsa 80279_device_models_validation.cir
& 'C:\Tools\ngspice-46\Spice64\bin\ngspice_con.exe' -b -D ngbehavior=ltpsa 80289_vfo_magnetics_validation.cir
```

Any CSVs created by the validation circuits go to
`spice/generated/validation/` and are not versioned.

The board-level MC1496 DC regression is a Python runner rather than a
standalone `.cir` fixture because the KiCad hierarchy is the 80287 circuit
source of truth. From the project root run:

```powershell
python spice\tools\run_mc1496_dc_regression.py
```

It writes the curated comparison to
`spice/studies/80287/dc-regression/data/`.

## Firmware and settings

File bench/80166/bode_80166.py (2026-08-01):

#!/usr/bin/env python3
"""Stepped-sine frequency response of the Ten-Tec 540 80166 receiver rf amplifier.

Drives the transceiver antenna jack with a Siglent SDG1032X and measures the
input/output amplitude ratio with a Siglent SDS1202X-E, one frequency at a time.
This is a software equivalent of the scope's built-in Bode Plot function; doing
it in Python keeps the raw per-point data so the L1-only and composite sweeps can
be overlaid afterwards.

Two sweeps make up a tracking check on 80 m (manual p. 3-8):

    l1-only     .01 uF fitted from the 3.5 MHz trimmer terminal to chassis,
                which swamps L2 and leaves L1 setting the response
    composite   .01 uF removed, so the curve is L1 x Q1 x L2

See README.md in this directory for connections and the run order.
"""

from __future__ import annotations

import argparse
import csv
import datetime as dt
import math
import re
import socket
import statistics
import sys
import time
from pathlib import Path

DEFAULT_SCOPE = "192.168.1.157"
DEFAULT_GEN = "192.168.1.158"

# SDS1202X-E vertical steps, probe-referred values are these scaled by attenuation.
VDIV_STEPS = [
    500e-6, 1e-3, 2e-3, 5e-3, 10e-3, 20e-3, 50e-3,
    0.1, 0.2, 0.5, 1.0, 2.0, 5.0, 10.0,
]

# Horizontal steps, as (seconds, SCPI token).
TDIV_STEPS = []
for _decade, _suffix in ((1e-9, "NS"), (1e-6, "US"), (1e-3, "MS"), (1.0, "S")):
    for _mant in (1, 2, 5, 10, 20, 50, 100, 200, 500):
        TDIV_STEPS.append((_mant * _decade, f"{_mant}{_suffix}"))
TDIV_STEPS = sorted(t for t in TDIV_STEPS if 1e-9 <= t[0] <= 50.0)

SCREEN_VDIVS = 8       # vertical divisions
SCREEN_HDIVS = 14      # horizontal divisions on the SDS1000X-E


# --------------------------------------------------------------------------- #
# transport
# --------------------------------------------------------------------------- #

class Link:
    """Minimal SCPI link, either VXI-11 (via pyvisa-py) or a raw TCP socket."""

    def __init__(self, host: str, transport: str = "vxi11",
                 port: int | None = None, timeout: float = 5.0):
        self.host = host
        self.transport = transport
        self._sock = None
        self._res = None

        if transport == "vxi11":
            try:
                import pyvisa
            except ImportError:  # pragma: no cover - environment dependent
                raise SystemExit(
                    "pyvisa is required for --transport vxi11.\n"
                    "    python -m pip install pyvisa pyvisa-py"
                )
            rm = pyvisa.ResourceManager("@py")
            self._res = rm.open_resource(f"TCPIP0::{host}::INSTR")
            self._res.timeout = int(timeout * 1000)
            self._res.read_termination = "\n"
            self._res.write_termination = "\n"
        elif transport == "socket":
            self._sock = socket.create_connection((host, port), timeout=timeout)
            self._sock.settimeout(timeout)
        else:
            raise ValueError(f"unknown transport {transport!r}")

    def write(self, cmd: str) -> None:
        if self._res is not None:
            self._res.write(cmd)
        else:
            self._sock.sendall((cmd + "\n").encode("ascii"))

    def query(self, cmd: str) -> str:
        if self._res is not None:
            return self._res.query(cmd).strip()
        self.write(cmd)
        buf = b""
        while not buf.endswith(b"\n"):
            chunk = self._sock.recv(4096)
            if not chunk:
                break
            buf += chunk
        return buf.decode("ascii", "replace").strip()

    def close(self) -> None:
        try:
            if self._res is not None:
                self._res.close()
            elif self._sock is not None:
                self._sock.close()
        except Exception:
            pass


_NUM_RE = re.compile(r"[-+]?\d*\.?\d+(?:[eE][-+]?\d+)?")


def parse_number(text: str) -> float:
    """Pull the first float out of a Siglent reply such as '3.00E-02V'."""
    m = _NUM_RE.search(text)
    if not m:
        raise ValueError(f"no number in reply {text!r}")
    return float(m.group(0))


def nearest_step(value: float, steps) -> float:
    return min(steps, key=lambda s: abs(math.log10(s / value)) if value > 0 else s)


def vdiv_token(volts: float) -> str:
    if volts < 1e-3:
        return f"{round(volts * 1e6)}UV"
    if volts < 1.0:
        return f"{round(volts * 1e3)}MV"
    return f"{round(volts)}V"


# --------------------------------------------------------------------------- #
# instruments
# --------------------------------------------------------------------------- #

class Generator:
    """Siglent SDG1032X, channel 1."""

    def __init__(self, link: Link, channel: int = 1, load: str = "50"):
        self.link = link
        self.ch = f"C{channel}"
        self.load = load

    def idn(self) -> str:
        return self.link.query("*IDN?")

    def configure(self, freq: float, amplitude_vpp: float) -> None:
        for state in ("SWWV", "MDWV", "BTWV"):
            try:
                self.link.write(f"{self.ch}:{state} STATE,OFF")
            except Exception:
                pass
        self.link.write(f"{self.ch}:OUTP LOAD,{self.load}")
        self.link.write(
            f"{self.ch}:BSWV WVTP,SINE,FRQ,{freq:.6f},AMP,{amplitude_vpp:.6f},OFST,0"
        )

    def set_frequency(self, freq: float) -> None:
        self.link.write(f"{self.ch}:BSWV FRQ,{freq:.6f}")

    def set_amplitude(self, amplitude_vpp: float) -> None:
        self.link.write(f"{self.ch}:BSWV AMP,{amplitude_vpp:.6f}")

    def output(self, on: bool) -> None:
        self.link.write(f"{self.ch}:OUTP {'ON' if on else 'OFF'}")


class Scope:
    """Siglent SDS1202X-E."""

    def __init__(self, link: Link, avg_count: int = 16, bwl: bool = True):
        self.link = link
        self.avg_count = avg_count
        self.bwl = bwl
        self.averaging = False
        self._vdiv = {1: None, 2: None}
        self._attn = {1: 1.0, 2: 10.0}

    def idn(self) -> str:
        return self.link.query("*IDN?")

    def configure(self, ch1_attn: float, ch2_attn: float) -> None:
        self._attn = {1: ch1_attn, 2: ch2_attn}
        self.link.write("CHDR OFF")           # bare numeric replies
        for ch, attn in self._attn.items():
            self.link.write(f"C{ch}:TRA ON")
            self.link.write(f"C{ch}:CPL A1M")  # ac coupled, 1 Mohm
            self.link.write(f"C{ch}:ATTN {attn:g}")
            self.link.write(f"C{ch}:OFST 0V")
        self.link.write(f"BWL C1,{'ON' if self.bwl else 'OFF'},"
                        f"C2,{'ON' if self.bwl else 'OFF'}")
        self.link.write("TRSE EDGE,SR,C1,HT,OFF")
        self.link.write("C1:TRCP AC")
        self.link.write("C1:TRLV 0V")
        self.link.write("TRSL POS")
        self.link.write("TRMD NORM")
        if self.avg_count > 1:
            try:
                self.link.write(f"ACQW AVERAGE,{self.avg_count}")
                self.averaging = True
            except Exception:
                self.link.write("ACQW SAMPLING")
        else:
            self.link.write("ACQW SAMPLING")

    def set_timebase_for(self, freq: float, cycles: int = 10) -> float:
        target = (cycles / freq) / SCREEN_HDIVS
        value, token = min(TDIV_STEPS, key=lambda s: abs(math.log10(s[0] / target)))
        self.link.write(f"TDIV {token}")
        return value

    def set_vdiv(self, ch: int, volts_per_div: float) -> None:
        allowed = [s * self._attn[ch] for s in VDIV_STEPS]
        chosen = nearest_step(volts_per_div, allowed)
        if self._vdiv[ch] != chosen:
            self.link.write(f"C{ch}:VDIV {vdiv_token(chosen)}")
            self._vdiv[ch] = chosen
            time.sleep(0.05)

    def clear_sweeps(self) -> None:
        if self.averaging:
            try:
                self.link.write("CLSW")
            except Exception:
                pass

    def read_vpp(self, ch: int, reads: int = 3) -> float:
        vals = []
        for _ in range(reads):
            try:
                raw = self.link.query(f"C{ch}:PAVA? PKPK")
                v = parse_number(raw)
            except Exception:
                continue
            if 0.0 < v < 1e30:
                vals.append(v)
            time.sleep(0.02)
        if not vals:
            return float("nan")
        return statistics.median(vals)

    def autorange(self, ch: int, settle: float = 0.2, tries: int = 4) -> float:
        """Read Vpp, adjusting V/div until it fills a sane part of the screen."""
        floor = VDIV_STEPS[0] * self._attn[ch]
        for _ in range(tries):
            vpp = self.read_vpp(ch)
            vdiv = self._vdiv[ch] or floor
            if math.isnan(vpp) or vpp <= 0:
                # nothing measurable: go more sensitive, or give up at the floor
                if vdiv <= floor * 1.001:
                    return float("nan")
                self.set_vdiv(ch, vdiv / 5)
                self.clear_sweeps()
                time.sleep(settle)
                continue
            span = vpp / vdiv  # divisions occupied
            if 2.5 <= span <= 6.5:
                return vpp
            self.set_vdiv(ch, vpp / 4.5)
            if self._vdiv[ch] == vdiv:
                return vpp  # already at a rail of the V/div range
            self.clear_sweeps()
            time.sleep(settle)
        return self.read_vpp(ch)


# --------------------------------------------------------------------------- #
# sweep
# --------------------------------------------------------------------------- #

def frequencies(start: float, stop: float, points: int, log: bool):
    if points < 2:
        return [start]
    if log:
        a, b = math.log10(start), math.log10(stop)
        return [10 ** (a + (b - a) * i / (points - 1)) for i in range(points)]
    return [start + (stop - start) * i / (points - 1) for i in range(points)]


def measure_point(gen: Generator, scope: Scope, freq: float,
                  settle: float, avg_wait: float):
    gen.set_frequency(freq)
    time.sleep(settle)
    scope.clear_sweeps()
    time.sleep(avg_wait)
    ch1 = scope.autorange(1)
    ch2 = scope.autorange(2)
    if math.isnan(ch1) or math.isnan(ch2) or ch1 <= 0 or ch2 <= 0:
        gain = float("nan")
    else:
        gain = 20 * math.log10(ch2 / ch1)
    return ch1, ch2, gain


def linearity_check(gen: Generator, scope: Scope, freq: float,
                    amplitude: float, settle: float, avg_wait: float) -> str:
    """Compare gain at full and half drive; a real difference means compression."""
    gen.set_amplitude(amplitude)
    _, _, g_full = measure_point(gen, scope, freq, settle, avg_wait)
    gen.set_amplitude(amplitude / 2)
    _, _, g_half = measure_point(gen, scope, freq, settle, avg_wait)
    gen.set_amplitude(amplitude)
    time.sleep(settle)
    if math.isnan(g_full) or math.isnan(g_half):
        return "inconclusive (a level was unmeasurable)"
    delta = g_full - g_half
    verdict = "linear" if abs(delta) <= 0.5 else "COMPRESSING - reduce --amplitude"
    return (f"{verdict}: {g_full:.2f} dB at {amplitude*1e3:.1f} mVpp vs "
            f"{g_half:.2f} dB at {amplitude*1e3/2:.1f} mVpp "
            f"(delta {delta:+.2f} dB)")


def main(argv=None) -> int:
    p = argparse.ArgumentParser(
        description="Stepped-sine frequency response of the 540 80166 rf amplifier.",
        formatter_class=argparse.ArgumentDefaultsHelpFormatter,
    )
    p.add_argument("--label", required=True,
                   help="run name, normally 'l1-only' or 'composite'")
    p.add_argument("--scope", default=DEFAULT_SCOPE, help="SDS1202X-E address")
    p.add_argument("--gen", default=DEFAULT_GEN, help="SDG1032X address")
    p.add_argument("--transport", choices=("vxi11", "socket"), default="vxi11")
    p.add_argument("--scope-port", type=int, default=5025,
                   help="raw socket port, --transport socket only")
    p.add_argument("--gen-port", type=int, default=5024,
                   help="raw socket port, --transport socket only")
    p.add_argument("--start", type=float, default=3.0e6, help="sweep start, Hz")
    p.add_argument("--stop", type=float, default=4.5e6, help="sweep stop, Hz")
    p.add_argument("--points", type=int, default=151)
    p.add_argument("--log-sweep", action="store_true",
                   help="log frequency spacing instead of linear")
    p.add_argument("--amplitude", type=float, default=0.010,
                   help="generator drive, Vpp into a 50 ohm load setting")
    p.add_argument("--ch1-attn", type=float, default=1.0,
                   help="CH1 probe factor (1 for a direct coax feed)")
    p.add_argument("--ch2-attn", type=float, default=10.0,
                   help="CH2 probe factor (10 for a x10 probe)")
    p.add_argument("--avg-count", type=int, default=16,
                   help="scope acquisition averages, 1 disables averaging")
    p.add_argument("--settle", type=float, default=0.25,
                   help="seconds after a frequency change")
    p.add_argument("--avg-wait", type=float, default=0.35,
                   help="extra seconds for the average to converge")
    p.add_argument("--no-bwl", action="store_true",
                   help="disable the scope 20 MHz bandwidth limit")
    p.add_argument("--no-linearity-check", action="store_true")
    p.add_argument("--note", default="",
                   help="free text recorded in the csv header, e.g. RESONATE position")
    p.add_argument("--out-dir", default=str(Path(__file__).parent / "data"))
    args = p.parse_args(argv)

    out_dir = Path(args.out_dir)
    out_dir.mkdir(parents=True, exist_ok=True)
    stamp = dt.datetime.now().strftime("%Y%m%d-%H%M%S")
    out_path = out_dir / f"80166-80m-{args.label}-{stamp}.csv"

    print(f"connecting to generator {args.gen} and scope {args.scope} "
          f"over {args.transport}")
    gen_link = Link(args.gen, args.transport, args.gen_port)
    scope_link = Link(args.scope, args.transport, args.scope_port)
    gen = Generator(gen_link)
    scope = Scope(scope_link, avg_count=args.avg_count, bwl=not args.no_bwl)

    try:
        gen_idn = gen.idn()
        scope_idn = scope.idn()
        print(f"  generator: {gen_idn}")
        print(f"  scope    : {scope_idn}")

        centre = math.sqrt(args.start * args.stop)
        scope.configure(args.ch1_attn, args.ch2_attn)
        tdiv = scope.set_timebase_for(centre)
        print(f"  timebase : {tdiv*1e9:.0f} ns/div "
              f"({centre/1e6:.3f} MHz reference)")

        # noise floor on the output channel with no drive applied
        gen.output(False)
        time.sleep(0.4)
        scope.set_vdiv(2, VDIV_STEPS[0] * args.ch2_attn)
        scope.link.write("TRMD AUTO")
        scope.clear_sweeps()
        time.sleep(0.5)
        noise_vpp = scope.read_vpp(2)
        scope.link.write("TRMD NORM")
        print(f"  ch2 noise: {noise_vpp*1e3:.2f} mVpp with the output off")

        gen.configure(centre, args.amplitude)
        gen.output(True)
        time.sleep(0.5)
        scope.set_vdiv(1, args.amplitude / 4.5)
        scope.autorange(1)
        scope.autorange(2)

        lin = ""
        if not args.no_linearity_check:
            lin = linearity_check(gen, scope, centre, args.amplitude,
                                  args.settle, args.avg_wait)
            print(f"  linearity: {lin}")

        freqs = frequencies(args.start, args.stop, args.points, args.log_sweep)
        rows = []
        t0 = time.time()
        for i, f in enumerate(freqs, 1):
            ch1, ch2, gain = measure_point(gen, scope, f, args.settle, args.avg_wait)
            rows.append((f, ch1, ch2, gain))
            print(f"  [{i:3d}/{len(freqs)}] {f/1e6:7.4f} MHz  "
                  f"in {ch1*1e3:7.3f} mVpp  out {ch2*1e3:8.3f} mVpp  "
                  f"gain {gain:7.2f} dB")
    finally:
        try:
            gen.output(False)
        except Exception:
            pass
        gen_link.close()
        scope_link.close()

    valid = [r for r in rows if not math.isnan(r[3])]
    peak = max(valid, key=lambda r: r[3]) if valid else None

    with out_path.open("w", newline="", encoding="utf-8") as fh:
        fh.write("# Ten-Tec 540 - 80166 rf amplifier stepped-sine response\n")
        fh.write(f"# label,{args.label}\n")
        fh.write(f"# timestamp,{dt.datetime.now().isoformat(timespec='seconds')}\n")
        fh.write(f"# scope,{scope_idn}\n")
        fh.write(f"# generator,{gen_idn}\n")
        fh.write(f"# drive_vpp,{args.amplitude}\n")
        fh.write(f"# start_hz,{args.start}\n")
        fh.write(f"# stop_hz,{args.stop}\n")
        fh.write(f"# points,{args.points}\n")
        fh.write(f"# sweep,{'log' if args.log_sweep else 'linear'}\n")
        fh.write(f"# ch1_attn,{args.ch1_attn}\n")
        fh.write(f"# ch2_attn,{args.ch2_attn}\n")
        fh.write(f"# avg_count,{args.avg_count}\n")
        fh.write(f"# ch2_noise_vpp,{noise_vpp:.6g}\n")
        fh.write(f"# linearity,{lin}\n")
        fh.write(f"# note,{args.note}\n")
        w = csv.writer(fh)
        w.writerow(["frequency_hz", "ch1_vpp", "ch2_vpp", "gain_db"])
        for f, ch1, ch2, gain in rows:
            w.writerow([f"{f:.1f}", f"{ch1:.6g}", f"{ch2:.6g}", f"{gain:.4f}"])

    print(f"\nwrote {out_path}")
    if peak:
        print(f"peak {peak[3]:.2f} dB at {peak[0]/1e6:.4f} MHz")
    return 0


if __name__ == "__main__":
    sys.exit(main())

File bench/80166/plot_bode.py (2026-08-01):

#!/usr/bin/env python3
"""Plot and compare 80166 rf amplifier sweeps captured by bode_80166.py.

    python plot_bode.py data/80166-80m-l1-only-*.csv data/80166-80m-composite-*.csv \
        -o plots/80166-80m-tracking.png

Overlays each sweep, marks the 3.5 and 4.0 MHz alignment points, and reports
peak frequency, -3 dB bandwidth and loaded Q for each curve.
"""

from __future__ import annotations

import argparse
import csv
import math
from pathlib import Path

import matplotlib
matplotlib.use("Agg")
import matplotlib.pyplot as plt  # noqa: E402

ALIGNMENT_POINTS = (3.5e6, 4.0e6)


def read_sweep(path: Path):
    meta, freqs, gains = {}, [], []
    with path.open(encoding="utf-8") as fh:
        rows = []
        for line in fh:
            if line.startswith("#"):
                parts = line[1:].strip().split(",", 1)
                if len(parts) == 2:
                    meta[parts[0].strip()] = parts[1].strip()
                continue
            rows.append(line)
    reader = csv.DictReader(rows)
    for r in reader:
        try:
            g = float(r["gain_db"])
        except (TypeError, ValueError):
            continue
        if math.isnan(g):
            continue
        freqs.append(float(r["frequency_hz"]))
        gains.append(g)
    meta.setdefault("label", path.stem)
    return meta, freqs, gains


def interp_crossing(freqs, gains, level, lo, hi, direction):
    """Frequency where the curve crosses `level`, searching outward from the peak."""
    rng = range(lo, hi) if direction > 0 else range(lo, hi, -1)
    for i in rng:
        j = i + direction
        if j < 0 or j >= len(gains):
            break
        if (gains[i] - level) * (gains[j] - level) <= 0 and gains[i] != gains[j]:
            t = (level - gains[i]) / (gains[j] - gains[i])
            return freqs[i] + t * (freqs[j] - freqs[i])
    return None


def summarise(freqs, gains):
    pk = max(range(len(gains)), key=lambda i: gains[i])
    f_pk, g_pk = freqs[pk], gains[pk]
    lo = interp_crossing(freqs, gains, g_pk - 3.0, pk, 0, -1)
    hi = interp_crossing(freqs, gains, g_pk - 3.0, pk, len(gains), +1)
    bw = hi - lo if (lo and hi) else None
    q = f_pk / bw if bw else None
    at = {}
    for target in ALIGNMENT_POINTS:
        i = min(range(len(freqs)), key=lambda k: abs(freqs[k] - target))
        at[target] = gains[i]
    return {"f_peak": f_pk, "g_peak": g_pk, "f_lo": lo, "f_hi": hi,
            "bw": bw, "q": q, "at": at}


def main(argv=None) -> int:
    p = argparse.ArgumentParser(description=__doc__,
                                formatter_class=argparse.RawDescriptionHelpFormatter)
    p.add_argument("csv", nargs="+", type=Path)
    p.add_argument("-o", "--output", type=Path,
                   default=Path(__file__).parent / "plots" / "80166-80m-tracking.png")
    p.add_argument("--normalize", action="store_true",
                   help="shift each curve so its peak sits at 0 dB")
    p.add_argument("--title", default="Ten-Tec 540 - 80166 rf amplifier, 80 m response")
    p.add_argument("--dpi", type=int, default=140)
    args = p.parse_args(argv)

    args.output.parent.mkdir(parents=True, exist_ok=True)
    fig, ax = plt.subplots(figsize=(9.5, 5.4))

    lines = []
    for path in args.csv:
        meta, freqs, gains = read_sweep(path)
        if not freqs:
            print(f"{path}: no valid points, skipped")
            continue
        s = summarise(freqs, gains)
        offset = -s["g_peak"] if args.normalize else 0.0
        label = meta.get("label", path.stem)
        ax.plot([f / 1e6 for f in freqs], [g + offset for g in gains],
                lw=1.8, label=label)
        ax.plot(s["f_peak"] / 1e6, s["g_peak"] + offset, "o", ms=5,
                color=ax.lines[-1].get_color())
        lines.append((label, meta, s))

    for f in ALIGNMENT_POINTS:
        ax.axvline(f / 1e6, color="0.6", ls="--", lw=1.0, zorder=0)
        ax.annotate(f"{f/1e6:.1f} MHz", (f / 1e6, 0.985), xycoords=("data", "axes fraction"),
                    ha="center", va="top", fontsize=8, color="0.35")
    ax.axvspan(3.5, 4.0, color="0.9", zorder=-1)

    ax.set_xlabel("frequency (MHz)")
    ax.set_ylabel("normalised response (dB)" if args.normalize else "gain (dB)")
    ax.set_title(args.title)
    ax.grid(True, which="both", alpha=0.3)
    ax.legend(loc="best", frameon=False)
    fig.tight_layout()
    fig.savefig(args.output, dpi=args.dpi)
    print(f"wrote {args.output}")

    print()
    hdr = f"{'sweep':<14}{'peak MHz':>10}{'peak dB':>10}{'-3dB BW kHz':>13}{'Q':>7}" \
          f"{'3.5 MHz dB':>12}{'4.0 MHz dB':>12}"
    print(hdr)
    print("-" * len(hdr))
    for label, meta, s in lines:
        bw = f"{s['bw']/1e3:.1f}" if s["bw"] else "n/a"
        q = f"{s['q']:.1f}" if s["q"] else "n/a"
        print(f"{label:<14}{s['f_peak']/1e6:>10.4f}{s['g_peak']:>10.2f}"
              f"{bw:>13}{q:>7}"
              f"{s['at'][3.5e6]:>12.2f}{s['at'][4.0e6]:>12.2f}")

    if len(lines) >= 2:
        (la, _, sa), (lb, _, sb) = lines[0], lines[1]
        delta = (sb["f_peak"] - sa["f_peak"]) / 1e3
        print(f"\npeak offset {lb} - {la}: {delta:+.1f} kHz")

    return 0


if __name__ == "__main__":
    raise SystemExit(main())

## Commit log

2026-07-26 Release RF Amplifier 80166 schematic v0.1.0
    [14p2_aligned.csv, 14p2_l1-bypassed.csv, 21p2_aligned.csv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]
2026-07-28 first draft of vfo sheet
    [RF_Amp_80166.kicad_sch, VFO_80289.kicad_sch, triton_540.kicad_sch]
2026-07-31 Release VFO 80289 and mixer 80287 v0.2.0
    [80289-r89-2-balance-sweep.csv, 80289-r89-27-injection-sweep.csv, 80289-t1-coupling-sweep.csv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]
2026-07-31 Add README for Ten Tec Triton IV Model 540 schematic
2026-07-31 updates to topsheet
    [if-agc_80279.kicad_sch, triton_540.kicad_sch]
2026-08-01 Add bench sweep tooling for 80166 L1/L2 tracking check
    Measures the receiver rf amplifier frequency response on 80 m with a Siglent
    SDG1032X and SDS1202X-E over LAN, as a software equivalent of the scope's
    built-in Bode Plot that keeps the raw per-point data.
    Tracking is checked by taking two sweeps and overlaying them. The manual's
    alignment trick separates the two ganged coils: the .01 uF clipped from the
    3.5 MHz trimmer terminal to chassis shorts the trimmer across L2, so that
    sweep shows L1 alone, and the sweep without it shows L1 x Q1 x L2. The offset
    between the peaks is the tracking error. 80 m only, which is where the manual
    sets tracking (p. 3-8).
    bode_80166.py steps the generator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
    [bode_80166.py, plot_bode.py]
2026-08-01 Document the no-tee hookup for the 80166 sweep
    Generator on clip leads at the SO-239 centre lug with scope CH1 on short coax
    at the jack taps the same node as a BNC tee. Valid at 3.5 MHz, where a few
    inches of clip lead is about 2 ohms against a 50 ohm source, and explicitly
    not carried up to 28 MHz.
    Notes the one consequence that does not cancel between the two sweeps: the
    CH1 coax stub hangs its own capacitance on the antenna input, pulling L1 down
    slightly in both runs, so L2 gets aligned to a shifted L1. Estimated under
    10 kHz via the low-impedance tap on L1, against a response roughly 150 kHz
    wide, hence the short-cable instruction.
    Also tags code fences to match the repo convention.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
2026-08-01 Name the 3.5 MHz trimmer as C19 in the bench procedure
    80166.md already reconstructs the bandswitch capacitors and confirms the split
    the method depends on: fixed capacitors across L1, adjustable trimmers across
    L2. On 3.5 MHz the trimmer is C19 and the L1-side fixed capacitor is C12,
    620 pF. Naming the part beats "the 3.5 MHz trimmer terminal" at the bench, and
    cross-references the two documents.
2026-08-08 work on if-agc
    [if-agc_80279.kicad_sch, triton_540.kicad_sch]
2026-08-08 work on if agc again
    [VFO_80289.kicad_sch]
2026-08-09 Add TX-RX mixer simulations
    [80287-3p5mhz-measurements.csv, 80287-mc1496-dc-regression.csv, 80287-r87-1-rx-balance-sweep.csv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]
2026-08-17 Complete IF-AGC schematic and SPICE models
    [RF_Amp_80166.kicad_sch, VFO_80289.kicad_sch, if-agc_80279.kicad_sch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]
2026-08-18 sims 1-3 run on ig-agc
    [80279-dc-operating-point.csv, 80279-if-response-summary.csv, 80279-if-response.csv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]
2026-08-28 Complete 80279 IF-AGC simulations
    [80279-agc-envelope-timeline.csv, 80279-agc-summary.csv, 80279-audio-agc-summary.csv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]
2026-08-30 Organize board files by assembly number and remove dead files
    Give every discipline directory the assembly number as its second level so
    all of one board's material is reachable by number.
    Bench measurements move under bench/<assembly>/: the 80166 rf amplifier
    tracking procedure and its scripts, and the 80350 VFO mixer-balance result
    from measurements/, which now has one home instead of two. Add the data/ and
    plots/ directories the 80166 procedure documents but that did not exist, and
    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
2026-08-30 Extract board-independent ngspice helpers from the 80166 runner
    run_80166_headless.py was imported as "core" by eight runners belonging to
    other assemblies, so the 80287 and 80289 studies depended on a module named
    for the 80166. Eight of the nine importers used only parse_ascii_raw, which
    reads an ngspice ASCII raw file and knows nothing about any board.
    Move parse_ascii_raw and db_ratio to spice/tools/ngspice_raw.py and point
    every consumer at it. The 80166 runner keeps its name, because it genuinely
    is the 80166 command-line entry point: build_netlist edits S4_POS, L_RACK and
    the C99 fixture, and write_csv_and_summary reads the rf_amp_80166 nets. A
    rename of the whole module would have r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
2026-08-30 Rename sub-sheets by assembly number and clear the duplicate designator
    Give the four sub-sheets one filename convention, assembly number first, so
    each board's schematic sorts beside its document:
    RF_Amp_80166 -> 80166_rf_amp
    if-agc_80279 -> 80279_if_agc
    tx_rx_mixer_80287 -> 80287_tx_rx_mixer
    VFO_80289 -> 80289_vfo
    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
    [80166_rf_amp.kicad_sch, 80279_if_agc.kicad_sch, 80287_tx_rx_mixer.kicad_sch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]
2026-08-30 Label every figure Figure XX-Y
    Adopt a figure-numbering convention: XX is the last two digits of the assembly
    the document covers, Y is the figure's sequential position in that document.
    Record the rule in AGENTS.md and apply it to all 54 figures across the twelve
    documents that carry one.
    Each caption sits directly beneath its image and reuses the existing alt text
    as its description, so the alt text is preserved for readers who cannot see the
    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
2026-08-30 Number figures per assembly and cite them in the prose
    Assembly 79 carries 32 figure references but only 13 distinct images: eleven
    plots appear in two or three documents each. Numbering per document therefore
    gave one plot up to three different numbers, which defeats the purpose of a
    figure number.
    Number the image instead of the occurrence. One sequence now runs across every
    document covering an assembly, so a plot shown in both a board document and a
    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
2026-08-30 Link the 80166 RCA 40823 to its local datasheet
    The 80166 RF amplifier carries one active device, Q66-1, the RCA 40823
    dual-gate MOSFET; the sheet holds no integrated circuits and no diodes. Its
    datasheet was already archived as datasheets/RCA_40823_SC-15_1971.pdf, so
    nothing needed downloading, but the placed symbol's Datasheet field was empty.
    The triton_iv library symbol already pointed at the local file and the other
    40823 in the design, Q79-3 on the IF-AGC sheet, was linked correctly. Only the
    80166 instance was blank, because the sheet's cached lib_symbols copy predates
    the library change. Set the instance property to the same
    ${KIPRJMOD}/datasheets/RCA_40823_SC-15_1971.pdf path.
    The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
    [80166_rf_amp.kicad_sch]
2026-08-30 Record board-document rules and add the alignment-split figure
    These changes were already in the working tree; they are committed first so
    the simulation work that depends on them has a clean base.
    AGENTS.md gains the sections that govern how a board document is written: the
    hobbyist-restorer audience and the six questions every board document answers,
    what an alignment section must explain, the six-part structure for a simulation
    write-up, the requirement that every simulation carry a bench check with an
    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
2026-08-30 Repair and re-enable 80166 simulation in the shared schematic
    A fresh SPICE export contained no 80166 nets at all, and three separate faults
    had accumulated during later work on the other assemblies. All three are
    simulation-only; none of them affects the reconstruction of the circuit.
    Sheet selection. The root schematic can only usefully simulate one assembly at
    a time. RF_Amp_80166 is now included and IF-AGC_80279, VFO-80289 and
    TX RX Mixer 80287 are excluded. Running a study for one of those boards means
    reversing this. exclude_from_sim was also switched off on the 80166 sub-sheet's
    test fixture (V7, R66-99, R66-100, C66-101, V66-1, V66-2) and on the off-board
    bandswitch parts the tuned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
    [80166_rf_amp.kicad_sch, triton_540.kicad_sch]
2026-08-30 Add the four 80166 study runners and the helpers they needed
    Four new runners, one per study, each exporting a fresh netlist from
    triton_540.kicad_sch and writing only its own curated CSVs and figures:
    run_80166_defeat_gain.py DEFEAT gain reduction
    run_80166_rf_gain_supply.py RF GAIN as the stage's supply
    run_80166_trap_9mhz.py the 9 MHz trap
    run_80166_loading_sensitivity.py output loading and coil Q
    run_80166_headless.py keeps its role as the 80166's own netlist editor and
    gains what the new studies needed:
    - replace_source_dc, which sets an independent source's DC value without
    disturbing its AC card. The existing replace_component_value could not: a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
2026-08-30 Retain the evidence for 80166 simulations 4 to 7
    Four study directories, each with its README, manifest.csv recording the runs
    that were actually made, curated CSVs and figures.
    defeat-gain-control. /DEFEAT stepped 3.9 V to 0 V in the aligned 3.5 MHz state,
    seventeen AC sweeps and seventeen operating points. Gain falls 28.7 dB at a
    grounded DEFEAT line and passes the manual's 25 dB at about 0.25 V. The -3 dB
    bandwidth moves from 202.24 to 202.31 kHz and the peak does not move by one
    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
    [band-14p2-trapped.csv, band-14p2.csv, band-21p2-trapped.csv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]
2026-08-30 Write up 80166 simulations 4 to 7 in the board document
    The four entries under "Simulations still to be done" are replaced by finished
    sections in the six-part structure, each keeping its bench-check proposal with
    an empty results table marked "Not yet performed."
    Simulation 4, the DEFEAT gain reduction: pass. Simulation 5, RF GAIN as the
    stage's supply: pass, with the expectation about V_GS restated -- it is not
    monotonic, and the section explains why that is the circuit rather than a
    defect. Simulation 6, the 9 MHz trap: pass. Simulation 7, output loading and
    coil Q: partial pass, and the section says plainly what it does not establish.
    Simulation 7 opened two gaps in place of the four i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
2026-09-05 add 80274 audio power amplifier
    [80274_audio_power_amp.kicad_sch, triton_540.kicad_sch]
2026-11-13 Add 80308 crystal calibrator simulation
